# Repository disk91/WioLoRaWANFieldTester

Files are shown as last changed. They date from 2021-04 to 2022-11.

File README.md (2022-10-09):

# Wio Terminal LoRaWAN Field Tester

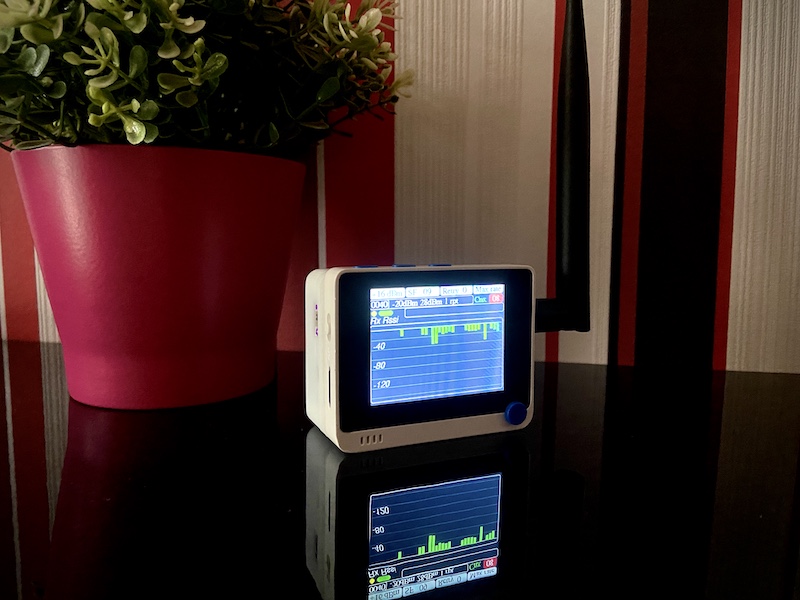
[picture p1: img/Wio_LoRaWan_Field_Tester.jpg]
LoRaWan tester


## What's is it about

When deploying a LoRaWAN network you want to know your gateway coverage and measure the radio performance in different places. When deploying Helium network you particularly want to know how many Hotspot around can be touched for a given position. Then you want to enrich the network mappers to know and share the real network coverage.

There are some existing tools for such application but the cost is about $200. The idea of this project is to propose a simple tool you can build on your own with low cost hardware to fulfil this purpose.

The solution is based on low cost products, easy to find for about $50:
- [Wio Terminal](https://wiki.seeedstudio.com/Wio-Terminal-Getting-Started/)
- [RFM95](https://www.disk91.com/2019/technology/lora/hoperf-rfm95-and-arduino-a-low-cost-lorawan-solution/)
- Quectel L80 / L86 GNSS

The solution also supports ready for use hardware:
- [Wio Terminal](https://wiki.seeedstudio.com/Wio-Terminal-Getting-Started/)
- [LoRaWan Chassis](https://www.seeedstudio.com/Wio-Terminal-Chassis-LoRa-E5-and-GNSS-p-5053.html)
- [Battery Chassis](https://www.seeedstudio.com/Wio-Terminal-Chassis-Battery-650mAh-p-4756.html)

`============================`

`If you are using a Seeed bundle, it is already setup, you don't need to do anything more`

`============================`

## How it works 

To get a better understanding on how WioLoRaWANFieldTester works, [read this page](doc/HowItWorks.md).

## Features
- Easy selection for Power / Sf / max retries
- Duty cycle status display
- Last setting flash memory backup
- Graph selection display
	- Rx Rssi - acked Rssi level 
	- Rx Snr - acked Snr level
	- Retries - number of retry before getting a ack
	- Tx Rssi - network side Rssi 
	- Hotspots - network side hotspot 
	- Distance - hotspot distance (in progress)
	- GPS status - current GPS status
- Manual / Automatic mode switch
- Display last frame information
- Network side RSSI / SNR / #of station
- Your favourite network splash screen (select in config.h)
- Screen shot and user guide
- RFM95 Schematics
- GPS position reporting with Helium mapper integration
- LiPo charging mode detection
- PCB available
- Enclosure available
- Serial port LoRaWan setup configuration
- End-user setup screen
- Setup with Cargo (helium tracking platform)
- Ready for industrial production with credential commissioning
- Support firmware upgrade w/o credential loss (LoRa-E5 only)
- Reduce uplink messages when device is not moving / out of coverage
- Discovery Mode - allow to see hotspot communications on a map (external website)
- Works with TTN and Helium
- Lock key & switched screen off mode

### Coming later features
- sdcard data storage

## Get your own device

The WioLoRaWANFieldTester board can be
- [Make](board/README.md)
- [Buy & DiY](https://shop.ingeniousthings.fr/products/helium-lorawan-field-tester-and-mapper-kit) as a kit
- [Buy](https://www.seeedstudio.com/Wio-Terminal-Chassis-LoRa-E5-and-GNSS-p-5053.html)

## Quick installation and setup

Read and follow the steps in [WioLoRaWANFieldTester configuration documentation](doc/SETUP.md)

## Use it

Read the [User Guide documentation](doc/UserGuide.md)

## Troubleshooting

### All frame "LOST" in US915 SF10

The US915 SF10 is restricting the size of uplink and downlink. Uplink is adapted but donwlink frame is currently too large. The Uplink are correctly sent but the "LOST" status is indicated when the Downlink is not received. So "LOST" is always displayed. 
Do not use SF10 in US915 if you want to get the uplink information. This will be fixed in a later version. Mapper and tracker features are working correclty even this.

### I can't change the factory setting

The Seeed bundle comes with ready to use credentials. You don't need to setup your device. If you want to move your device out of the factory credential and move the device to your own console account or TTN, you can follow the [documentation here](https://github.com/disk91/WioLoRaWANFieldTester/issues/34). Once done, you won't be able to rollback to factory settings.

### GPS never fixing (even outdoor)

Some of the LoRa-E5 chassis have an incorrect default UART speed at 115200. To reset it to the normal value, flash the firmware [Gps_Reset_To_9600bps](binaries/Gps_Reset_To_9600bps.uf2). Then you wait for about 1 minute and then reflash the latest version. This should fix it.

## Contribute to development

Read the [developer documentation](doc/DEVELOPMENT.md)

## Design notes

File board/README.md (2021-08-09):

# This folders contains the information to make your own board
- lorawan-tester.pdf is the schematics file
- lorawan-tester-20210429.zip is the gerber archive you can use asis with most of the PCB manufacturers

# Board versions

You can use this board in different versions:
* The LoRaWan only version, without GPS and powered by a USB-C battery connected on the WioTerminal. This version is really easy to realize as the number of component to solder is limited.
* The LoRaWan + GPS version, powered by the USB-C battery connected to the WioTerminal.
* The Full version, with GPS and LiPo charging circuit allows to access the full features including the Mapper information reporting. This version includes some CMS a bit complicated to solder.

A single PCB can support the three versions, it just depends on the components you decide to place on it.
You can order the board directly to different service on Internet:
- European PCB maker where the board can be accessed : [Aisler](https://aisler.net/p/MXYVQSVT)
- North American PCB maker the board can be accessed : [OshPark](https://oshpark.com/shared_projects/1TNqhC7U)
- Global you can access project on Seeed Fusion Gallery : [Seeed Fusion](http://www.seeedstudio.com/WioTermial-LoRaWan-Low-Cost-Field-tester-and-Helium-mapper-g-1331570)

**Kits available on [IngeniousThings shop](https://shop.ingeniousthings.fr/products/helium-lorawan-field-tester-and-mapper-kit)**

## Schematics

Take a look at *board* directory for details on PCB & components.

Here is the simplified version of the schematics for DiY implementation.
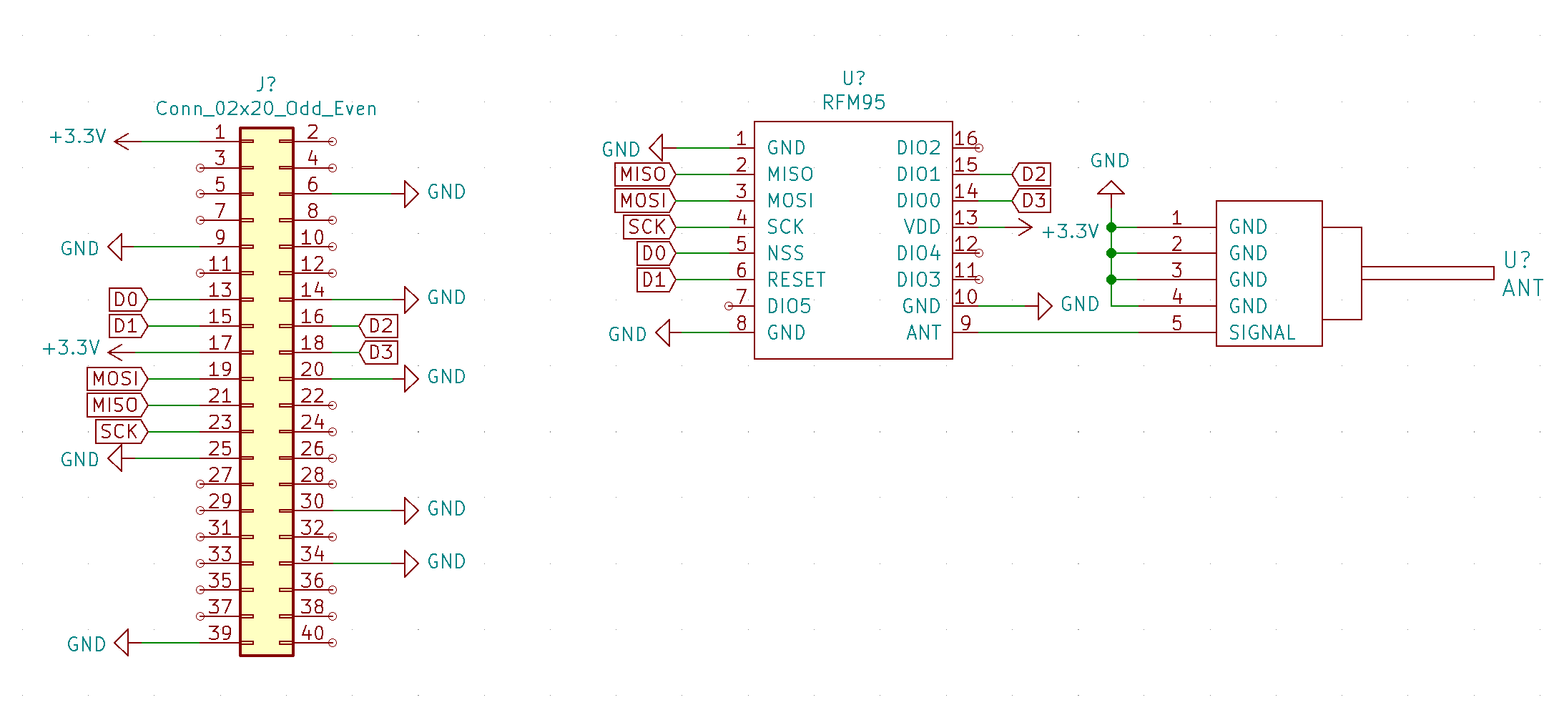
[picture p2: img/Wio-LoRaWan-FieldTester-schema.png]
basic schematic
 

# BOM

## LoRaWan only version
|Ref| Description |
|---|---|
|J1 | 40 pins (2x20) 2.54 header CMS |
|U2 | RFM95 (version 868MHz or 915MHz according to your zone) |
|R6 | 0 ohm 0603 resistor (a wire can be used) |
|U3 | Edge PCB 1.6mm SMA female connector |
| | 2x Screw 2mm x 16mm (see link in main README.md) 
| | 1x 868MHz antenna |

Estimated BOM price around $10

## LoRaWan + GPS version 
|Ref| Description |
|---|---|
|J1 | 40 pins (2x20) 2.54 header CMS (samtec TSM-120-02-L-DV) |
|U2 | RFM95 (version 868MHz or 915MHz according to your zone) |
|R6 | 0 ohm 0603 resistor (a wire can be used) |
|U3 | Edge PCB 1.6mm SMA female connector |
|M1 | Quectel L86 (L80 should be ok) |
|C3 | Capacitor 0.1uF 0603 CMS |
|C4 | Capacitor 4.7uF 0805 CMS |
|C1 | Capacitor 4.7uF 0805 CMS |
| | 2x Screw 2mm x 16mm (see link in main README.md) 
| | 1x 868MHz antenna |

Estimated BOM price around $20 

## Full version 
|Ref| Description |
|---|---|
|J1 | 40 pins (2x20) 2.54 header CMS (samtec TSM-120-02-L-DV) |
|U2 | RFM95 (version 868MHz or 915MHz according to your zone) |
|R6 | 0 ohm 0603 resistor (a wire can be used) |
|U3 | Edge PCB 1.6mm SMA female connector |
|M1 | Quectel L86 (L80 should be ok) |
|C3 | Capacitor 0.1uF 0603 CMS |
|C4 | Capacitor 4.7uF 0805 CMS |
|C1 | Capacitor 4.7uF 0805 CMS |
|D1 | LED CMS 0805 |
|U1 | MCP73831 (LiPo Charging Circuit) |
|R2 | 2 Kohm 0603 resistor |
|R4 | 1 Mohm 0603 resistor |
|R3 | 1 Mohm 0603 resistor |
|R1 | 1 Kohm 0603 resistor |
|J2 | JST 2mm LiPo Connector S2B-PH-K-S(LF)(SN)|
|S1 | Switch C&K - OS102011MA1QN1
| | 1x LiPo Battery 3.7V 500mAh - 1600 mAh with JST connector
| | 2x Screw 2mm x 16mm (see link in main README.md) 
| | 1x 868MHz antenna |

Estimated BOM price around $25 

When connecting a LiPo battery, please make sure of the battery polarity according to the polarity printed on the PCB. There is no rules about LiPo battery polarity.

# Enclosure

3D printed enclosure can be found in the [enclosure directory](../enclosure/). You will find the two parts of the enclosure in different STL files. You will also find the FreeCad source file in case you want to modify /improve it.

The enclosure is closed and attached to the WioTerminal with [2 screws DIN965, M2 L16mm](https://www.bricovis.fr/produit-vis-a-tete-fraisee-pozidriv-acier-zingue-blanc-din-965-tfzzn/#TFZ02/016ZN)

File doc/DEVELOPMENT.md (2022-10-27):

# How to compile and develop WioLoRaWANFieldTester

You can use WioLoRaWANFieldTester without a need to compile it by following the [Quick installation guide](SETUP.md). If you want to compile your proper version of it or if you want to contribute on the project by adding feature of fixing some bugs, here are the following steps.

## Required environment

The installation details are available in the related [Wio LoRaWan Field tester on disk91.com](https://www.disk91.com/?p=5187) 

### Required software components
* Arduino IDE
* WioTerminal - [Toolsuite](https://wiki.seeedstudio.com/Wio-Terminal-Getting-Started/)
* GPS - Adafruit GPS library version 1.5.4 (or 1.7.1)
* QRcode - from Richard More
* Flash - FlashStorage by various version 1.0.0 (this fixes seeed invalid FlashStorage bundled lib)

:warning: Remove any local library `TFT_eSPI` from your Arduino library folder, if not, it will use the local one with wrong pins definition resulting in black screen on boot. This library is included with Seeed SAMD package installed through Boards Manager.
```
https://files.seeedstudio.com/arduino/package_seeeduino_boards_index.json
```

#### RFM95 version
* LoRaWAN - MCCI LoRaWAN LMIC library (by IBM, Matthjs Kooljman…) version 3.3.0

#### LoRa-E5 version
* Battery Chassis - Sparkfun BQ27441

#### Later
* File system - Seeed Arduino FS version 2.0.3 (not yet implemented)
* File system - Seeed Ardunino SFUD version 2.0.1 (not yet implemented)

### Configuring the software components

#### For RFM95 version
LoRaWAN library needs to be setup for you local zone: 
  
- Edit the file **lmic_project_config.h** located in _Document/Arduino/libraries/MCCI_LoRaWAN_LMIC_library/project_config_

  You need to uncomment the line corresponding to your zone (us915, eu868...) and comment the others.
  Make sure the other defines are the same as above.
  ```C
  //
  // Select your radio zone and country
  //
  //#define CFG_eu868 1
  #define CFG_us915 1
  //#define CFG_au915 1
  ...
  #define CFG_sx1276_radio 1
  //#define LMIC_USE_INTERRUPTS
  #define LMIC_LORAWAN_SPEC_VERSION   LMIC_LORAWAN_SPEC_VERSION_1_0_2
  #define DISABLE_BEACONS
  #define DISABLE_PING
  ```

#### For LoRa-E5 version
You need to setup the Mode as Slave (because they did not correctly wired the Serial line on E5 so this is a trick to bypass this hardware problem)

Different setups needs to be performed in Libraries (so you know why I don't really like Arduino eco-system)
- In SoftwareSerial Library (Libraries/Arduino15/packages/seeeduino/hardware/samd/1.8.2/libraries/SoftwareSerial/), in SoftwareSerial.h, change the Buffer Size
```C
   #define _SS_MAX_RX_BUFF 128 // RX buffer size
```
- In `Wire.cpp` (Libraries/Arduino15/packages/seeeduino/hardware/samd/1.8.2/library/Wire/Wire.cpp), add in the following lines (they are conflicting with Wire from the same package) ( `&& defined FALSE` ). This is to wait a fix from Seeed on their package.
```cpp 
#if WIRE_INTERFACES_COUNT > 1
  TwoWire Wire1(&PERIPH_WIRE1, PIN_WIRE1_SDA, PIN_WIRE1_SCL);

  void WIRE1_IT_HANDLER(void) {
    Wire1.onService();
  }

  #if defined(__SAMD51__) && defined FALSE
    void WIRE1_IT_HANDLER_0(void) { Wire1.onService(); }
    void WIRE1_IT_HANDLER_1(void) { Wire1.onService(); }
    void WIRE1_IT_HANDLER_2(void) { Wire1.onService(); }
    void WIRE1_IT_HANDLER_3(void) { Wire1.onService(); }
  #endif // __SAMD51__
#endif
```

- In Adafruit_GPS_Library (Documents/Arduino/libraries/Adafruit_GPS_Library/src), in `Adafruit_GPS.h`, add the following define to allow SoftwareSerial
```C
#if defined ARDUINO_WIO_TERMINAL
#define ESP8266
#endif 
```

### Configure the WioLoRaWANFieldTester software

- The `config.h` file contains the configuration defines. Enable / Disable what you need

```C
//#define DEBUG                       // enable extra debug logs on serial
 
#define HWTARGET            LORAE5    // Select the target E5 vs RFM95

#define WITH_SPLASH         1         // Enable splash screen
#define WITH_SPLASH_HELIUM  1         //   display helium logo
#define WITH_SPLASH_TTN     1         //   display TTN logo

#define WITH_GPS                      // if defined the GPS code is enable
#define WITH_LIPO                     // if defined the LiPo status & charging code is enable

```

- The `key.h` file contains the LoRaWAN credential. When all set to 0, the device will expect a serial port configuration as seen in the setup.

When developing it is more convenient to use a static configuration to avoid reconfiguring the device on every firmware update. For this, you can get the credential as defined in the [Access Helium device credential for developer](ObtainCredsFromHelium.md) section of the documentation.

Then you can directly replace the **key.h** variable content with what you have copy & paste.

```C
#define __DEVEUI { 0x7B, 0xC9, 0xFF, 0x47, 0xE6, 0x49, 0x41, 0xA7 }
#define __APPEUI { 0xD3, 0x77, 0x5B, 0x2C, 0x39, 0x93, 0x58, 0x20 }
#define __APPKEY { 0xE5, 0xC1, 0xD9, 0x44, 0xB4, 0x0D, 0x5D, 0x1C, 0x8B, 0xFB, 0x14, 0x8B, 0x1E, 0x8C, 0x2C, 0xA5 }
```

### Modify and Compile

There is nothing specific about compilation & upload. If you add feature or fixing bug in you private fork, don't forget to propose a pull-request.

### Creating UF2 files

If you want to create an UF2 file for a drag & drop upload on the WIO Terminal, you can use [uf2 generator](https://seeedjp.github.io/uf2/) online tool. 
* use address 0x4000
* select your binary file compiled from Arduino
* download the file locally

## Frame format

The following Frame format are used:
**uplink format on port 1:**
| Byte | Usage |
|---|---|
| `0 - 5` | GSP position see [here](https://www.disk91.com/2015/technology/sigfox/telecom-design-sdk-decode-gps-frame/) for details. Decoding see below |
| `6 - 7` | Altitude in meters + 1000m ( 1100 = 100m ) |
| `8` | HDOP * 10 (11 = 1.1) |
| `9` | Sats in view |

When the GPS position is invalid of GPS is disable, the frame is full of 0

**downlink response format on port 2:**
| Byte | Usage |
|---|---|
| `0` | Sequence ID % 255 |
| `1` | Min Rssi + 200 (160 = -40dBm)  |
| `2` | Max Rssi + 200 (160 = -40dBm)  |
| `3` | Min Distance step 250m |
| `4` | Max Distance step 250m |
| `5` | Seen hotspot |

The distance is calculated from the GPS position and the hotspot position returned by console meta-data. Under 250m value is 250m, over 32km value is 32km. 0 is considered as invalid response

The following integration and payload transformation allows to decode the gps position and report is to mapper. Thank you Seb for the contribution.

**Dicovery uplink format on port 3 (no ack):**
| Byte | Usage |
|---|---|
| `0 - 5` | GSP position see [here](https://www.disk91.com/2015/technology/sigfox/telecom-design-sdk-decode-gps-frame/) for details. Decoding see below |

Discovery is sending 10 messages SF10 on every 40 seconds. All the other information comes from the metadata provided by the network server.

## Decoder for the frame format

Such a decoder can be use if you do not want to use my backend to report the coordinate to the helium mapper

Create a _Functions_ type _Decoder_ / _Custom Script_ and attach it to a mapper integration callback as it is described in this [helium mapper integration page](https://docs.helium.com/use-the-network/coverage-mapping/mappers-quickstart/)

```js
/*
  Helium console function for LoRaWan Field Tester sending mapping information to mappers backend.

  https://www.disk91.com/2021/technology/lora/low-cost-lorawan-field-tester/

  Result is visible on https://mappers.helium.com/

  Built from information available on:
    https://docs.helium.com/use-the-network/coverage-mapping/mappers-api/
    https://github.com/disk91/WioLoRaWANFieldTester/blob/master/WioLoRaWanFieldTester.ino
    https://www.disk91.com/2015/technology/sigfox/telecom-design-sdk-decode-gps-frame/

  Integration:
    POST https://mappers.helium.com/api/v1/ingest/uplink
*/

function Decoder(bytes, port) { 
  var decoded = {};
  // avoid sending Downlink ACK to integration (Cargo)
  if (port === 1) {
    var lonSign = (bytes[0]>>7) & 0x01 ? -1 : 1;
    var latSign = (bytes[0]>>6) & 0x01 ? -1 : 1;
    
    var encLat = ((bytes[0] & 0x3f)<<17)+
                 (bytes[1]<<9)+
                 (bytes[2]<<1)+
                 (bytes[3]>>7);
  
    var encLon = ((bytes[3] & 0x7f)<<16)+
                 (bytes[4]<<8)+
                 bytes[5];
    
    var hdop = bytes[8]/10;
    var sats = bytes[9];
    
    const maxHdop = 2;
    const minSats = 5;
    
    if ((hdop < maxHdop) && (sats >= minSats)) {
      // Send only acceptable quality of position to mappers
      decoded.latitude = latSign * (encLat * 108 + 53) / 10000000;
      decoded.longitude = lonSign * (encLon * 215 + 107) / 10000000;  
      decoded.altitude = ((bytes[6]<<8)+bytes[7])-1000;
      decoded.accuracy = (hdop*5+5)/10
      decoded.hdop = hdop;
      decoded.sats = sats;
    } else {
      decoded.error = "Need more GPS precision (hdop must be <"+maxHdop+
        " & sats must be >= "+minSats+") current hdop: "+hdop+" & sats:"+sats;
    }
    return decoded;
  }
    return null;
}
```

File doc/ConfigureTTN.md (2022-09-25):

# Configure device in the TTN console

This describes how to link the WioLoRaWanField tester with TTN network.

## Create an application

The first step is to create an application in TTN console. You can name it the way you want, like _wioLoRaWanFieldTester_.

In this application, you need to create an API key.

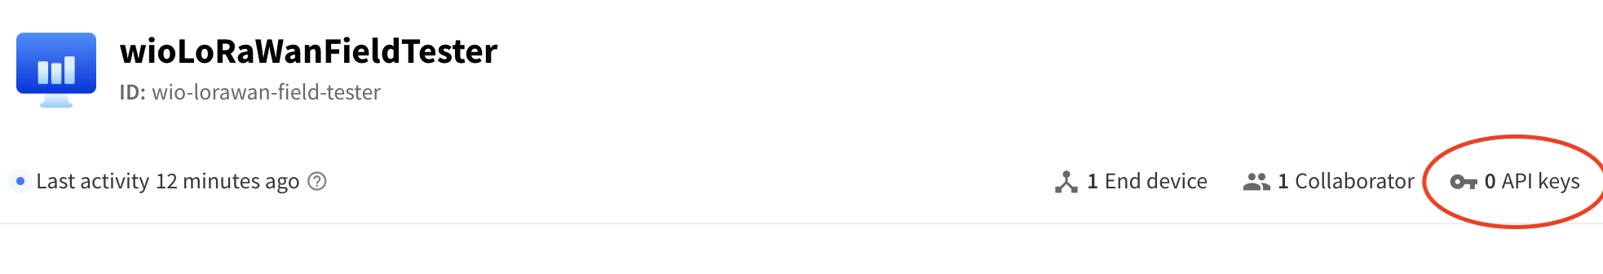
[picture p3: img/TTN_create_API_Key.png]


Give it a name, select a date in the future, select the __Write downlink application trafic__ right for it. 

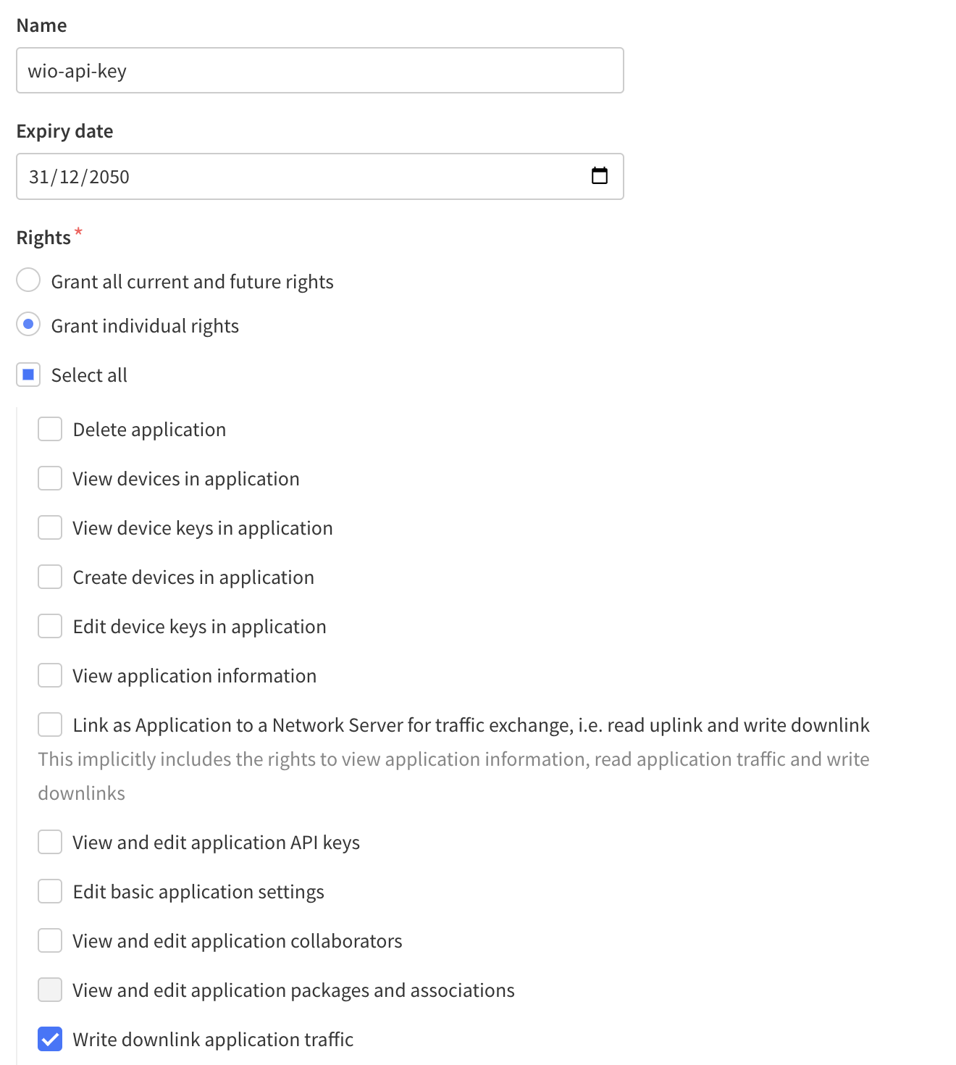
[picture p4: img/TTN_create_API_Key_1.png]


Once you have validate this, you reach the last page with the API key created. Copy the key into the clipboard and save it, we will need it in the coming step. Don't forget to add the right to _write donwlink application traffic_ on it.

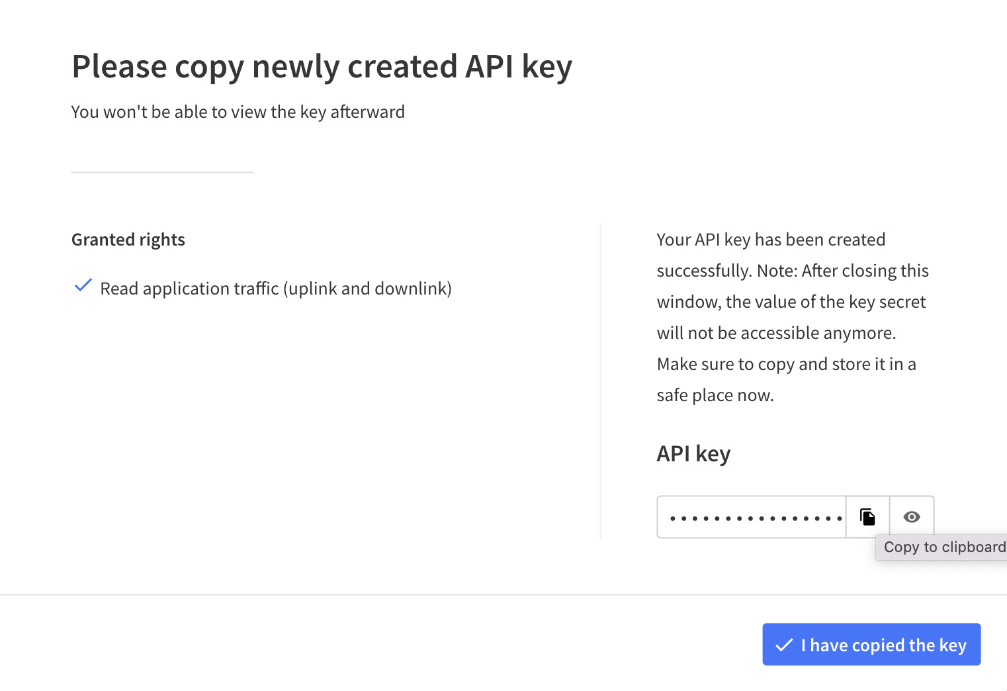
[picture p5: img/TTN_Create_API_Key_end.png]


## Add a integration type WebHook

Now we are going to create an integration using a webhook with the backend on disk91.com. This backend is computing the information displayed on the Wio.

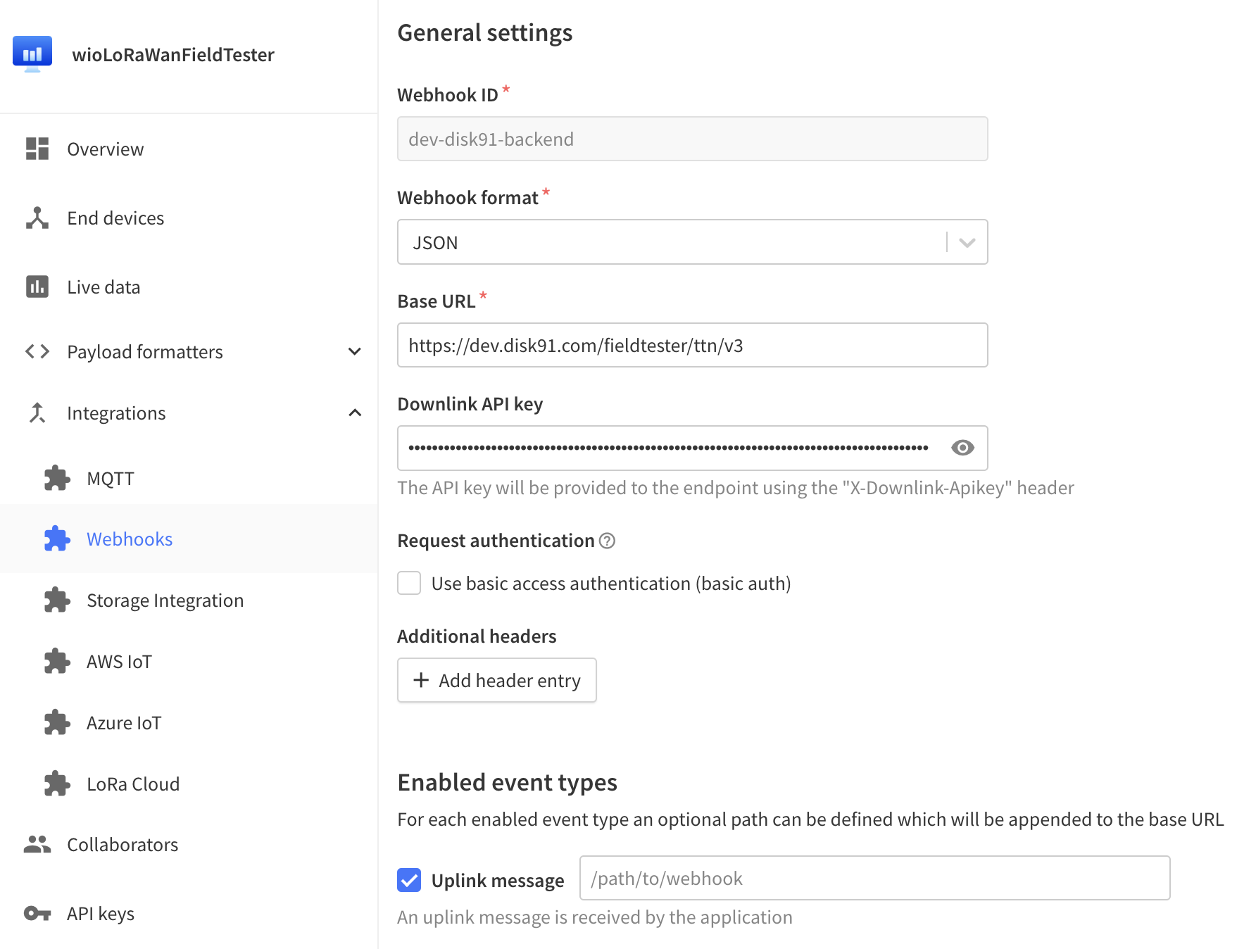
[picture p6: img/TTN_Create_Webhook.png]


The base URL to be used is : `https://dev.disk91.com/fieldtester/ttn/v3`

You need to copy the API key, previously saved, into the Downlink API Key field.

Check the __Uplink message__ event type to activate.

## Create your device

Now you can create your device into this application and get your credentials.

The Application EUI is by default set to 00..00, you need to change this to anything else to be able to configure your WioLoRaWanFieldTester. You can recompile writing your keys on keys.h or restart the device pressing the 5 direction button. After 1 second after rebooting, stop pushing the 5 direction button, you should see the setup screen displayed and you can change the keys.

Use Lora Specification 1.0.3 for LoRa-E5 modules (you can select Seeed Technology and Wio-E5 Dev Kit).

Then you are ready to start mapping.

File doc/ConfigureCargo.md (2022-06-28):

# Configure cargo

## Cargo integration

[Cargo](https://cargo.helium.com/) is a tool from Helium to display real-time tracking device position on a map. This tool displays your position publicly but is really easy to use. As is also displayed the coverage map as an extra layer, it is a useful tool to find the hexagon not yet tested to complete the coverage map.
In this tool, you will search your device by its name, the use of a unique name will help you to find it.

To make Cargo working with WioLoRaWANFieldTester, we need to create a decoding function to pass it the device coordinate in the right format.

## Setup a decoding function

Create a decoding function from the [Helium console](https://console.helium.com) dashboard. Click on the **+** button and select **Add function**

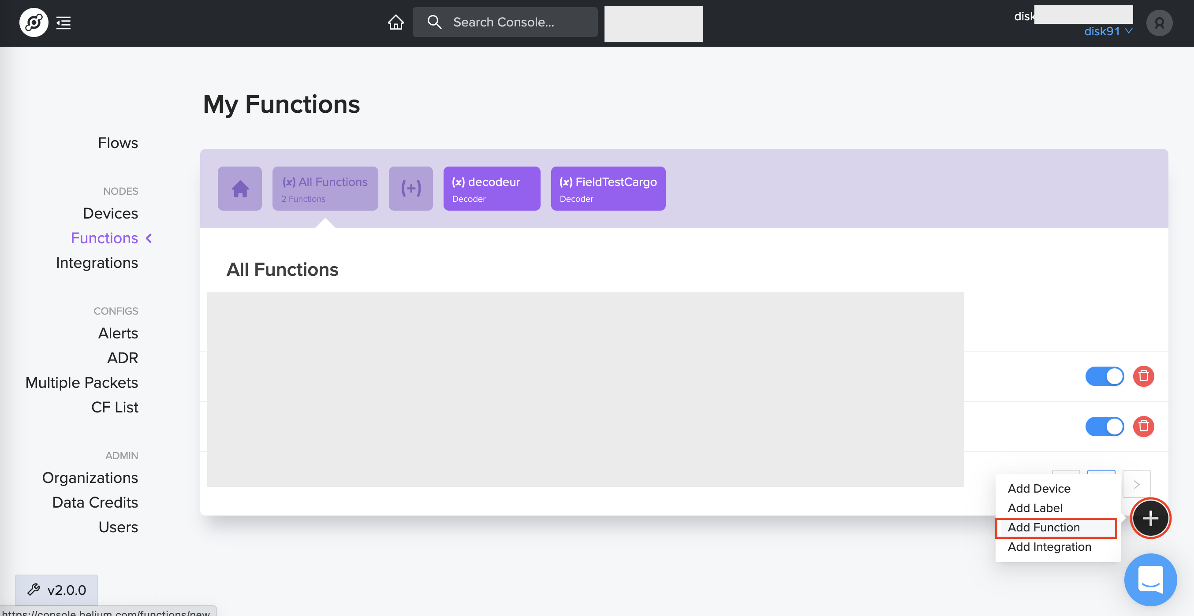
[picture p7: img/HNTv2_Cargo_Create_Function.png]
Helium create new function


Once in the **Add function** screen, you need to give it a name:

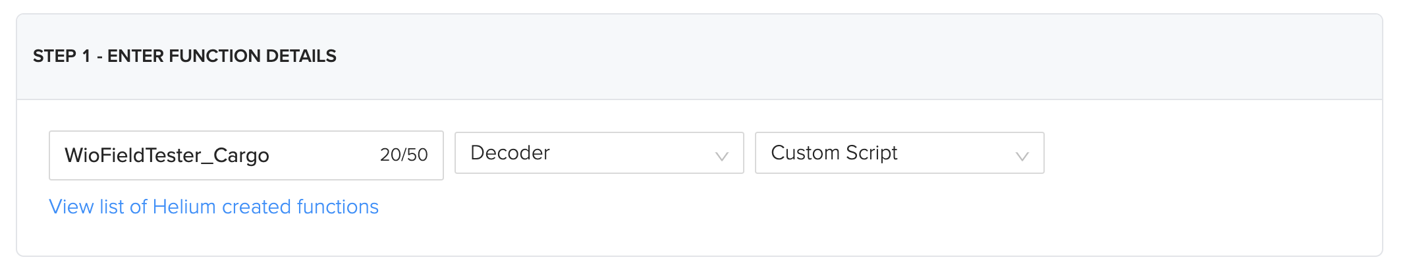
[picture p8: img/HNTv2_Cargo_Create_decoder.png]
Helium create new function


Then you can type the decoder function. This function will proceed the payload received from the device and convert it in a structure the Cargo application is able to understand.

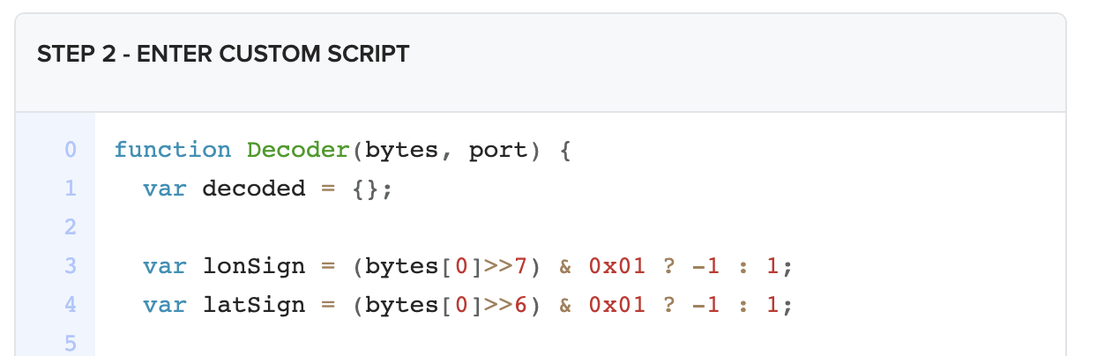
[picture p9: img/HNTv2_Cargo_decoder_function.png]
Helium create new decoder


Copy & Paste the following JS content into the decoder textarea:

```
function Decoder(bytes, port) { 
  var decoded = {};
  
  if ( port != 1 ) return decoded;
  
  var lonSign = (bytes[0]>>7) & 0x01 ? -1 : 1;
  var latSign = (bytes[0]>>6) & 0x01 ? -1 : 1;
  
  var encLat = ((bytes[0] & 0x3f)<<17)+
               (bytes[1]<<9)+
               (bytes[2]<<1)+
               (bytes[3]>>7);

  var encLon = ((bytes[3] & 0x7f)<<16)+
               (bytes[4]<<8)+
               bytes[5];
  
  var hdop = bytes[8]/10;
  var sats = bytes[9];
  
  const maxHdop = 2;
  const minSats = 5;
  
  if ((hdop < maxHdop) && (sats >= minSats)) {
    // Send only acceptable quality of position to mappers
    decoded.latitude = latSign * (encLat * 108 + 53) / 10000000;
    decoded.longitude = lonSign * (encLon * 215 + 107) / 10000000;  
    decoded.altitude = ((bytes[6]<<8)+bytes[7])-1000;
    decoded.accuracy = (hdop*5+5)/10
    decoded.hdop = hdop;
    decoded.sats = sats;
  } else {
    decoded.error = "Need more GPS precision (hdop must be <"+maxHdop+
      " & sats must be >= "+minSats+") current hdop: "+hdop+" & sats:"+sats;
  }

  return decoded;
}
```

## Setup Cargo integration

Now you need to create an Integration with Cargo, for this, create a new integration

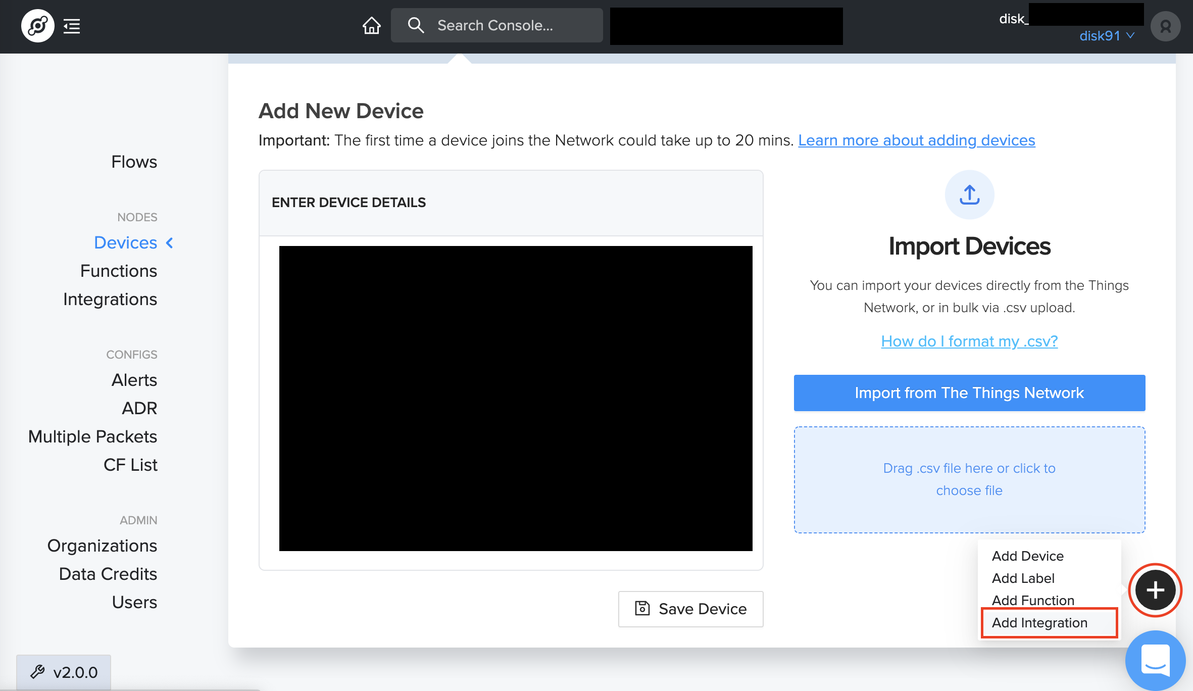
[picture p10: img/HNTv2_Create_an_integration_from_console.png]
Helium create new integration


You need to select the type of integration, here it is **Cargo**:

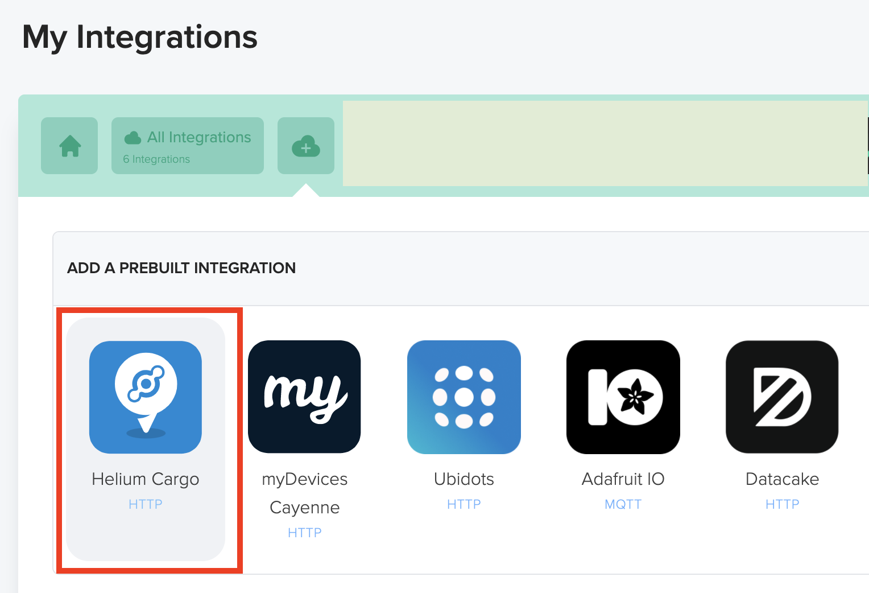
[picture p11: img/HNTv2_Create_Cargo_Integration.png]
Helium create new Cargo integration


Please read the warning about data privacy and accept it if you agree on the terms:

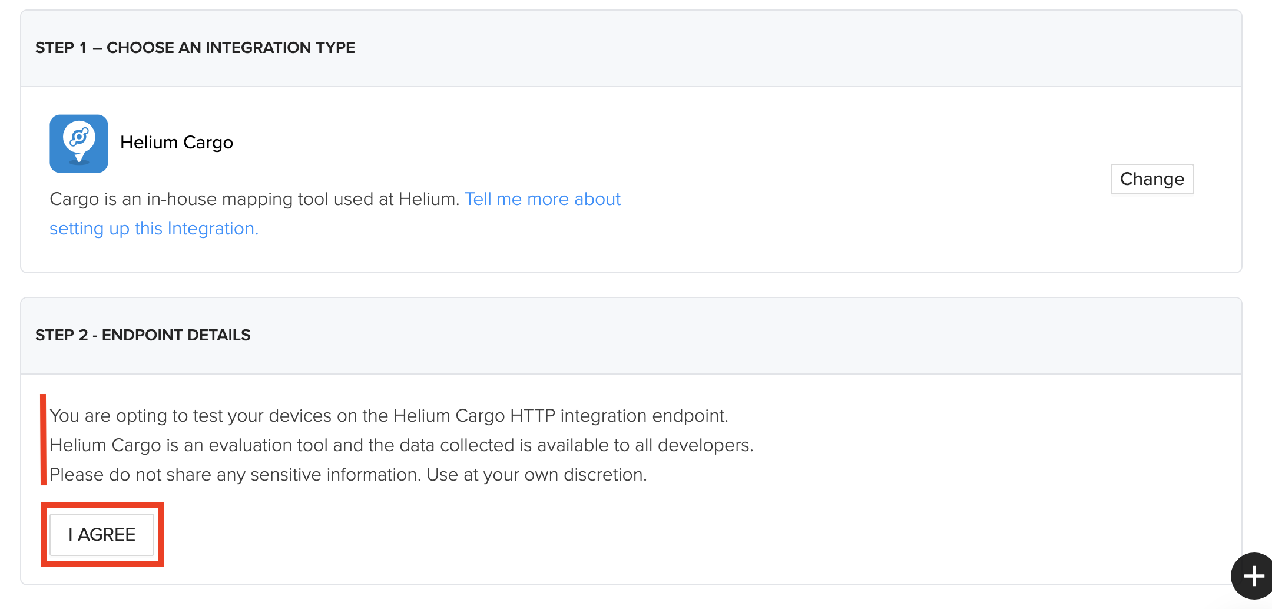
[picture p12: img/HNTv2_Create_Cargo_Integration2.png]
Helium create new Cargo integration


Now you can give a name to this integration:

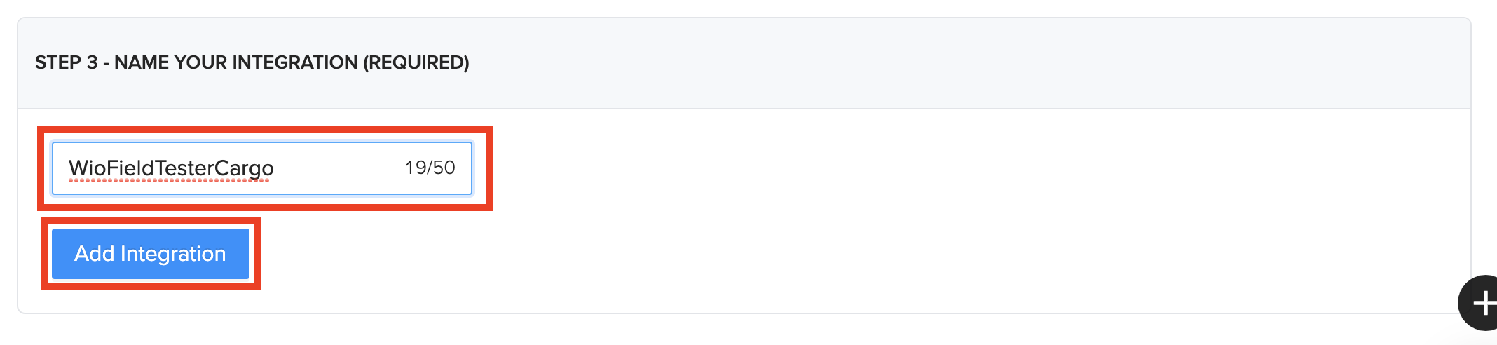
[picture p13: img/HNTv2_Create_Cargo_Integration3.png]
Helium create new Cargo integration


As you can see, we do not need to give details about the integration endpoint, by selecting Cargo integration, the console automatically knows how to transfer the informations. 

## Setup Cargo flow

Now, you need to make the link between our **Label**, the created **Function** and the Cargo **Integration**.
For this you, go the the **Flow** panel:

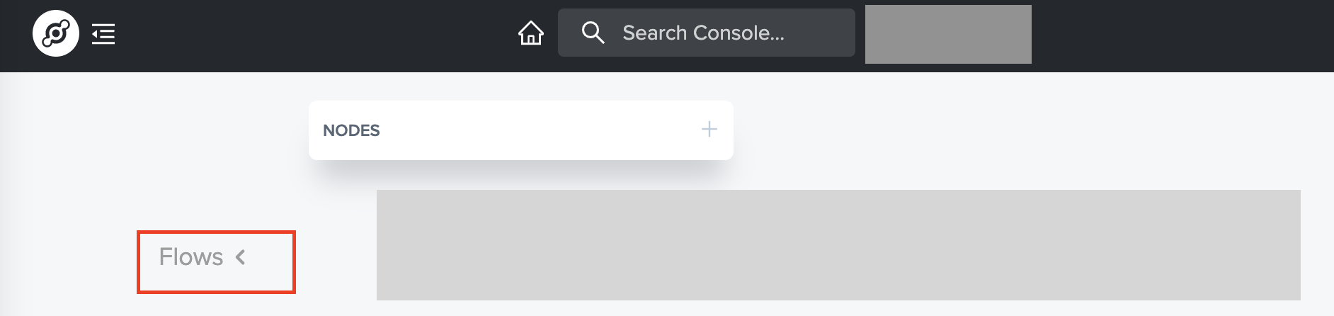
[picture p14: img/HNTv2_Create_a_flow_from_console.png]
Helium create new flow


Once in it, you can extend the Node to access the different tabs:

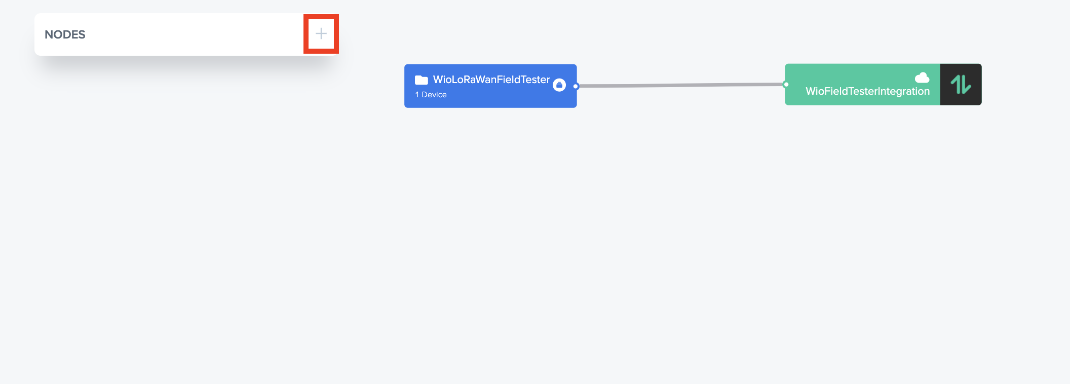
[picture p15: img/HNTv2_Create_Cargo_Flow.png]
Helium modify a flow


Then you need to insert the **Function** previously created by selecting the Function tab, then drag & drop the created function into the flow diagram:

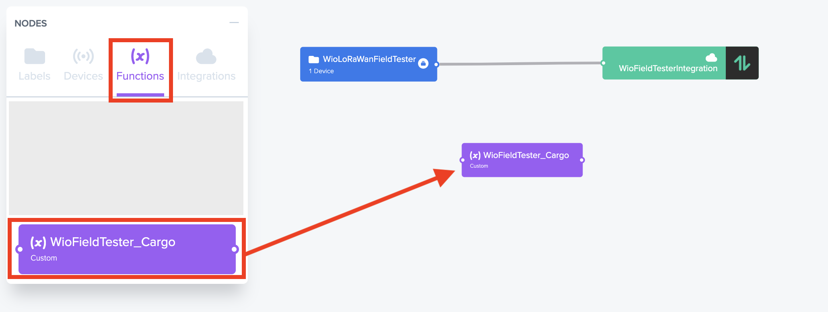
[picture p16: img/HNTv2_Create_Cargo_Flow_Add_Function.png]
Helium modify a flow


Then you need to do the same with the Cargo **Integration**. Select the Integration tab and drag & drop the Cargo integration you previously created.

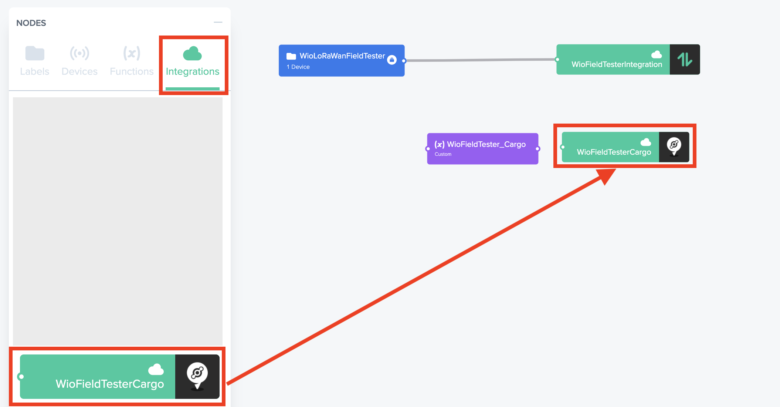
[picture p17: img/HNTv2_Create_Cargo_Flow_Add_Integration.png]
Helium modify a flow


All these components, now, need to be linked together to create the flow. Click on the node's connectors and drag your mouse up to the destination.

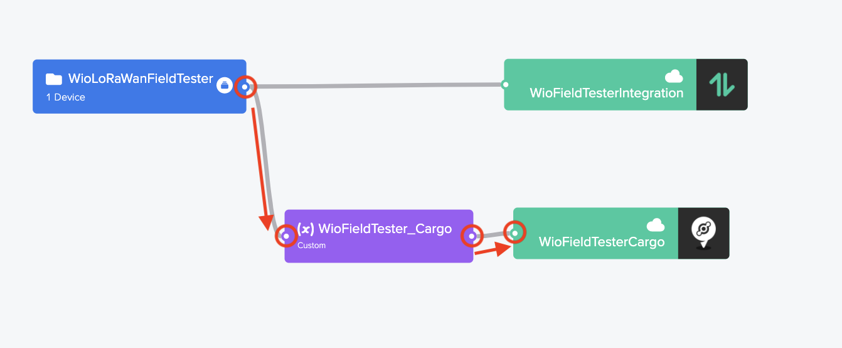
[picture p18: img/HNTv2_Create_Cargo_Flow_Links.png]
Helium modify a flow


To make sure all these changes will be applied, don't forget to **Save** your changes:

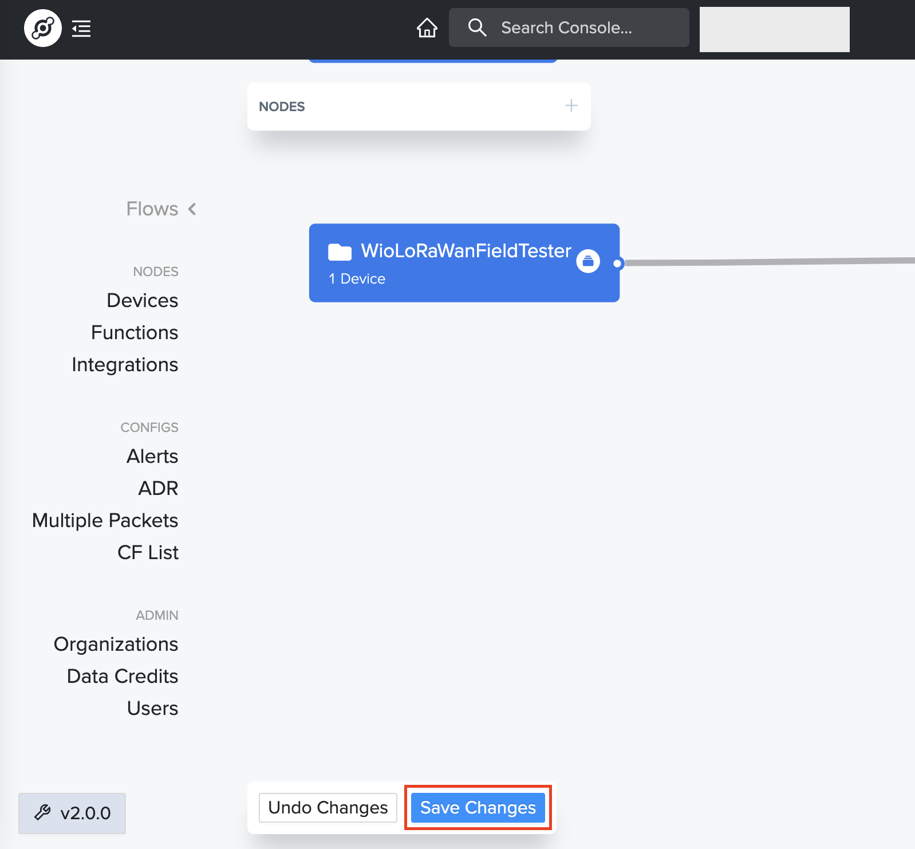
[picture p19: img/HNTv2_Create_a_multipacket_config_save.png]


## Your Cargo setup is **DONE** you can go back to [installation page](SETUP.md) for the next steps

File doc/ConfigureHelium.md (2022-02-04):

# Configure device in the Helium console

This describes the different steps to configure the device on the [Helium](https://www.helium.com) network.

## Join Helium console

Skip if you already have an account on helium console.

You need to create an account on the [Helium console](https://console.helium.com). This is free and you get 10.000 Data Credit (DC) for the registration. This is large enough to start for a couple of month to year of device use. You can later buy extra DC, 100.000 DC correspond to $1.

Once you have your account created, you can register your device. We are going to create a Label: this is basically a group of devices where common settings apply. Then we will create a Device to get the required credentials to identify the device. This device will be attached to the label.

Then we are going to create an integration with WioLoRaWANFieldTester backend. As explained in [How it works](HowItWorks.md) page, this allows the device to receives computed informations from the network and automatically report the coordinated to the [helium mapper](https://mappers.helium.com)

## Create a Label

From the Helium console dashboard, click on the **+** icon and select **Add label**

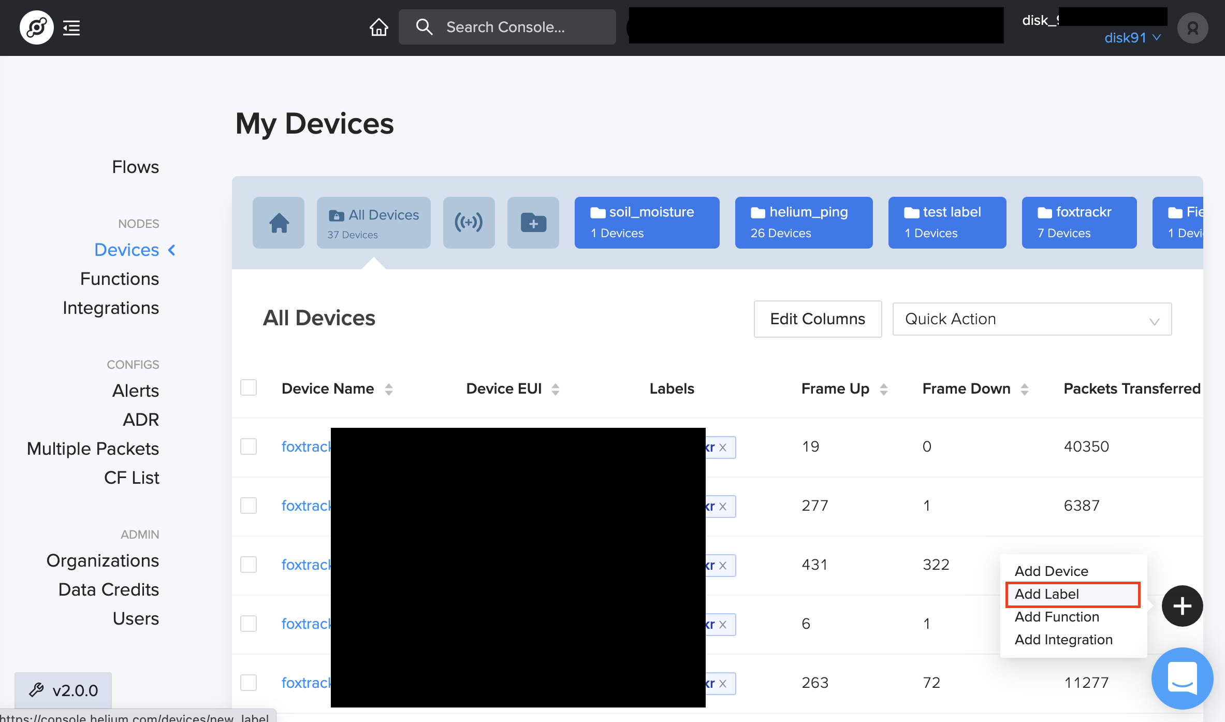
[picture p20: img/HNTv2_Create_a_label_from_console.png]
Helium label creation


Then, enter a *Label* name and **Save** it.

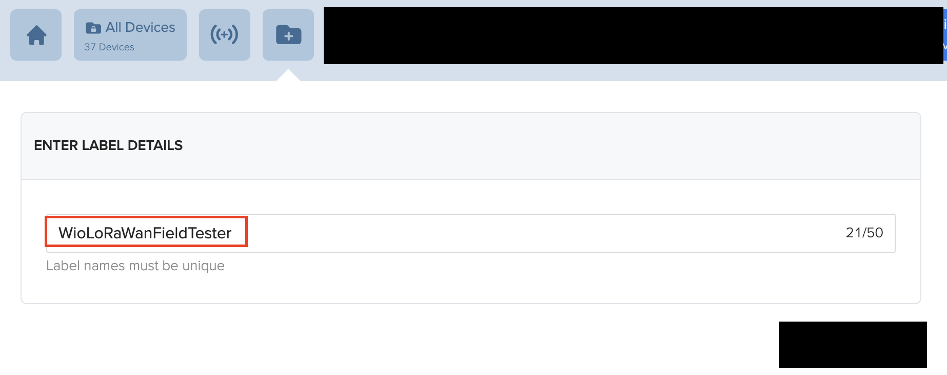
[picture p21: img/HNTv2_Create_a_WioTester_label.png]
Helium label creation details


## Create a Device

From the Helium console dashboard, click on the **+** icon and select **Add device**

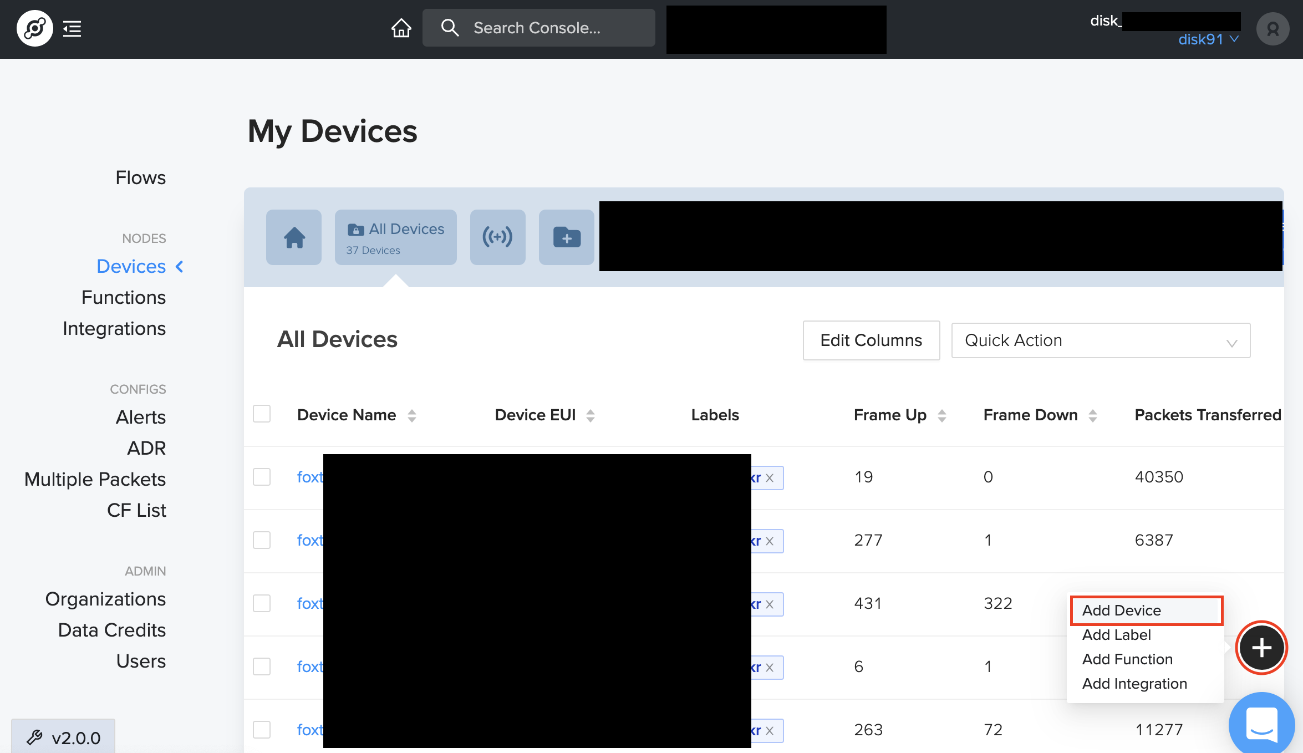
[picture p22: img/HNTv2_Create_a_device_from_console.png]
Helium device creation


Then, enter a **Name** and Search the **Label** you created previously to make the attachment. You need to click on the Label name once displayed to add it in the form field. Then Save.

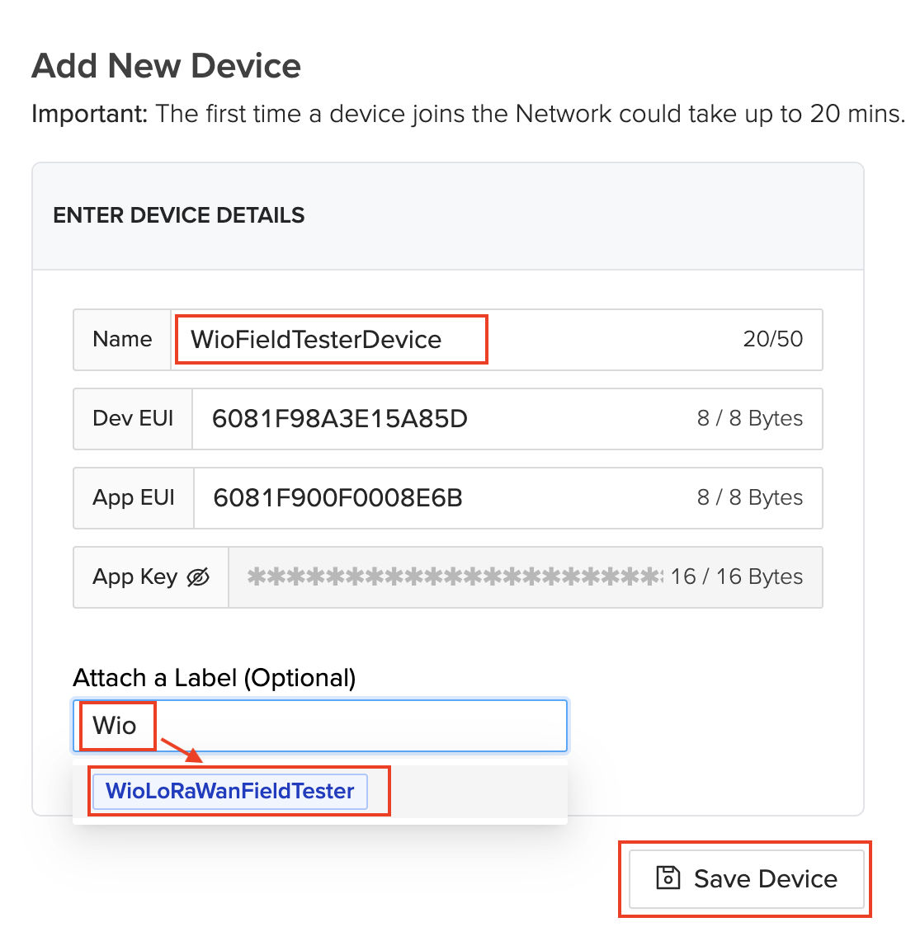
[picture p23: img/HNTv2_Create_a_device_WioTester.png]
Helium device creation details


Here you can see the device credential. There is no need to save them during this step, we will later see how to get and use them to setup the device.

## Create the Integration

From the Helium console dashboard, click on the **+** icon and select **Add integration**

Helium Add Integration

The integration is **HTTP** type, it means the data will be redirected to a custom URL. You can get details on this in the [How it works](HowItWorks.md) page.

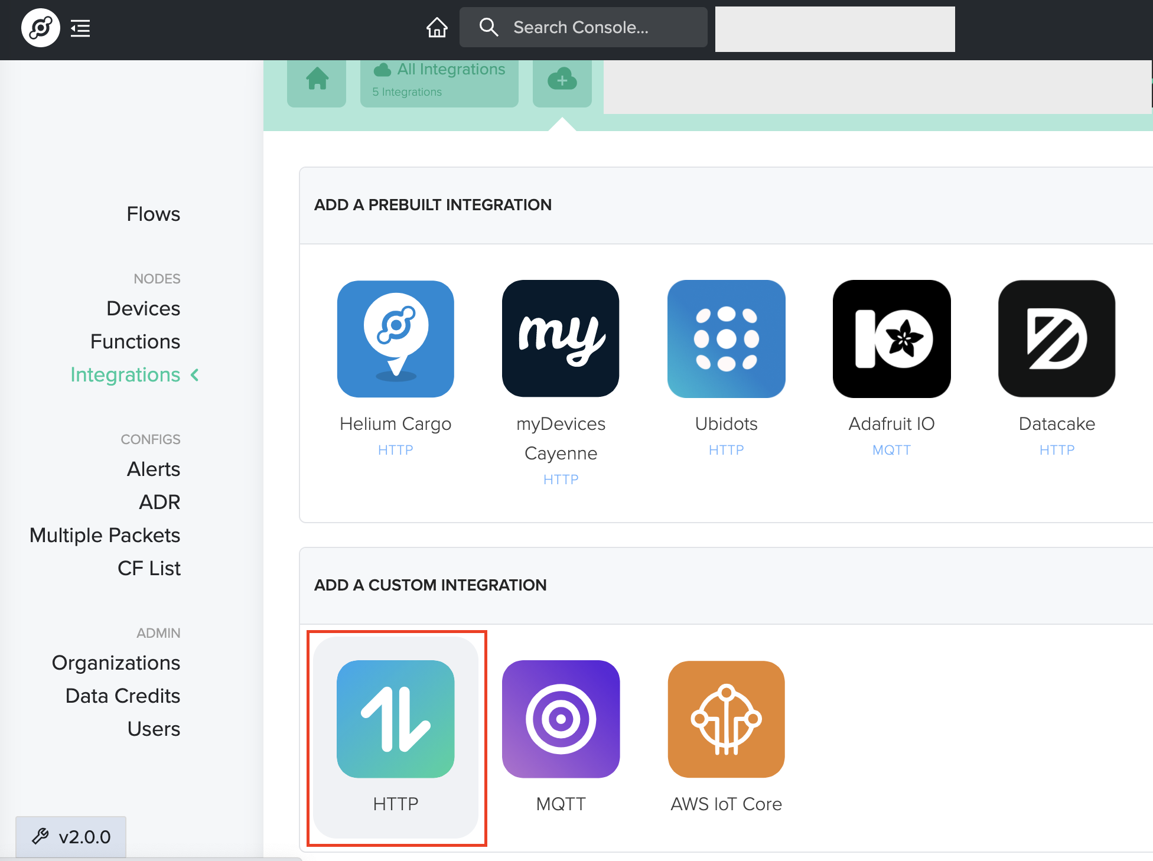
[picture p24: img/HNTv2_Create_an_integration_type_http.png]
Helium Integration type HTTP


Now you need to setup the integration by entering the target endpoint. Ensure the type is **POST** and enter as Endpoint URL: 
```
https://dev.disk91.com/fieldtester/helium/v3
```
At the end of the form, enter a name of your choice for this integration and click on **Add Integration**

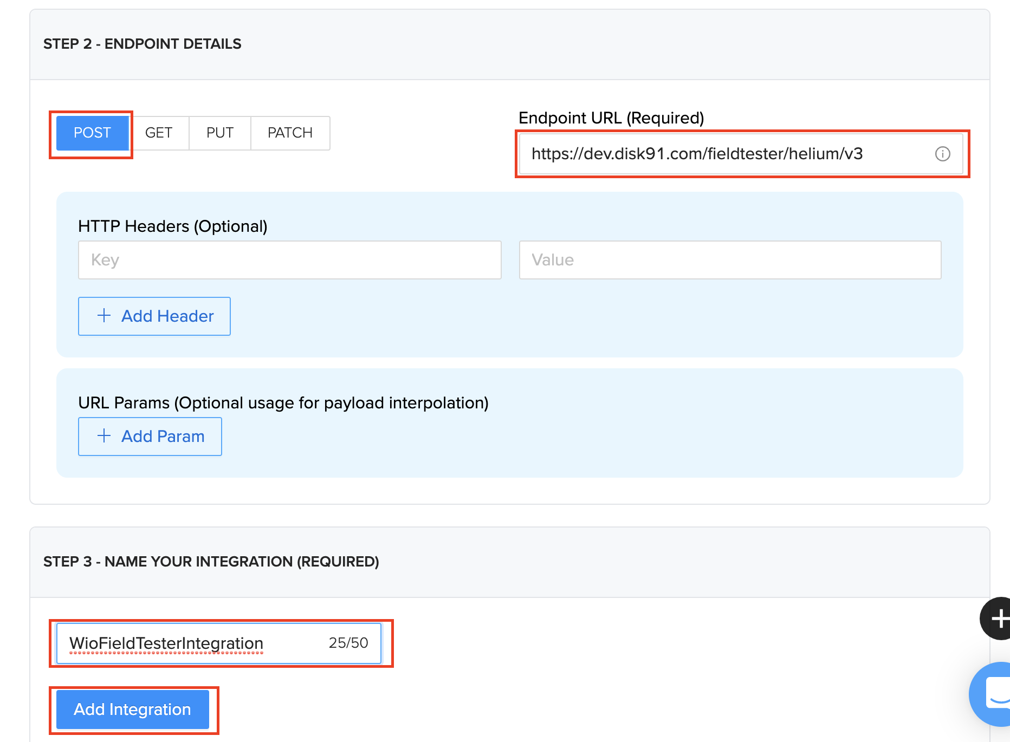
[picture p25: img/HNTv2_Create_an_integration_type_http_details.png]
Helium Integration HTTP details


## Create a flow to link the Integration with the Label

We need to create a link between the Label and the Integration. Thanks to this, the Helium router will know that any data coming from one of the devices of the given Label will need to be transferred to the custom backend on dev.disk91.com.

From the console Dashboard, click on **Flow** to access the setup page.

Helium flow creation

From the flow page, click on **Nodes** to extend the object's panel, then select **Labels** tab and drag & drop the Label you created previously to the flow page background.

Helium add a label in a flow

Then you can select the **Integrations** tab and drag & drop your previously created integration to the flow page background.

Helium add an integration in a flow

Now, you need to link the Label to the Integration, for doing this, click on the Label connector (circle on the right of the Label) and drag your mouse to the Integration connector (on its left). It should be like the picture above.

Helium flow link label to integration

## Configure the Label to buy all the replicate packets

Basically on Helium network, even if all the Hotspots around receives the Data, only one of them is basically bought by the Router to one of the Hotspot. This is because, one single frame is enough if you are only interested by the data transported. 
If you want to obtain more informations about the local network like the list of hotspot having received the message, you need to ask the router to buy more replicates of that frame coming from different Hotspots. Thanks to this, we will be able to display on the device a range of signal straight and the number of hotspot having received the message.
As a consequence, each message processed will cost 1DC each (plus ack cost). 
If you want to preserve your DC spend you can limit the number of messages bought by router.

You also need to know that currently the router, most of the time, only returns 1 message, even if many other exists. It is still under investigation by Helium.

To configure the number of packets to be bought, you need first to create a **Multiple Packets** configuration.
Give it a name and select the number of packets (replicates) you want to buy as a maximum. Then create this configuration.

Helium multi-packets configuration

Now we need to associate this configuration to the Label on the **Flow** page

Helium flow creation

Then click on the **Label** displayed on the Flow background page to edit its setting. Select the **Packets** tab and in this page, enable the corresponding **Multi-packets** configuration.

Helium Label multi-packets association

After doing this, you need to **Save** the flow settings.

Helium Flow save

## Next steps

Go back to [installation page](SETUP.md) to continue the configuration

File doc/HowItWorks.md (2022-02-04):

# Understand how WioLoRaWANFieldTester works

## Principles

The WioLoRaWanFieldTester provides different features, all-in-one:
- Field Tester - it allows to monitor the LoRaWan / LongFi network performance from the field. That way you can verify the coverage and know the different Gateways / Hotspots covering a given place. It helps to find the best places to deploy new Gateways / Hotspots, compare different places to optimize the network deployment.
- Mapper - it automatically transfer the positions to the network mappers - [helium](https://mappers.helium.com) and [coveragemap](https://coveragemap.net/) - to create a map of coverage. This map is really important to understand where it is possible to use the network. It is a key point for giving trust on the network and motivate the service providers to use it.
- Tracker - it can be connected to tracking services like [cargo](https://cargo.helium.com) to track cars, people, assets in real time.

For doing this, the terminal is connecting to the network and sending messages on regular basis. The onboarded GPS is getting the device position in real time. This message is acknowledged by the network to retrieve the information requested for field testing.
Then, each of the messages are processed by a dedicated application computing advanced Field Testing information later transmitted back to the device.
When the GPS signal quality is correct, the location is transferred to the mappers and tracking services.

All the Field Testing information are displayed on the Wio Terminal screen where you can also setup different radio parameters.

## Architecture
The solution involves different components:

- The WioTerminal, sending the communication and displaying the results
- The gateways / Hotspot receiving the traffic
- The network server relaying the traffic to the application server and enriching with the network signal informations
- The application server, building the downlink message for returning the network signal information to the Wio Terminal.

Here you can see a schema of the different communications between these components:

WioLoRaWANFieldTester Architecture

... and the way, they are interacting over time:

WioLoRaWANFieldTester Architecture

(1) The device sends messages on regular basis based on the selected strategy (max rate, 1 minute...)
	Each of the messages can be lost over the air, based on the repeat setting, the device will retry the same message until it gets a ACK from the network.

(2) When the message is received by the network, the network respond with an ACK to confirm reception. 
	The device, when receiving this response gets the reception radio levels (RSSI - Signal Strength and SNR - Signal over Noise)

(3) In parallel, when the message is received by the network, the network process the message data.
	These data are pushed to a dedicated backend server deployed to process these data. The most important point in this step is that the network server add Meta-data to the message data. As part of these meta-data, it adds the list of Gateways / Hotspot having received the message. That way, the backend server can determine the number of Gateways / Hotspots covering a single zone including the signal strength for each of them.

(5) The meta-data result is returned to the device to be on-field displayed.
	The backend server computes a response to the device with the number of hotspots having received the message and the signal lower and higher limits. These data will be pushed back to the device through a downlink communication. The device will later display these information in the different screens.

(5b) The device position is pushed to the mapper services.
	When the position quality is good enough (hdop quality is under 2.0 and satellites in view over 5), the backend server is pushing these informations to the associated mapper automatically. This helps to construct community coverage map. Helium mapper and Coveragemap service are transparently connected.

(6) The device now looks for pending downlinks by querying through a new uplink communication. 
	When the device is max rate mode, this step (6) is integrated to the next step (1). In the other mode, the step (6) is following the step (5).

(7) The network responds with a downlink containing the information computed by the backend server.
	When downlinks are pending, the network sent it. The device process the data to enrich the different boards and if multiple downlink are pending, it gets them all.

See more details on how it works on [Wio LoRaWan Field tester on disk91.com](https://www.disk91.com/?p=5187) 

## Network Server

The network server, also named *console* or *router* for Helium network is configured to process the data and transfer them to the backend server. The [setup documentation](SETUP.md) describes the way it works.

## Backend Server

The backend server is free to use, the endpoint is documented in the *setup guide*. The source code of the server is not provided because as it is deployed on a multi-purpose IoT backend server it is currenlty too much complicated for me to extract its code for a standalone use and open-source this.

You can easily create your own backend server, if you do not want to use the one I'm offering, as the message format are documented in the [developer guide](DEVELOPMENT.md)

The WioLoRaWan field tester can also works without the backend server:
- You can get the network information (2) without it
- You can directly connect the network server to the mapper without passing through the backend server.

## Running cost and fair use

- When running the WioLoRaWANFieldTester on TTN, you need to respect the [fair-use policies](https://www.thethingsnetwork.org/docs/lorawan/duty-cycle/). Basically, you should only use the manual mode and a maximum of 10 tests / days due to the downlink limitation. There is nothing blocking over this.
- When running the WioLoRaWANFieldTester on Helium, there is no fair-use policies but each communication has a cost in DC. 100.000 DC costs $1 per design. A communication consists in an Uplink, a Downlink or a Repeat. Intensive usages can have a significant cost. Classical use is about 2000 messages / month - $0.05

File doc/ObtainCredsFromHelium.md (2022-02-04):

# Obtain your device credential from [Helium console](https://console.helium.com)

You have previously created a device in the helium console. Now we need to setup the device with the created credentials. These credentials will be used in the next step and transferred to the device.

## Access the device credentials (Quick install)

From the [console dashboard](https://console.helium.com), access the device page and search for your device. Click on its name to get the details.

Helium access device details

Once you are on the device page, you can access the device credentials. For the standard use of them, you need to get the hexadecimal string of each of the credentials. For this, you can directly use the **Copy to clipboard** icon to get each of the credentials. The DevKEY is displayed clicking on the **eyes** icon before using the **copy to clipboard** icon.

Helium device credentials

## Next steps

Go back to [installation page](SETUP.md) to continue the configuration

## Access the device credentials (For developers)

This is only for developer, quick install do not requires to care about this part.
Developers can prefer to force certain credentials instead of re-configuring the device after each firmware upload. In this case, the file key.h can be modified to contain the device credentials.

To get these credential, access the device detail page the same way as previously.

Then, Click on the the **C table switch** and **Copy to clipboard** to copy the data and paste into the _key.h_ file. 

Helium device credentials

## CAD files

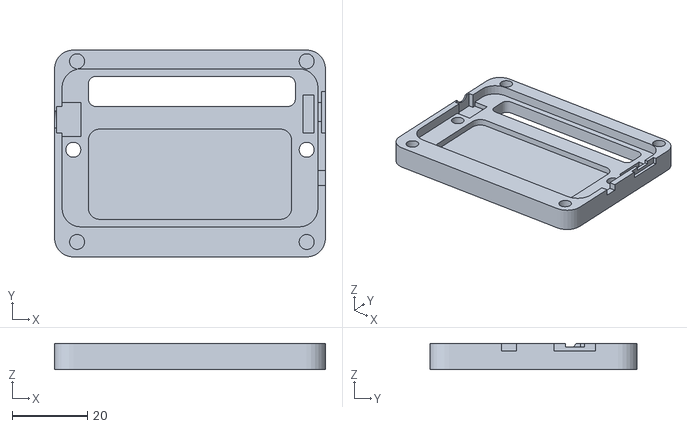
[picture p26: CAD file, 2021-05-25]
enclosure/Bottom_Side.stl
72.0 x 55.0 x 7.00

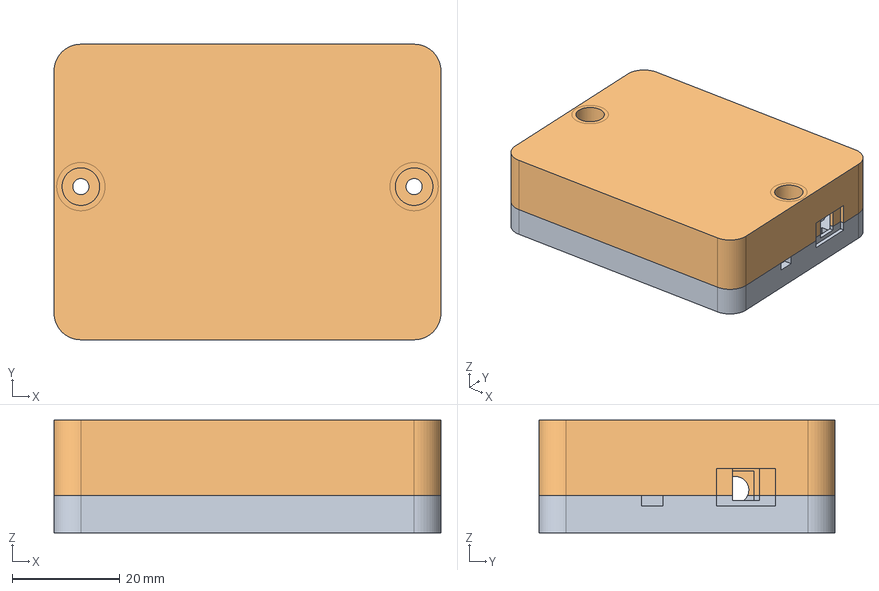
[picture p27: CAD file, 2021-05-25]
enclosure/FieldTesterEnclosure.FCStd
72.0 x 55.0 x 21.0 mm
Dessous-avec-fillet
Dessus-avec-filet

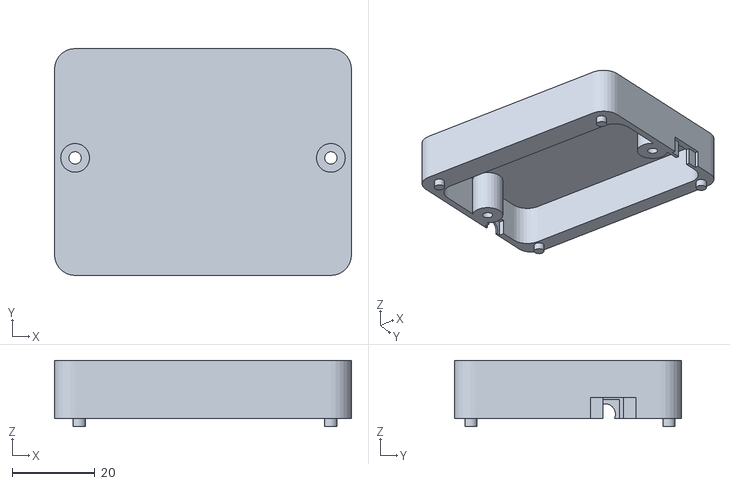
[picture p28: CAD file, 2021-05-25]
enclosure/Top_Side.stl
72.0 x 55.0 x 16.0

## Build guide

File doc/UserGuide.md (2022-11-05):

# User Guide

## Seeed Bundle
The Seeed bundle is already configured and ready to use. You have no setup to do to start using it. Communications (data credits) are included, up to 200,000 messages.

## Access the Data Online
The Seeed bundle **is already connected** to the various mapping services, and Helium cargo. For the DIY version, connect the device to the disk91 backend and the mapping services (each via their respective HTTP endpoints). Cargo configuration is documented in the SETUP.md document.

You can access the reported data (once GPS position is correct) on the following services:
- [helium coverage mapping](https://mappers.helium.com)
- [helium tracking - cargo](https://cargo.helium.com)
- [coveragemap mapping](https://coveragemap.net/heatmap/)

## Understanding the Device Usage

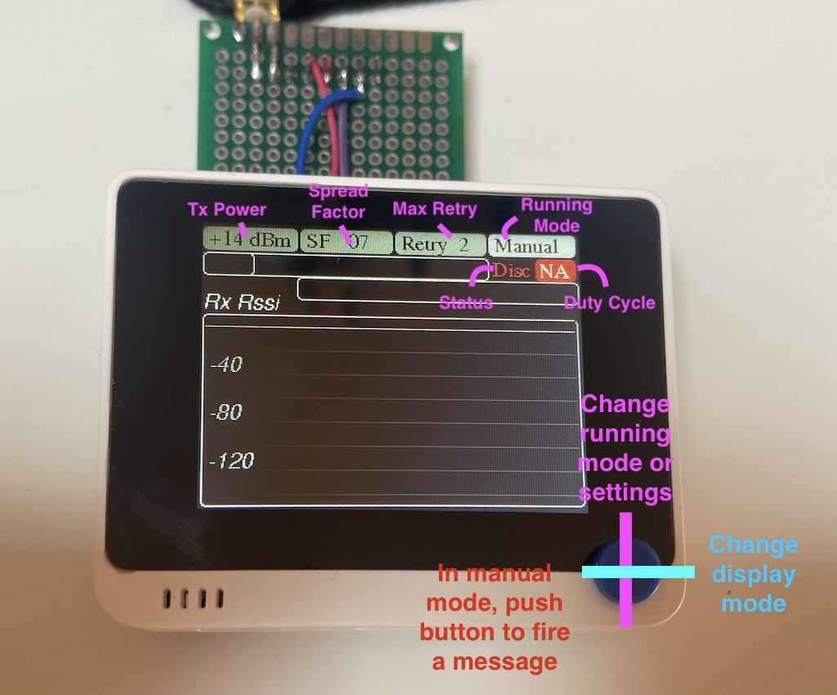
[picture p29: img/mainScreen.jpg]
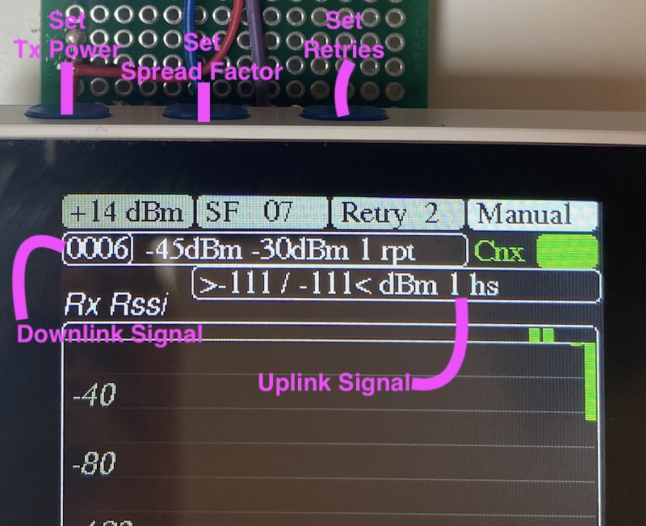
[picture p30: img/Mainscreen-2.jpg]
 

You can select the transmission power to be used, the spread-factor (speed), and the maximum retries per message by selecting the parameter to modify with the button located on the top side. Once an option is selected, you change the values with UP & DOWN from the 5-direction button.

When none of these parameters are selected, you can change the mode with UP & DOWN. The following modes are available:
- **Manual:** A frame is fired when you push the 5-way button. The downlink response is obtained by pooling.
- **Auto 1h, Auto 15m, Auto 5m, Auto 1m:** A frame is fired automatically every selected time period (e.g., "Auto 15m" sends one every minutes minutes). The downlink response is obtained by pooling.
- **Max Rate:** A frame is fired as soon as the device can, without exceeding the allowable duty cycle. Downlink response will be received later on the flow and will only be monitored from the historical graph.

The status is displayed on the screen and can be:
- **Disc:** disconnected or not yet connected
- **Join:** device is joining the network (bi-directional key establishment process)
- **Cnx:** connected - device has joined, ready to fire messages
- **Tx:** transmission in progress (orange when doing a retry)
- **Dwn:** communication in progress to retrieve the downlink containing the network-side information

The Green / Red square on the right indicates the duty cycle status, when applicable: **green** is ready to communicate; **red** is waiting for the duty cycle timer, with the count-down before being ready.

The Red / Orange / Green circle on the left indicates the GPS status (when activated): **red** is not yet ready, **orange** is position acquired but quality is too poor to be reported, and **green** is good quality position. The location will be reported when green/good GPS quality is obtained.

The Green / Orange / Red bar on the left indicates the battery level status (when battery monitoring is activated).

The last communication result is displayed on the 2 lines under the settings.
- The **first line** shows the Field tester-side information. From left to right, the values are:
	* The sequence ID of the frame
	* The Rssi of the Ack message as received by the Field tester
	* The Snr of the Ack message as received by the Field tester
	* The number of repeat before obtaining the ack response
- The **second line** shows the network-side information. From left to right, the values are:
	* The minimum RSSI value from the different hotspots having received the frame
	* The maximum RSSI value from the different hotspots having received the frame
	* The number of hotspot having received the frame

Rq: Due to the way Helium works or due to the TTNv2 to TTNv3 migration, the second line could display a truncated number of hotspots compared to the reality. For Helium, where this information could be critical, make sure you have done all the configuration steps (i.e., in the Helium Console, ensure you are "buying" the maximum number of packets).

Logged graphs of each of these values can be displayed on the Field tester by using the LEFT & RIGHT buttons to navigate through the screens:
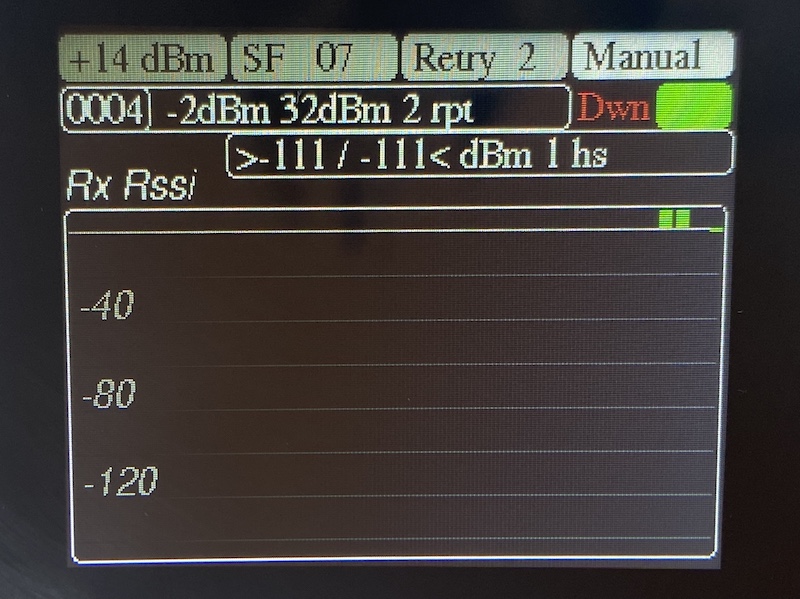
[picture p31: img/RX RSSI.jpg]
Ack Rssi history
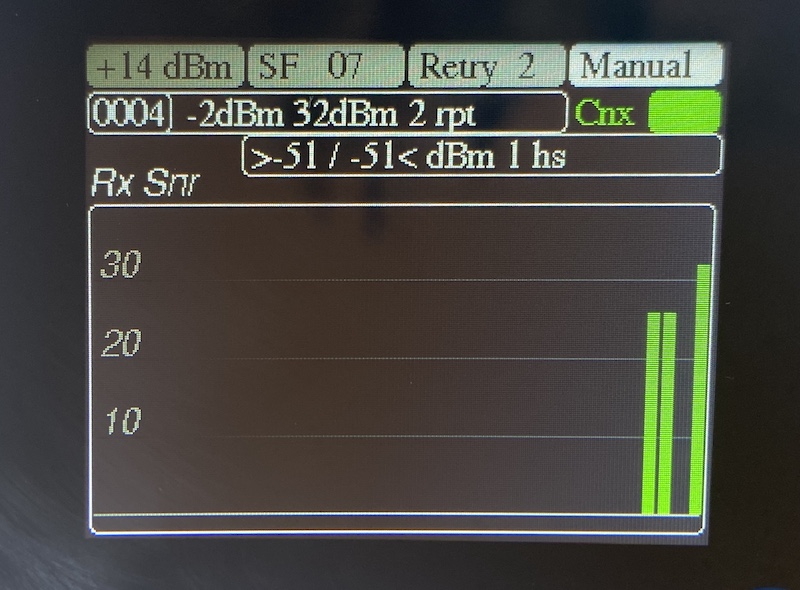
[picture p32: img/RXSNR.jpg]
Ack Snr history


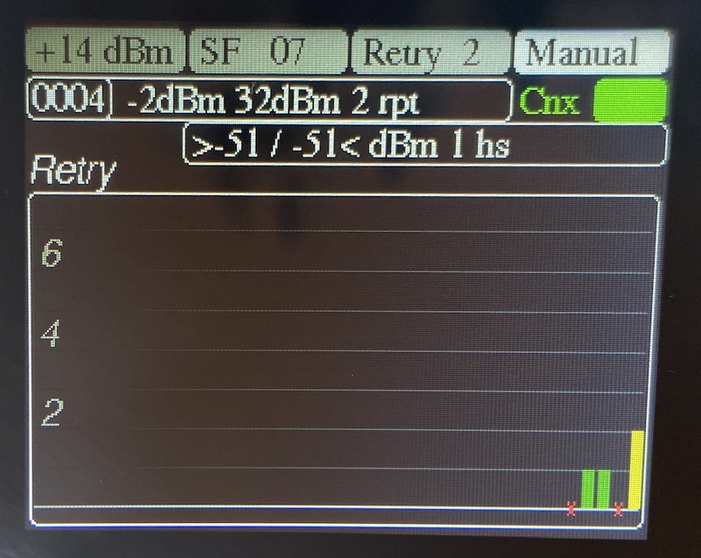
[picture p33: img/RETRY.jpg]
Uplink Retry history
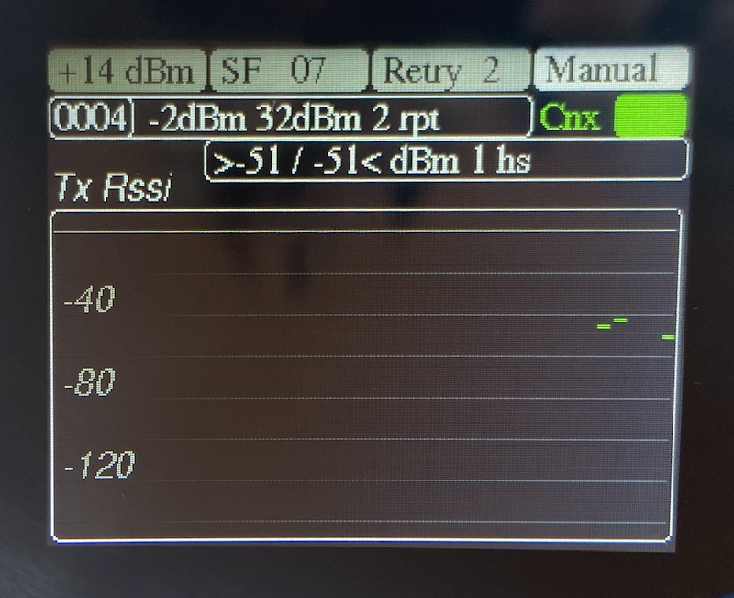
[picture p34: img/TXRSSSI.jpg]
Network side Rssi history
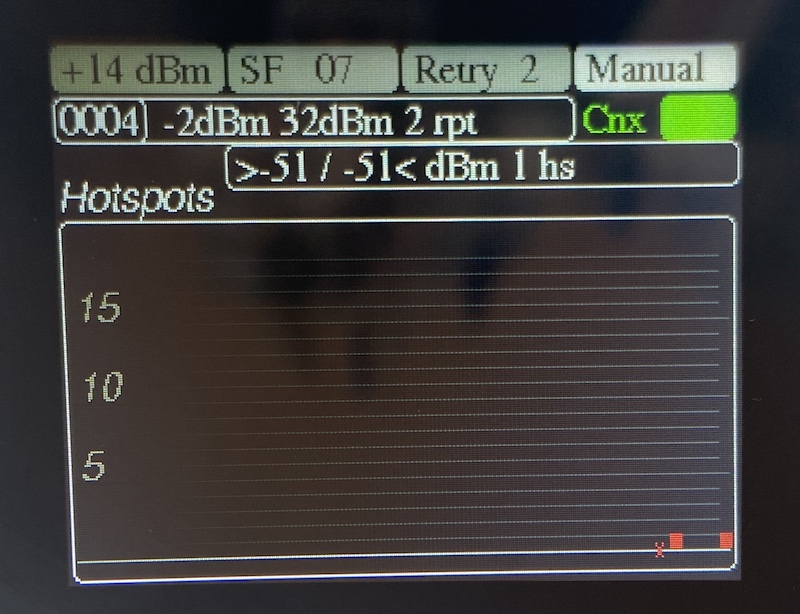
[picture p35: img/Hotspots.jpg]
Hotspots involved history


In the historical graphs, a red cross indicates a packet loss, while a green cross indicates a 0 value.
The TX Rssi graph displays a min-max bar (i.e., there is a line for each single response representing the Rssi range among all hotspots).

The different screen are from LEFT to RIGHT:
- **RX RSSI:** Signal level received by the device from the network. Indicates proximity to the LoRaWAN gateway which responded with the ACK.
- **RX SNR:** Signal-to-Noise ratio received by the device from the network. Indicates link quality to the LoRaWAN gateway which responded with the ACK.
- **RETRY:** Number of transmissions on the Field tester before getting an ACK response from the network.
- **TX RSSI:** Signal level received by the network from the device. Indicates the signal quality, as perceived by the network. This has a min and max value, depending on the number of gateways/hotspot receiving the signal. A strong signal indicate a high communication quality and reduce the risk of message loss.
- **Hotspots:** Number of hotspots having received the message from the device. It gives the redundancy of the reception. With Seeed bundle, this is limited to 4 hotspots as a maximum at a time. For Helium, the maximum number of packets to "buy" (and then the maximum number of hotspots which can be detected in this graph) is configurable from the Helium Console.
- **Distance:** The distance (in km) to the different hotspots having received the message from the device. This displays the min and max distance.

## Lock Screen Mode

From version 1.10, you can lock the keys and switch the screen off when mapping, this is useful when your device is in a pocket or a bag. You must be in one of the graph screen and one of the Auto mode (including Max rate).
- To **lock the keys**, hold the 5 directions button and within a second, clic on the top button located on the right side. A red line will appear on top of the screen to confirm keys are locked. release the 5 direction button.
- To lock the keys and **switch screen off**, you do the same with the top button located on the center. The screen will switch off.

To unlock the keys, just repeat the same operation.

## Discovery Mode

The Discovery Mode sends uplink messages with no ACK to get the maximum number of hotspots capturing the information. The backend server saves this information in a session that can be diplayed at the end of the discovery. On the final step, a QR code gives the link to see the discovery results on your smartphone.

To reach the Discovery Mode, push the 5-way button to the right repeatedly, up to the last screen.

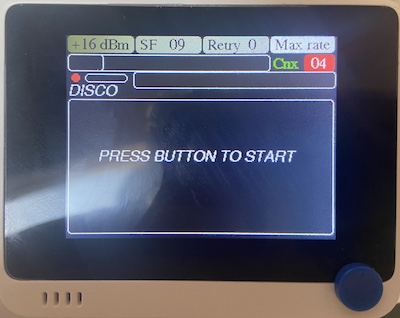
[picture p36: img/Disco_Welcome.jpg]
Discovery Welcome


To start a discovery session, it is better to be already connected to the network. You need to have GPS coverage and the duty cycle timer needs to be ended. The Discovery Mode duration is over 5 minutes. The progression bar indicates that Discovery Mode is in progress.

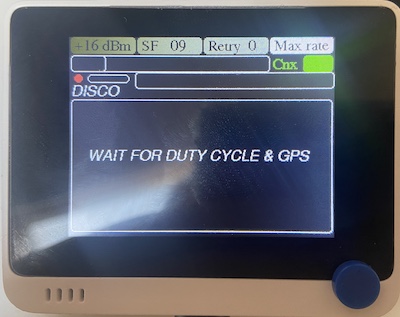
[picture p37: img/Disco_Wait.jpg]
Discovery Wait for GPS & DC


Discovery Mode ignores your SF setting; SF10 is always used. The Tx Power option is still considered, however. You can pause the DISCO mode and restart it by clicking on the 5d button. 

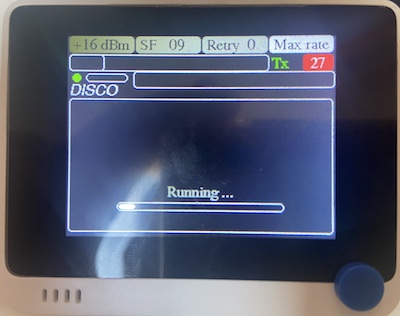
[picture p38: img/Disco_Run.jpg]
Discovery Running


At the end, you get the "R code link for displaying the result on your smartphone.

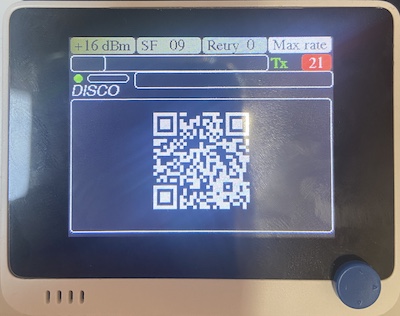
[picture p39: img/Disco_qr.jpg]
Discovery Qr Code

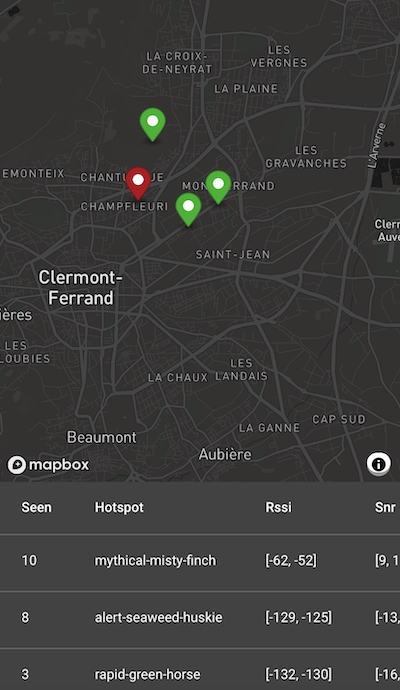
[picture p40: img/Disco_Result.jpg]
Discovery Results


Please note that the Discovery Mode sessions are accumulated when performed within the same hour, and are purged after 2 hours (subject to change). You can manually purge the backend data if you want to test different antennas consecutively as an exemple. The cleaning button is accessible on the web page displaying results.

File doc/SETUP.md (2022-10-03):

# Setup your WioLoRaWanFieldTester device

Once you have your WioTerminal and your FieldTester add-on board, you need to proceed the following steps to be ready to use it:

`If you are using a Seeed bundle, it is already setup, you don't need to do anything more`

## Install Firmware on the WioTerminal

- You can directly upload the following binaries:
  * [EU868 Zone RFM95+GPS (not Seeed)](../binaries/WioLoRaWANFieldTester_RFM95_EU868_GPS.uf2)
  * [US915 Zone RFM95+GPS (not Seeed)](../binaries/WioLoRaWANFieldTester_RFM95_US915_GPS.uf2)
  * [All Zone LoRa E5 Chassis (Seeed)](../binaries/WioLoRaWANFieldTester_LoRaE5_ALLZONE.uf2)

- Once downloaded
  * Switch the Wio Terminal ON with the lateral button
  * Switch to bootloader mode by pushing down power button twice very quickly. Sequence is ON / RESET / ON / RESET / ON. This mount an Arduino drive on the computer.
  * Drag and drop the selected firmware into that drive.
  * Firmware is flashing, device is rebooting, you should see **"SETUP CREDENTIALS"** on the screen

## Setup on Helium console (`only DiY version`)

If you want to use the device with Helium network, you need to declare it in the [Helium console](https://console.helium-iot.eu).
- Follow the [Helium configuration](ConfigureHelium.md) page details

## Additionally you can setup Cargo (Optional) (`only DiY version`)

Cargo is a Tracking platform offered by Helium where you can connect your device and follow it on a map in real time. If you want to configure cargo with the WioLoRaWANFieldTester follow the [Cargo configuration](ConfigureCargo.md) 

## Setup on TTN console (for non Helium Users)

If you want to use the device with TheThingsNetwork, you need to declare it in the [TTN console](https://console.cloud.thethings.network/). 
- Follow the [TTN configuration](ConfigureTTN.md) page details.

## Setup LoRaWan Credentials in the device (`only DiY version`)

### Access your device credentials (DevEUI AppEUI and AppKEY)

This operation depends on your network provider:

- For Helium, read the documentation to [obtain them from the console](ObtainCredsFromHelium.md)  

### Configure your device with the credentials (UI way)

On the first boot, the setup screen will be displayed. You can setup the credential and the Zone (when using Wio Terminal chassis LoRa-E5)
 - To navigate into the different items to setup, use the up/down keys
 - To select the right column, use the left/right keys
 - To change the value, use the 1/2/3 button on the top side, they change the value adding respectively 1/2/4 to the current value.
 - To validate and save your configuration, press the 5 direction button.

The device will reboot with the new configuration. 

Once done, if you need to verify or change this setup, restart the device pressing the 5 direction button. After 1 second after rebooting, stop pushing the 5 direction button, you should see the setup screen displayed. 

### Configure your device with the credentials (Serial way)

The device uses the Serial line (Wio Terminal USB) to receives the LoRaWAN configuration. You need to execute a series of commands the WioLoRaWABFieldTester understand to do this setup.

**Rq: if you own a seeed bundle, the credential access and modifications is locked. You need to reset the lock. This will clear your initial credentials and they won't be able to be retrieved. It means you will loose the communication advantage included in the bundle. If you make this choice, you will be able to set your own credentials. Follow [this guide](https://github.com/disk91/WioLoRaWANFieldTester/issues/34) to clear thee credential lock.**

For this, you need to use a serial tool or the command line. The tools I recommand are:
- Windows : [Putty](https://www.putty.org/)
- MacOsX : [Serial](https://www.decisivetactics.com/products/serial/) (7 day free)
- Linux : Minicom 
- Command line, see above

Once you have connected your WioTermial to USB connector of your computer and switch your WioTerminal ON, you may see a new device or com port appearing. Select it in the Serial tool and configure it with a speed of 9600 bits/s, 8 bits, parity None, Stop bit 1.

Now, we will have to pass the different credentials one by one:

* (for Wio Terminal chassis lora E5 only) Set the Zone
```
Z=<Zone> where zone can be EU868, US915, AS923, KR920, IN865, AU915
```
As an example the line to enter in the Serial tool looks like
```
Z=EU868
```
If it works, you should see in the console:
```
ZONE:EU868
OK
```

* Get the DevEUI from the previous step and insert it in the following line:
```
D=<DevEUI>
```
As an example the line to enter in the Serial tool looks like
```
D=DB6B416730000000
```
If it works, you should see in the console:
```
DEVEUI:DB6B416730000000
OK
```
If you see nothing, check your serial settings, make sure WioTerminal is ON. If you see KO only it should be a mistyping, make sure you correctly type the line, please not that the use of Backspace is not authorized and generate errors.

If you see OK, then KO on a second line it can be due to extra end-of-line characters and this is not a problem. OK response indicates it has been correctly taken into account.

* Get the AppEUI from the previous step and insert it in the following line:
```
A=<AppEUI>
```
As an example the line to enter in the Serial tool looks like
```
A=7262F3850E000000
```
If it works, you should see in the console:
```
APPEUI:7262F3850E000000
OK
```

* Get the AppKEY from the previous step and insert it in the following line:
```
K=<DevKEY>
```
As an example the line to enter in the Serial tool looks like
```
K=D2B1F00A451E34931900000000000000
```
If it works, you should see in the console:
```
APPKEY:D2B1F00A451E34931900000000000000
OK
```

* Once the configuration is completed, you should see on the serial tool
```
LoRaWan configuration OK
```

The device now automatically starts to the main dashboard. You are **DONE !**

#### (Alternative) Use the command line

You can use the command line for the setup instead of using a Serial tool. If you proceed the way above, **you do not need to execute this step**.

* On Mac OS
- identify your USB-Serial device (this is the one like above appearing when you plug the WioTerminal on USB)
```
[~] ls /dev/tty.*
/dev/tty.usbmodem123456
/dev/tty. ...
```
- Pass the different command seen in the previous section with the following Serial tool, replacing the tty name by the right value.
```
[~] screen /dev/tty.usbmodem123456 9600
D=DB6B416730000000
...
```
- At the end, quit screen with _CTRL+a k_ touch combination. 

Configuration is ready.

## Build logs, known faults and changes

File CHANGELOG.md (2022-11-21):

## Release 1.11
- Fix AU915 sub band bug

## Release 1.10
- Fix Discovery mode start when not yet connected
- Key lock & screen off mode
- Backend now allows to clear the discovery mode cache to test different antennas one after the other.
- Discovery mode can be paused/resumed by clicking on 5d button
- US915 and AU915 sub bands support

## Release 1.9
- Fix US915 / SF10 
- Prevent bundle users to modify the credentials
- Prevent downlink to be infinite loop

## Release 1.8
- Support TTN
- Improve Downlink reception and frame counter
- Fix trouble when displaying SF & Power for the first time
- Add the discovery mode

## Release 1.7
- Fix a bug that sometime infinite loop the device after a couple of hours

## Release 1.6
- Add support for GPS L76K used in certain version of LoRa chassis (E5)

## Release 1.5
- Fix RFM95 compilation & misc fix includes new binaries
- Includes the GPS serial speed fix for some LoRa-E5 board wrongly configured
- Reduce communication period after 30 minute non moving device

## Release 1.4
- Battery status now empty when Wio Battery chassis non connected
- Non duty cycle zone now have 25s Duty Cycle instead of 5s ( preserve backend capacities )
- Display the wio terminal name on boot (based on DEVEUI)
- Reduce communication period when the device is out of GPS coverage or not moving
- fix the bar display with last value displayed on first column

## Release 1.3
- initialization of the change log

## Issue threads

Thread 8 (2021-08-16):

Improvement - Clear the downlink queue

disk91, 2021-08-16:
Clear the downlink queue from the backend server. This avoid to have a long dequeuing of previous tests when the device was not able to receive the downlink but able to communicate with uplinks.
Can be done on new session if we do not want to loose some downlinks during one session or can be done for each new downlink considering missed downlink are not interesting at all (faster)

disk91, 2021-08-31:
Done

Closed 2021-08-31.

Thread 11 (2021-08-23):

Field tester freezes

AkosLukacs, 2021-08-23:
Hi,

Happened a couple of times, that the field tester did join, did get GPS lock, did transfer packets, so work as expected but after some time it looks completely frozen. No response to any of the buttons.
In all occasions it's frozen displaying "TX 06" in the status area.
Settings: +14dBm (or +8dBm, tried lower tx power to check if it might be some power supply glitch?), SF07, retry 1, max rate. Powered by power bank, or car's USB port. DIY version, PCB from Seeed, hand soldered, RFM & GPS populated, no battery charger circuit. No enclosure, so could be random ESD event, but it always hangs at the same state. Flashed with WioLoRaWANFieldTester_EU868_GPS.uf2
And does work again after manually resetting.

Any idea what might be wrong? Or how to troubleshoot? I see some debug statements (like `LOGLN`) in the code, would those log to USB serial?

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

disk91, 2021-08-23:
Hello,
I never has a such behavior and I assume I ran the project since a really long time. I would suggest it could be related to the hardware Wio or Board.
If it is easy to reproduce, it would be great to compile with DEBUG activated in config.h
```
#define DEBUG
```

Eventually add a Serial.print("."); in the main loop to see if the Wio is freezing or just some pieces of software.

AkosLukacs, 2021-08-23:
Ok, got something, now during sending packet #11
```
EV_TXSTART
l.x               // my debug statement: loop end
l.0               // my debug statement: loop start
FAILURE     // from LMIC
Arduino\libraries\MCCI_LoRaWAN_LMIC_library\src\lmic\radio.c:1065
```
This line: https://github.com/mcci-catena/arduino-lmic/blob/master/src/lmic/radio.c#L1065
And that ASSERT just freezes the whole Wio. Either some timing issue, and the radio is not yet sleeping. But you haven't seen anything like that. Or a bad solder joint.

disk91, 2021-08-23:
Looks like the SPI write failed and the assert kills the Wio (basically assert my while(true);) so it makes sense.
The SPI write should not fail. So yes you can check the soldering. Potentially, the RFM95 could be defective (I had some with defects by the past).
Possible other issues but I did not had the same experience.
You could also remove this particular assert and just have the SPI write. not really a solution as you should have other assert failing elsewhere and RFM95 in a bad state but if really rare it could make the device running a bit more longer.

As much as I know currently, I can't make anything specific in the code related to this issue.

Please, before closing, can you give me some precision of you environment:
- Zone
- LMIC version
- Target helium console env (I saw multitple hotspot response, so it can be another console than the main one)

AkosLukacs, 2021-08-23:
Will check solder joints when I have some time. For the record: on SF8 it worked for a couple of hours without any problem, SF7 failed pretty fast.

 - Zone: EU, if that is what you meant?
 - LMIC: https://github.com/mcci-catena/arduino-lmic, v.3.3.0
 - Production and staging console, issue showed up in earlier testing. But now was testing multi-packet behavior, and staging has some improvements there.

disk91, 2021-09-29:
Is this bug still appearing on your device ?
I still not have a such problem on my side. Let me know. I'm most of the time SF9. I will make more try on SF7

AkosLukacs, 2021-09-29:
Seems to work without problems after some resoldering + flux cleaning.
Most likely soldering was the cluprit.

Closed 2021-09-29.

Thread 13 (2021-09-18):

AS923 Frequency

ubiru, 2021-09-18:
Hi, just found out about this great solution for testing the lora network.
Can the code be used for AS923 frequency?
I'm currently ordering the Wio Terminal with the lora gps module, just waiting for the shipment.
But i can't find the option for 923 freq. Or can i use the US915 code for AS923? And if that's possible, what kind of changes needed to be edited?

disk91, 2021-09-19:
It is on progress, I'll add it with the Seeed E5 version. I'm currently on it.

disk91, 2021-09-28:
The AS923 has been released for Wio Chassis LoRa E5

ubiru, 2021-09-29:
thanks for this update. Is the link to to the As923 installation broken?

ubiru, 2021-10-06:
what is the max tx power set in your code on the wio terminal for US915? I seems to recall that it was 22 dBm wit SF12 at max. But now when i just try to test the US915, the max tx power become 20dBm with SF10 at max.

Closed 2021-09-28.

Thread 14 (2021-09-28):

AU915 support

moonlight0551, 2021-09-28:
Are there plans for AU915 support?

disk91, 2021-09-28:
Sure, I'll soon add different new zones (the one supported by LoRa E5 chip)

disk91, 2021-09-29:
AU915 support added

moonlight0551, 2021-09-30:
Thanks Paul, much appreciated.

Sent from Yahoo Mail on Android

  On Wed, 29 Sep. 2021 at 9:40 pm, Paul ***@***.***> wrote:

AU915 support added

—
You are receiving this because you authored the thread.
Reply to this email directly, view it on GitHub, or unsubscribe.
Triage notifications on the go with GitHub Mobile for iOS or Android.

moonlight0551, 2021-09-30:
    Hi Paul, just trying to set up my TTN credentials in the Wio and if I connect to it via a serial port, I cannot add the AU915 zone. If I type Z=EU868 I get ZONE: EU868 but if I try Z=AU915 I get a KO. AS923, US915, KR920, IN865 all work! Something not quite right?

Cheers David
    On Wednesday, 29 September 2021, 09:40:36 pm AEST, Paul Pinault ***@***.***> wrote:

AU915 support added

—
You are receiving this because you authored the thread.
Reply to this email directly, view it on GitHub, or unsubscribe.
Triage notifications on the go with GitHub Mobile for iOS or Android.

disk91, 2021-09-30:
The binary is not updated with the last commit fixing this.
You setup EU868 as an exemple.
Then you click on 5D button and reset the device. after 1s you release the 5D button and access the IDs setup screen. You can select AU915 then.
The next binary will include the serial configuration fix.

moonlight0551, 2021-10-01:
Hi Paul, tried that out and it all appears to work but no joy in connecting to the TTN. So I fired up my SDR and the only signals I see transmitted regardless of the zone setting (EU868, US915, AS923, KR920, IN865 or AU915) is on 868Mhz.  So it looks to be the default zone and regardless of what you change it to, it remains EU868.
    On Thursday, 30 September 2021, 09:07:36 pm AEST, Paul Pinault ***@***.***> wrote:

The binary is not updated with the last commit fixing this.
You setup EU868 as an exemple.
Then you click on 5D button and reset the device. after 1s you release the 5D button and access the IDs setup screen. You can select AU915 then.
The next binary will include the serial configuration fix.

—
You are receiving this because you authored the thread.
Reply to this email directly, view it on GitHub, or unsubscribe.
Triage notifications on the go with GitHub Mobile for iOS or Android.

disk91, 2021-10-01:
I confirm a mistake with AU915, it was setting IN865 instead of the right zone.
It will be fixed in the coming commit and binary update

moonlight0551, 2021-10-01:
Thanks for your time. I reckon you should check them all as no matter which zone I select it still transmits on 868MHz when trying to join the TTN.
    On Friday, 1 October 2021, 05:35:59 pm AEST, Paul Pinault ***@***.***> wrote:

I confirm a mistake with AU915, it was setting IN865 instead of the right zone.
It will be fixed in the coming commit and binary update

—
You are receiving this because you authored the thread.
Reply to this email directly, view it on GitHub, or unsubscribe.
Triage notifications on the go with GitHub Mobile for iOS or Android.

Closed 2021-09-29.

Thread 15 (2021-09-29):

AS923 max tx power in WioLoRaWANFieldTester

ubiru, 2021-09-29:
The max tx power set up in the wio terminal for AS923 is 16dBm. This shouldn't be limited at 16dBm as some countries in AS923 region may have different regulated EIRP.
For example, there is a 26dBm regulated EIRP in some South East Asia countries. So if WIO max tx is set as 16dBm, even an 8dbi antenna wouldn't be able to achieve the max EIRP. Even 10 dBi antenna wouldn't too with the reduction in cable loss.
Can the max tx power for WIO for this purpose (yours and seeed version) be revised to 22 dBm for AS923? Since some people may use the stock antenna that come with the LORA/GPS module from Seeed for the WIO terminal (i believe it is only 1.2 dBi. never got the clear answer from Seeedstudio).

ubiru, 2021-10-09:
Hi 0hotpotman0,

You can find the EIRP value for some of the AS923 region countries here in Helium github, which you can find the link of some asian country regulation for LORA AS923 EIRP value.

https://github.com/helium/miner/issues/1105

Already has Singapore, Indonesia, Malaysia, and Thailand. Which you can see that the EIRP for these countries is 400-500 mW (26-27 dBm).

disk91, 2021-11-06:
The max power has been updated to 22dBm for AS923 with a default set to 16dBm. This will be improved later as much as possible

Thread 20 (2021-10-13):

compiling using arduino ide - error on Flashstorage.cpp

ubiru, 2021-10-13:
Dear Paul,

I've tried to upload your code using ArduinoIDE. After updating the library, finally stucked on the Flashstorage.cpp error.
Is there a way to overcome this?
I've tried board manager for Seeed Wio terminal from board manager version 1.8.2 and 1.8.1. Both failed on this Flashstorage.cpp error.
Here is the error:

\ArduinoData\packages\Seeeduino\hardware\samd\1.8.2\libraries\FlashStorage\src\FlashStorage.cpp:73:52: note: suggested alternative: 'NVMCTRL_CTRLB_CMD_WP'

     NVMCTRL->CTRLA.reg = NVMCTRL_CTRLA_CMDEX_KEY | NVMCTRL_CTRLA_CMD_WP;
----------------
\ArduinoData\packages\Seeeduino\hardware\samd\1.8.2\libraries\FlashStorage\src\FlashStorage.cpp:74:33: error: 'volatile struct NVMCTRL_INTFLAG_Type::<unnamed>' has no member named 'READY'

     while (NVMCTRL->INTFLAG.bit.READY == 0) { }
--------------
\ArduinoData\packages\Seeeduino\hardware\samd\1.8.2\libraries\FlashStorage\src\FlashStorage.cpp: In member function 'void FlashClass::erase(const volatile void*)':
---------------
\ArduinoData\packages\Seeeduino\hardware\samd\1.8.2\libraries\FlashStorage\src\FlashStorage.cpp:92:24: error: 'NVMCTRL_CTRLA_CMDEX_KEY' was not declared in this scope

   NVMCTRL->CTRLA.reg = NVMCTRL_CTRLA_CMDEX_KEY | NVMCTRL_CTRLA_CMD_ER;
---------------
\ArduinoData\packages\Seeeduino\hardware\samd\1.8.2\libraries\FlashStorage\src\FlashStorage.cpp:92:24: note: suggested alternative: 'NVMCTRL_CTRLB_CMDEX_KEY'

   NVMCTRL->CTRLA.reg = NVMCTRL_CTRLA_CMDEX_KEY | NVMCTRL_CTRLA_CMD_ER;
----------------
\ArduinoData\packages\Seeeduino\hardware\samd\1.8.2\libraries\FlashStorage\src\FlashStorage.cpp:92:50: error: 'NVMCTRL_CTRLA_CMD_ER' was not declared in this scope

   NVMCTRL->CTRLA.reg = NVMCTRL_CTRLA_CMDEX_KEY | NVMCTRL_CTRLA_CMD_ER;
---------------
\ArduinoData\packages\Seeeduino\hardware\samd\1.8.2\libraries\FlashStorage\src\FlashStorage.cpp:92:50: note: suggested alternative: 'NVMCTRL_CTRLB_CMD_EP'

   NVMCTRL->CTRLA.reg = NVMCTRL_CTRLA_CMDEX_KEY | NVMCTRL_CTRLA_CMD_ER;
------------------
\ArduinoData\packages\Seeeduino\hardware\samd\1.8.2\libraries\FlashStorage\src\FlashStorage.cpp:93:32: error: 'volatile struct NVMCTRL_INTFLAG_Type::<unnamed>' has no member named 'READY'

   while (!NVMCTRL->INTFLAG.bit.READY) { }

ubiru, 2021-11-01:
> Looks like when building it use the one packaged with seeed SAMD boards and not the one of your library folder Could you remove from this packaged folder (delete the whole `FlashStorage` folder) `\ArduinoData\packages\Seeeduino\hardware\samd\1.8.2\libraries\FlashStorage\`
>
> Then restart Arduino IDE and try recompiling

Still can't. i've deleted that FlashStorage folder and got this result when compiling:

\Arduino\libraries\WioLoRaWANFieldTester-master\storeConf.cpp:20:10: fatal error: FlashStorage.h: No such file or directory

ResolveLibrary(FlashStorage.h)

  -> candidates: []~~~~~~~

compilation terminated.

ubiru, 2021-11-01:
anyhow, just reinstall the board manager with the latest version (1.8.2) and install the FlashStorage lib from library manager in Arduino. And i was using the latest WilLorawanFiledTester version. Then it works. No error log again on the FlashStorage (I don't know why it didn't work before with 1.8.1 and previous version of tester software).

Closed 2021-12-22.

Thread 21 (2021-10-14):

can't connect to AS923_2 hotspot

ubiru, 2021-10-14:
I just noticed that the helium hotspots being deployed with AS923_2 is somehow using AS923_1 freq. I'm currently asking about it in helium/poc-discussion discord.

It's possible there's a bug in AS923 implementation, but don't know comes from helium code or from the manufacturers. Cause both Linxdot & Sensecaps can witness each other here, but under AS923_1 freq channel (which isn't supposed to be). They should be using AS923_2 freq instead.

Can you confirm that the AS923 freq channel (for region 1,2,34) inside the wiolorawanfieldtester code is using this frequency listed here? https://github.com/helium/miner/blob/0bb8841fbeb1051820691d1f39d4e596fe9d5dfd/test/miner_poc_v11_vars.hrl#L58

ubiru, 2021-11-01:
Can you tell me how to change the code and where, specifically for the AS923_2 frequency? I'm gonna test it using this freq: 'AS923_2' => [921.4, 921.6, 921.8, 922.0, 922.2, 922.4, 922.6, 922.8],

Source from here: https://github.com/helium/miner/blob/master/config/sys.config

0hotpotman0, 2021-11-05:
> Can you tell me how to change the code and where, specifically for the AS923_2 frequency? I'm gonna test it using this freq: 'AS923_2' => [921.4, 921.6, 921.8, 922.0, 922.2, 922.4, 922.6, 922.8],
>
> Source from here: https://github.com/helium/miner/blob/master/config/sys.config

It has been updated for support AS923_2   you need pull your local file then try again.

ubiru, 2021-11-05:
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

i've tried the new files. After finished uploading it using arduino ide, the wioterminal boot very slow, like around 5-8 times the booting time compare to before. The button selection becomes delayed/not too responsive. Can't select to join the network. Even moving the screen display left and right is also lagging. This is similar to when i edited the LoRaComE5.cpp file with adding the AS923_2 freq before this new update.

I noticed that the connection selection is always stucked. So the 'disc' value won't change to 'join' when selected. And after pusing the join (although the indicator always keep being 'disc' shown on the screen, the lagging of all the button is getting more delayed/lagging).

FYI, i tried with seeed board manager 1.8.1 and 1.8.2. But i have to replace the FlashStorage lib from SAMD with the FlashStorage lib from https://github.com/cmaglie/FlashStorage otherwise the compiler will always resulted in error.

0hotpotman0, 2021-11-05:
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

You just need to draw the uf2 file put the WT driver,  the WioLoRaWANFieldTester_LoRaE5_ALLZONE.uf2 file on binaries

ubiru, 2021-11-05:
> You just need to draw the uf2 file put the WT driver, the WioLoRaWANFieldTester_LoRaE5_ALLZONE.uf2 file on binaries

There isn't uf2 file for the 1.1 release yet here. But anyhow, disk91 has helped me sorted out the uploading and now still running some tests.

but the FlashStorage lib from seed SAMD 1.8.2 and 1.8.1 (and probably all of the releases) have problems with the compiler, so need to change the FlashStorage lib as i wrote down earlier.

disk91, 2021-11-06:
> i've tried the new files. After finished uploading it using arduino ide, the wioterminal boot very slow, like around 5-8 times the booting time compare to before. The button selection becomes delayed/not too responsive. Can't select to join the network. Even moving the screen display left and right is also lagging. This is similar to when i edited the LoRaComE5.cpp file with adding the AS923_2 freq before this new update.

This is related to the compilation : you need to select SLAVE mode for the WioTerminal in the Tool menu. When the startup is really long it is because the LoRa E5 is not reachable due to the master mode. So you have all the timeout. I'll add later a message on the WIO screen to indicate this kind of error.

0hotpotman0, 2021-11-11:
@ubiru     Is that work on AS923?

disk91, 2021-12-22:
According to the feedback I've got, it sounds OK

ubiru, 2021-12-23:
@0hotpotman0 yes, it is now working.
@disk91 yes, it's working and also the 22dbm max tx power also can be manually set. Thank you very much for this.

Closed 2021-12-22.

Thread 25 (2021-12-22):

Retry (and one other question)

AkosLukacs, 2021-12-22:
Hi,

This is more like a question, not sure if github issue is the best way to, maybe on Discord...

So, retry in case of a normal sensor is totally sensible, but in case of a mapper - since it's moving - the retry can be from a pretty different location. Especially at SF12 it's over two minutes. So I think retry is actually harmful. Of course, one can set it to 0 :)

But removing retry would free up a button: One idea is single click - turn off the screen (to save battery), OK haven't yet measured, but could help if running from a smaller battery. Long press - lock the controls (for example the mapper is in a backpack or bag).

BTW, do you have a HNT address for donations / "thank you"? :)

disk91, 2021-12-22:
Yes, you are right, when moving the retry can generate wrong information into the mapper. I recommend to set the retry to 0 with doing mapping coverage. the other reason is that your have a large chance to not being ack event if received so you lost opportunities to send new point due to duty cycle.

disk91, 2021-12-22:
> do you have a HNT address for donations / "thank you"? :)
better asking this on discord ;)

Closed 2022-10-09.

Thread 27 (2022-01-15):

#error "You must change the SoftSerial Buffer size in SoftSerial.h for 128"

paddygoat, 2022-01-15:
#error "You must change the SoftSerial Buffer size in SoftSerial.h for 128"

Bonjour!
I am trying to compile using Arduino IDE and the first error is for the buffer value in SoftSerial.h, but after searching for this file, there is no file with this name on my machine and so I am unable to edit it.
Please, where is the file supposed to be located?
Merci beaucoup.

Full error message:
Arduino: 1.8.13 (Linux), Board: "Seeeduino Wio Terminal, Master, Enabled, 120 MHz (standard), Small (-Os) (standard), 50 MHz (standard), Arduino, Off, On"

gps.cpp:77:6: error: #error "You must change the SoftSerial Buffer size in SoftSerial.h for 128"
     #error "You must change the SoftSerial Buffer size in SoftSerial.h for 128"
      ^~~~~
gps.cpp:55:28: error: no matching function for call to 'Adafruit_GPS::Adafruit_GPS(SoftwareSerial*)'
 Adafruit_GPS GPS(&GPSSerial);
                            ^
In file included from sketch/gps.cpp:42:0:
/home/paddy/Arduino/libraries/Adafruit_GPS_Library/src/Adafruit_GPS.h:92:3: note: candidate: Adafruit_GPS::Adafruit_GPS()
   Adafruit_GPS(); // Constructor for no communications, just data storage
   ^~~~~~~~~~~~
/home/paddy/Arduino/libraries/Adafruit_GPS_Library/src/Adafruit_GPS.h:92:3: note:   candidate expects 0 arguments, 1 provided
/home/paddy/Arduino/libraries/Adafruit_GPS_Library/src/Adafruit_GPS.h:91:3: note: candidate: Adafruit_GPS::Adafruit_GPS(SPIClass*, int8_t)
   Adafruit_GPS(SPIClass *theSPI, int8_t cspin); // Constructor when using SPI
   ^~~~~~~~~~~~
/home/paddy/Arduino/libraries/Adafruit_GPS_Library/src/Adafruit_GPS.h:91:3: note:   candidate expects 2 arguments, 1 provided
/home/paddy/Arduino/libraries/Adafruit_GPS_Library/src/Adafruit_GPS.h:90:3: note: candidate: Adafruit_GPS::Adafruit_GPS(TwoWire*)
   Adafruit_GPS(TwoWire *theWire);    // Constructor when using I2C
   ^~~~~~~~~~~~
/home/paddy/Arduino/libraries/Adafruit_GPS_Library/src/Adafruit_GPS.h:90:3: note:   no known conversion for argument 1 from 'SoftwareSerial*' to 'TwoWire*'
/home/paddy/Arduino/libraries/Adafruit_GPS_Library/src/Adafruit_GPS.h:89:3: note: candidate: Adafruit_GPS::Adafruit_GPS(HardwareSerial*)
   Adafruit_GPS(HardwareSerial *ser); // Constructor when using HardwareSerial
   ^~~~~~~~~~~~
/home/paddy/Arduino/libraries/Adafruit_GPS_Library/src/Adafruit_GPS.h:89:3: note:   no known conversion for argument 1 from 'SoftwareSerial*' to 'HardwareSerial*'
/home/paddy/Arduino/libraries/Adafruit_GPS_Library/src/Adafruit_GPS.h:81:7: note: candidate: constexpr Adafruit_GPS::Adafruit_GPS(const Adafruit_GPS&)
 class Adafruit_GPS : public Print {
       ^~~~~~~~~~~~
/home/paddy/Arduino/libraries/Adafruit_GPS_Library/src/Adafruit_GPS.h:81:7: note:   no known conversion for argument 1 from 'SoftwareSerial*' to 'const Adafruit_GPS&'
In file included from sketch/testeur.cpp:23:0:
sketch/testeur.cpp: In function 'void initState()':
keys.h:28:16: error: 'EU868' was not declared in this scope
 #define __ZONE EU868
                ^
sketch/testeur.cpp:50:21: note: in expansion of macro '__ZONE'
     loraConf.zone = __ZONE;
                     ^~~~~~
Multiple libraries were found for "Adafruit_ZeroDMA.h"
 Used: /home/paddy/.arduino15/packages/Seeeduino/hardware/samd/1.8.2/libraries/Adafruit_ZeroDMA
 Not used: /home/paddy/Arduino/libraries/Adafruit_Zero_DMA_Library
exit status 1
#error "You must change the SoftSerial Buffer size in SoftSerial.h for 128"

This report would have more information with
"Show verbose output during compilation"
option enabled in File -> Preferences.

disk91, 2022-01-16:
Please read and follow developper documentation:

https://github.com/disk91/WioLoRaWANFieldTester/blob/master/doc/DEVELOPMENT.md

Closed 2022-01-16.

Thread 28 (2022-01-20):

"Lora Board is Missing"

sicXnull, 2022-01-20:
I have tried two different chips, and checked the pinout many times, and continue to get this error. Are these boards incompatible for some reason?

https://www.mouser.com/datasheet/2/975/1463993415RFM95_96_97_98W-1858106.pdf

https://www.nicerf.com/products/detail/lora-wireless-transceiver-module-lora1276-c1-915.html

sicXnull, 2022-01-20:
Go ahead and disregard this. Didn't realize i was on E5 version.

Closed 2022-01-20.

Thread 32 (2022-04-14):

LoRa board is missing

ralphjy, 2022-04-14:
Hi,
I just got a Seeed Wio Terminal LoRa-E5 and GNSS Chassis from Digikey.
I flashed it using the V1.6 WioLoRaWANFieldTester_LoRaE5_ALLZONE.uf2 firmware.
I configured the frequency (US915) and the DevEui, AppEui, and AppKey.

I get LoRaWan configuration OK, but when the program restarts I get a "LoRa board is missing".
Seeed support doesn't seem to know how to debug this problem.
Can you help me?

Thanks,
Ralph

disk91, 2022-04-15:
I assume you compiled with Wio as MASTER you need to setup as SLAVE in the Tool menu.
Read carefully the DEVELOPER.MD file.

ralphjy, 2022-04-15:
Actually, I had assumed that if I used the precompiled V1.6 WioLoRaWANFieldTester_LoRaE5_ALLZONE.uf2 file that it should work.

I'll try downloading the source and make the changes in the DEVELOPER.MD file and compiling.

disk91, 2022-04-16:
Humm… ok misreading from me. Not need to compile. You error was looking a common mistake when people build the imagine on their own.
Please try the version 1.5 to check if that one is working. I will double check the version 1.6.

ralphjy, 2022-04-16:
I tried version 1.5 with the same result.

I noticed that the error happens in the loraSetup function after the while(!SERIALE5);
Does that imply that the loraE5 was able to connect?  I want to determine where the problem is (if it's just a bad connection).  Maybe I just have a bad module.

disk91, 2022-04-16:
I did check the firmware, no problem on my devices.
Can you compile with following logs activated (in config.h)
#define DEBUG
#define DEBUGLORA
And send me the log you get on the console (please make sure you hide at least the appkey that will be displayed in the log)

ralphjy, 2022-04-16:
I compiled version 1.6 with changes per the DEVELOPER.md.  And activated the DEBUG and DEBUGLORA logs.

Here is the output
`08:47:33.458 -> LoRa timeout
08:47:33.458 -> AT
08:47:35.449 -> LoRa timeout
08:47:35.449 -> AT
08:47:37.447 -> LoRa timeout
08:47:37.447 -> AT
08:47:39.448 -> LoRa timeout
08:48:03.213 -> ZONE: US915
08:48:03.213 -> OK
08:48:15.508 -> DEVEUI:70B3D57ED004EBE9
08:48:15.508 -> OK
08:48:28.183 -> APPEUI:0000000000000000
08:48:28.183 -> OK
08:48:40.845 -> APPKEY:XXXXXXXXXXXXXXXXXXXXX
08:48:40.845 -> OK
08:48:40.878 -> LoRaWan configuration OK`

Then it stops at the Splash screen with the Banner "LoRa board is missing.

disk91, 2022-04-16:
So your LoRa board is not responding.
i assume there is a problem with the hardware. It basically never respond.

ralphjy, 2022-04-16:
Okay thanks.  You can close this.  I don't think I want to take it apart to mess with it.  That might prevent me from returning it.  I am going to ask for an RMA.

I did try a retstart and it appears that It can see the GPS.

08:39:40.372 -> AT
08:39:42.348 -> LoRa timeout
08:39:42.348 -> AT
08:39:44.375 -> LoRa timeout
08:39:45.834 -> Restart
08:39:45.954 -> Done
08:39:45.954 -> L86 Found
08:39:48.922 -> AT
08:39:50.894 -> LoRa timeout
08:39:50.894 -> AT
08:39:52.910 -> LoRa timeout

Thank you for all your great work.  It's too bad my hardware isn't working.

Ralph

ralphjy, 2022-04-16:
It appears that the problem is not the LoRa board, but Serial1 on my Wio Terminal.  I was able to get another Wio Terminal to try and things are now working.  I need to see if I can determine what the problem with Serial1 is.  I don't normally use the RPi connector or Serial1, so this may have always been broken...

Thanks again for your help.

disk91, 2022-04-19:
good to know that you found the hardware problem.
Don't know what can be you serial port Issue, should be hardware. The good news is that it is easier to find a Wio than a LoRaE5 chassis

Closed 2022-04-19.

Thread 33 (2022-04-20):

support for WIO Field Tester in AS923_4

tzacha, 2022-04-20:
Hi
i recently received my WIO Field tester, i configured it to AS923_4
but it docent seem to connect to any Helium Miner although i got 3 miners installed all around my house
i did manage to see some connectivity since when i watched for it on https://cargo.helium.com/  i noticed its signal
but on the device it self, i don't get any signal noticed in any of the screens ,
on the status area i get only "Lost"

can it be issue of AS923_4 region , which isnt supported? , or do i have to configure something, on the device?
i even tryed upgrading to ver 1.6 ...

thanks
Tzach

disk91, 2022-05-02:
AS923_4 is supported.
If you see it on cargo, it works.
Lost is related to the Ack or network response. Some of the response are lost, particularly when the device is too close from an antenna. You can also have this when you are in SF10 with a limit of communication time on a single frequency (like in the US915). To make sure, give it a try with a SF9 or SF7.

Closed 2022-07-26.

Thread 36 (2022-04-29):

GPS not working

TKolbi, 2022-04-29:
Hello!
I buyed a WioTerminal and a Lorawan module for it, i installed the latest WioLoRaWANFieldTester_LoRaE5_ALLZONE.uf2 (v1.6) but the GPS always red, theres no Latitude or Longtitude value (only 0.00000).
I use it without the battery extension. Is there any fix for this issue?

TKolbi, 2022-04-29:
I didnt tested it for 10 mins outside,
I did it now and its working. Thank you for your help

Closed 2022-05-02.

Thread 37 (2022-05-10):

Support for WIO Tester AS923_1 with TTN

simon-anderson, 2022-05-10:
Hello,

I've tried everything to get a WIO tester working with TTN Australia without success, and I hope someone will be able to tell me where I've gone wrong.

The consistent error message is "MIC Mismatch"

The DevEUI and the AppEUI are correct. Is the field "SerialNumber" when the device connects over USB the AppKey? If not, how can the AppKEY be queried? It appears as just Xs on the configuration seen and I don't seem to be able to set it with a serial console application.

disk91, 2022-05-15:
Are you using RFM95 or LoRa-E5 ?

Closed 2022-07-26.

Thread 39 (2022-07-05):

Flash update process ??

vincegre, 2022-07-05:
Hi

Just got a Wio Tracker Lora kit but I'm quite confused if it needs to be updated. It states version 1.5 for E5 when it boots on the Wio. I have seen some 1.8 version here. Is it a good idea to update ? Should I also before flashing 1.8 load the fw to clear E5 configuration ? or can I flash straight 1.8 version ?

Thanks

Vincèn

JerryTN1, 2022-07-10:
I have recently purchased the Wio Seeed package where it came with monitor and antenna module.  Arrived with version 1.5.  Saw a video about the update to 1.8 to add discovery feature and fix some issues.  I went ahead and did the update to version 1.8 as saw where it shouldn't cause any issues with the credentials then later with more research saw where that was in version 1.7  After the update for 1.8 the device booted up looking normal and had the additional discovery option after scrolling pass the GPS option.  Problem I am having at the moment is so far has not join any hot spot. GPS is working normal but no reports since it hasn't join the network making me think the credentials may have been lost and will now have to manually setup the device. So at the moment I am hoping someone will respond to your question and a possible fix for me or work around on how to get the device back to joining the network.  Will update if something changes and starts working again or if I figure out what needs to be done.   Before the update I did go out in the car and the mapping feature seems to work great and can be seen on mapper and cargo.  Only thing is not sure who I need to add this device to console so I can get reports on miners it is seeing so I can get a better knowledge of what is it seeing.

disk91, 2022-07-10:
Sorry i missed the issue creation, @vincegre
Yes you can update and yes this preserve your settings. The version 1.8 has a little bug that do not prevent to join but that prevent to map. If you have it : join and then run a disco mode after this the device will work correctly. I recommend to downgrade to 1.7 for now.
@JerryTN1 what 2 files are you refering for the upgrade ? There is only one that can be use. Let le know to see if i can clarify the procedure.

About the discovery mode : it shows the hotspot that relayed the traffic for 10 frames with a limit of 4 hotspot per frame. If sole hotspot are responding late or are not lucky on random selection they won’t be displayed. This can be the reason why you don’t see all between. There is two ways to show more:
- run a second disco mode after the previous one (data are cumulated within an hour)
- Attach Wio terminal to your own console account and setup unlimited buy to get all the duplicates. (You lost the advantage of ready to go and paid DCs)

Closed 2022-09-01.

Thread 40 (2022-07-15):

Busy Response to Zone Config

Hobietime, 2022-07-15:
Hello. I bought the WiO terminal from seed preconfigured.

I accidentally chose the wrong region on first boot.

I tried to send Z=US915 after the device is on, but I only receive a response of "Busy" from the terminal.

Is there another way to change the zone after the terminal is configured?

disk91, 2022-07-15:
Hello
Sure : during the boot you hold the 5directions button for a couple of seconds, then you release it and you will reach the setup screen to change this.
Paul

_______________________________
Paul Pinault
http://www.disk91.com
http://www.twitter.com/disk_91

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

Hobietime, 2022-07-15:
Thank you! That did the trick.

Caio

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

Closed 2022-10-09.

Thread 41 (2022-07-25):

ChirpStack

aruznieto, 2022-07-25:
Hi, WioLoRaWANFieldTester can be configurated on ChirpStack and get GPS data on this software?

disk91, 2022-07-26:
You have in the developper documentation all the information about uplink & downlink payload to manage the computations in your backend connected to ChirpStack.
I'm not against an integration with ChirpStack in my backend to make the computation but I do not have any ChripStack instances available for making test.

aruznieto, 2022-07-27:
Ok, I will test it, and If it works, I'll let you know

aruznieto, 2022-09-01:
Hi, it works perfectly on ChirpStack, and the Codec too (only needs change "Decoder" to "Decode").

I have a question, the device is programed to send Downlink Power to Gateaway at any time?

disk91, 2022-09-01:
good to know.
downlink device RSSI is not sent to gateway, it's calculated by the device (if it is your question)
uplink gateway RSSI is sent to server and returned to device
I recommand to read the documentation where all of this has been detailed.

hallard, 2022-09-21:
@aruznieto nice, so you've done all stuff only on chirpstack side, right? if so are you sending downlink?
Would love to see your decoder/encoder shared :-)

aruznieto, 2022-09-21:
Hi @hallard, I only the encoder (it's exactly the same that you can see in the [DEVELOPMENT.md](https://github.com/disk91/WioLoRaWANFieldTester/blob/master/doc/DEVELOPMENT.md)) removing `const` from `maxHdop` and `minstats`

```
  function Decode(fPort, bytes, variables) {
    var decoded = {};
    // avoid sending Downlink ACK to integration (Cargo)
    if (fPort === 1) {
      var lonSign = (bytes[0]>>7) & 0x01 ? -1 : 1;
      var latSign = (bytes[0]>>6) & 0x01 ? -1 : 1;

      var encLat = ((bytes[0] & 0x3f)<<17)+
                   (bytes[1]<<9)+
                   (bytes[2]<<1)+
                   (bytes[3]>>7);

      var encLon = ((bytes[3] & 0x7f)<<16)+
                   (bytes[4]<<8)+
                   bytes[5];

      var hdop = bytes[8]/10;
      var sats = bytes[9];

      maxHdop = 2;
      minSats = 5;

      if ((hdop < maxHdop) && (sats >= minSats)) {
        // Send only acceptable quality of position to mappers
        decoded.latitude = latSign * (encLat * 108 + 53) / 10000000;
        decoded.longitude = lonSign * (encLon * 215 + 107) / 10000000;
        decoded.altitude = ((bytes[6]<<8)+bytes[7])-1000;
        decoded.accuracy = (hdop*5+5)/10
        decoded.hdop = hdop;
        decoded.sats = sats;
      } else {
        decoded.error = "Need more GPS precision (hdop must be <"+maxHdop+
          " & sats must be >= "+minSats+") current hdop: "+hdop+" & sats:"+sats;
      }
      return decoded;
    }
      return null;
}
```

I do not send downlink data but if @disk91 or somebody could share It I could test it on ChirpStack.

hallard, 2022-09-21:
OMG just retrieved I had prepared this job in node red, with distance calculation and gateway counts

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

hallard, 2022-09-21:
And here the function code with data from chirpstack, don"t ask me were I found calculation distance function, don't remember, only I had to google, but looks like not so bad :-)

```js
function distance(lat1, lon1, lat2, lon2) {
    a1 = lat1 * Math.PI/180; // φ, λ in radians
    a2 = lat2 * Math.PI/180;
    d1 = (lat2-lat1) * Math.PI/180;
    d2 = (lon2-lon1) * Math.PI/180;

    a = Math.sin(d1/2) * Math.sin(d1/2) +
        Math.cos(a1) * Math.cos(a2) *
        Math.sin(d2/2) * Math.sin(d2/2);
    c = 2 * Math.atan2(Math.sqrt(a), Math.sqrt(1-a));

    return 6371e3 * c; // in metres
}

var b = msg.payload.data;
var data = {};
var txt = "";
var color = "red";

// Get gateways array
var gws = msg.payload.rxInfo;
var minrssi = -999;
var maxrssi = +999;

// Calculate min/max RSSI
for (i=0; i<gws.length; i++) {
    gw = gws[i];
	if (gw.rssi < maxrssi) { maxrssi = gw.rssi; }
	if (gw.rssi > minrssi) { minrssi = gw.rssi; }
}

// Only port with data
if (msg.payload.fPort == 1) {

    var lonSign = (b[0]>>7) & 0x01 ? -1 : 1;
    var latSign = (b[0]>>6) & 0x01 ? -1 : 1;
    var encLat = ((b[0] & 0x3f)<<17)+(b[1]<<9)+(b[2]<<1)+(b[3]>>7);
    var encLon = ((b[3] & 0x7f)<<16)+(b[4]<<8)+b[5];
    var hdop = b[8]/10;
    var sats = b[9];
    const maxHdop = 2;
    const minSats = 5;
    data.accuracy = (hdop*5+5)/10
    data.hdop = hdop;
    data.sat = sats;
    data.minrssi = minrssi;
    data.maxrssi = maxrssi;
    data.hotspot = gws.length;

    txt = "Hdop="+hdop+"   Sat="+sats;
    // Send only acceptable quality of position to mappers
    if ((hdop < maxHdop) && (sats >= minSats)) {
        // Get gateways array
        var mindist = 9999;
        var maxdist = 0;
        // Get node position
        data.lat = latSign * (encLat * 108 + 53 ) / 10000000;
        data.lon = lonSign * (encLon * 215 + 107) / 10000000;
        data.alt = ((b[6]<<8)+b[7])-1000;

        // Calculate distance between GW and node
        for (i=0; i<gws.length; i++) {
            gwlat = gws[i].location.latitude;
            gwlon = gws[i].location.longitude;
            node.warn("gwlat=" + gwlat + "  gwlon=" + gwlon);
    
            dist = distance(data.lat,data.lon,gwlat, gwlon);
            node.warn("distance=" + dist);
            if (dist>maxdist) {maxdist=dist;}
            if (dist<mindist) {mindist=dist;}
        }
        data.mindist = Number(mindist.toFixed(0));
        data.maxdist = Number(maxdist.toFixed(0));

        color ="green";
    }
    msg.payload = data;

} else if (msg.payload.fPort == 2) {
    txt = "Request downlink";
    color = "green";
    msg = null;
}

node.status({fill: color,text: txt});
return msg;
```

aruznieto, 2022-09-21:
For the distance you are using "Harvesine Function", this it would be the Encoder function or you mix both?

hallard, 2022-09-21:
For now only for decoding going to my dashboad, but will use these calculated data to send thru downlink according @disk91 documentation ASAP

aruznieto, 2022-09-21:
Ah! Ok, I calculate the distance after with Python because I need to analyze other parameters to.

hallard, 2022-09-21:
and here the working downlink (my node red specific but easy to adapt)

```js
var data = Buffer.alloc(6);
data[0] = msg.fc & 0xFF; // Frame Counter
data[1] = msg.payload.minrssi + 200;
data[2] = msg.payload.maxrssi + 200;
data[3] = (msg.payload.maxdist/250).toFixed(0);
data[4] = (msg.payload.mindist/250).toFixed(0);
data[5] = msg.payload.hotspot;

var newMsg = {}
newMsg.payload = {
    "confirmed": false,
    "fPort": 2,
    "data": Buffer.from(data,'hex').toString('base64')
}

newMsg.topic = msg.topicbase + "/command/down"

return newMsg;
```

works like a charm, special mention to @disk91, I feel so stupid not seeing sequenceID, because it's just frame count.

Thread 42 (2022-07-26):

device field tester with Kerlink Wansey

t0mZ4, 2022-07-26:
Hi there

we'd like to use the field tester with Kerlink WMC and TTI

We have the SEEED bundle.

Can we get the appKey and just add them to our network servers? Or do we need to flash different firmware?

Also, where do we get the appKey per-defined in the seeed bundle?

thanks alot!

disk91, 2022-07-26:
The version 1.9 of the firmware is compatible with TTN.
Then you need to configure TTN / TTI like it is described in the github project page.
If you have a seeed bundle, preconfigured with Helium credentials, you need to follow the github issue « change config to manage my own console account .. » you will lost the helium credentials forever.
Paul

_______________________________
Paul Pinault
http://www.disk91.com
http://www.twitter.com/disk_91

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

t0mZ4, 2022-08-03:
thanks alot! so I am trying to flash the firm to 1.9 [All Zone LoRa E5 Chassis (Seeed)](https://github.com/disk91/WioLoRaWANFieldTester/blob/master/binaries/WioLoRaWANFieldTester_LoRaE5_ALLZONE.uf2)

I see the arduino drive mounting, i drag the file, nothing happens. I am using linux.

anything else should do or try?

disk91, 2022-08-03:
I never try it with Linux.
You should try to flush the drive with sync command after your copy.

_______________________________
Paul Pinault
http://www.disk91.com
http://www.twitter.com/disk_91

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

t0mZ4, 2022-08-03:
managed to flash it fine from windows laptop, thanks!

Closed 2022-08-03.

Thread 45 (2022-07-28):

Wio Terminal Feild tester

DaGemm, 2022-07-28:
Received field tester from Seed Studio.  It worked fine for about 1 month and the screen stopped working. Both lights are on when connected to a usb c power cord.  Here was the email that I received from Seed Studio.

I see that the blue light of your device is flashing quickly. You can quickly dial the power button on the left twice to make the device enter the Bootloader mode, and then dial it again to exit the bootloader mode, and the device should be restored to normal.

If the firmware is still not displayed, please try to refresh the firmware according to this wiki. Remember to remove the Lorawan expansion board when refreshing the firmware and refresh wiO Terminal only.

When I use Audruino and try to select port with terminal I get this msg.

Programmer not responding.  Make sure that the firmwareupdater sketch is loaded on the board.

Any help would be appreciated.

disk91, 2022-07-28:
Did you try to enter dfu mode (double switch reset) the drag & drop the uf2 binary from github to the Arduino drive appeared when in dfu mode ?

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

disk91, 2022-08-15:
no more elements

Closed 2022-08-15.

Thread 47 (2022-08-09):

Does Discovery mode support TTN?

HAO156, 2022-08-09:
**Does Discovery mode support TTN? Or does it only support Helium?**
  When I use Discovery mode in the TTN environment.The link in the QR code cannot be accessed from a mobile phone or computer.
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

  Any help would be appreciated.

disk91, 2022-08-09:
Discovery mode is not yet implemented with TTN.
It will be added soon.

_______________________________
Paul Pinault
http://www.disk91.com
http://www.twitter.com/disk_91

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

HAO156, 2022-08-10:
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

HAO156, 2022-08-10:
Thank you for the reply. Looking forward to supporting the discovery mode of the TTN version.

Closed 2022-08-10.

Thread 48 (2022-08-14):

Discovery mode results deleting

Chris-S44, 2022-08-14:
Would it be possible to have an option to immediately delete discovery mode results and not to wait the 2hrs?
It would be nice to have for testing 2 different antennas back to back.

disk91, 2022-08-15:
There is currently no option for doing this.
This is a good feature request, I'll add this for the next updates

Chris-S44, 2022-08-15:
Thanks Paul. That will be great.

Closed 2022-10-11.

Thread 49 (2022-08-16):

Error compiling to Seeduino Wio Terminal

aruznieto, 2022-08-16:
Hi, I am trying to compile the software in Arduino. When I set the Role to Slave, I generate the binaries but Arduino´s Software return me this error:

"
collect2.exe: error: ld returned 1 exit status
Error compiling for Seeeduino Wio Terminal board.
"

This is my configuration on Tools

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

Thanks!

disk91, 2022-08-16:
What has been you solution ?

aruznieto, 2022-08-16:
Adding

`&& defined FALSE`

on "Libraries/Arduino15/packages/seeeduino/hardware/samd/1.8.2/library/Wire/Wire.cpp" next to

`#if WIRE_INTERFACES_COUNT > 1`

MaffooClock, 2025-06-24:
I just ran into this today (using PlatformIO).

The full error is about SERCOM functions being defined twice:
```text
.pio/build/seeed_wio_terminal/lib484/libWire.a(Wire.cpp.o): In function `SERCOM4_0_Handler':
Wire.cpp:(.text.SERCOM4_0_Handler+0x0): multiple definition of `SERCOM4_0_Handler'
.pio/build/seeed_wio_terminal/libFrameworkArduinoVariant.a(variant.cpp.o):variant.cpp:(.text.SERCOM4_0_Handler+0x0): first defined here
.pio/build/seeed_wio_terminal/lib484/libWire.a(Wire.cpp.o): In function `SERCOM4_1_Handler':
Wire.cpp:(.text.SERCOM4_1_Handler+0x0): multiple definition of `SERCOM4_1_Handler'
.pio/build/seeed_wio_terminal/libFrameworkArduinoVariant.a(variant.cpp.o):variant.cpp:(.text.SERCOM4_1_Handler+0x0): first defined here
.pio/build/seeed_wio_terminal/lib484/libWire.a(Wire.cpp.o): In function `SERCOM4_2_Handler':
Wire.cpp:(.text.SERCOM4_2_Handler+0x0): multiple definition of `SERCOM4_2_Handler'
.pio/build/seeed_wio_terminal/libFrameworkArduinoVariant.a(variant.cpp.o):variant.cpp:(.text.SERCOM4_2_Handler+0x0): first defined here
.pio/build/seeed_wio_terminal/lib484/libWire.a(Wire.cpp.o): In function `SERCOM4_3_Handler':
Wire.cpp:(.text.SERCOM4_3_Handler+0x0): multiple definition of `SERCOM4_3_Handler'
.pio/build/seeed_wio_terminal/libFrameworkArduinoVariant.a(variant.cpp.o):variant.cpp:(.text.SERCOM4_3_Handler+0x0): first defined here
collect2: error: ld returned 1 exit status
*** [.pio/build/seeed_wio_terminal/firmware.elf] Error 1
```

[Andrés's solution](#issuecomment-1217153673) is one of several ways to work around this.  Personally, I opted to just comment out those four definitions in [Wire.cpp](https://github.com/Seeed-Studio/ArduinoCore-samd/blob/d900ef7e959df763a4f56338183964739790f035/libraries/Wire/Wire.cpp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):
```cpp
// Line 306 - 311
  #if defined(__SAMD51__)
    // void WIRE1_IT_HANDLER_0(void) { Wire1.onService(); }
    // void WIRE1_IT_HANDLER_1(void) { Wire1.onService(); }
    // void WIRE1_IT_HANDLER_2(void) { Wire1.onService(); }
    // void WIRE1_IT_HANDLER_3(void) { Wire1.onService(); }
  #endif // __SAMD51__
```

I spent a few moments looking through the framework source to try to figure out why this was happening, but I gave up.  Also checked the [Seeed-Studio/ArduinoCore-samd](https://github.com/Seeed-Studio/ArduinoCore-samd) repo to see if anyone filed an issue for this, but there is none.  And I didn't do enough of my own homework to feel confident enough to open an issue.

Closed 2022-08-16.

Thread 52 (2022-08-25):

In Bootloader Mode

Meyblaubaer, 2022-08-25:
Hello,

i got the Seeed Package. After Updating to newest Firmware, The Device keeps booting in bootloader mode. I tried reinstalling firmware without success.

disk91, 2022-08-25:
That is strange and unusual. What firmware file did you flashed ?

_______________________________
Paul Pinault
http://www.disk91.com
http://www.twitter.com/disk_91

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

Meyblaubaer, 2022-08-26:
I was able to resolve the failure. It was because an faulty USB-C Cable, something went wrong. After uploading the Arduino "Blink Example" i was able to reupload with v1.3 and after this to the actual firmware. So i think it was a fault on my side, and this issue can be closed.

Closed 2022-08-26.

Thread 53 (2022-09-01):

Flashed 1.9 to Seeed Wio, stuck at startup screen

circuitmike, 2022-09-01:
I got the Seeed Wio bundle a while back and thought it was time for a firmware update. I flashed 1.9 (LoRaE5) to the Wio and now it simply hangs at the startup screen ("Wio LoRaWan Field Tester / Version v1.9 (LoRaE5) / WIO_FT_XXXXXXXXXX"). On the LoRa section there's a steady blue light and blinking red light. Any idea what might be going on?

I've got enough experience with embedded systems and the like to suspect the power issue, so I connected it to a power supply with plenty of current to spare and it still does the same thing.

disk91, 2022-09-01:
Hello,
That looks strange ...
I propose you flash it again ...

If you stil have the same issue please DM me on discord we will investigate this.

disk91, 2022-09-03:
any update ?

circuitmike, 2022-09-04:
Flashing again was the first thing I tried, and it did exactly the same thing. I'll try to find you on Discord one of these days when I've got some time.

circuitmike, 2022-10-21:
I'm leaving this closed because I finally figured out I had a hardware problem. The 5-way switch on the front of my Wio Terminal has failed and at least one of the 5 switches is constantly bouncing. This causes the device to go into and immediately out of configuration mode at startup, causing a boot loop. Once in a while if I hold the button just right I can get it to start up, but that's it. I got a new Wio Terminal but unfortunately I don't see a way to recover the app key provided by Seeed.

disk91, 2022-10-21:
I can help you on this. DM me on discord

Closed 2022-09-25.

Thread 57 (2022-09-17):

Decoding data from TTN to DataCake

richwriroo, 2022-09-17:
I am having trouble decoding data on DataCake

I have it set up on TTN which works great and have set up an integration with DataCake - I tried your decoder from your instructions with DataCake but don't get any correct values for any decoded values.  My integration webhook URL from TTN is https://api.datacake.co/integrations/lorawan/tti

Here is the decoder I am using:

`function Decoder(bytes, port) {
  var decoded = {};
  // avoid sending Downlink ACK to integration (Cargo)
  if (port === 1) {
    var lonSign = (bytes[0]>>7) & 0x01 ? -1 : 1;
    var latSign = (bytes[0]>>6) & 0x01 ? -1 : 1;

    var encLat = ((bytes[0] & 0x3f)<<17)+
                 (bytes[1]<<9)+
                 (bytes[2]<<1)+
                 (bytes[3]>>7);

    var encLon = ((bytes[3] & 0x7f)<<16)+
                 (bytes[4]<<8)+
                 bytes[5];

    var hdop = bytes[8]/10;
    var sats = bytes[9];

    var maxHdop = 2;
    var minSats = 5;

   // if ((hdop < maxHdop) && (sats >= minSats)) {
      // Send only acceptable quality of position to mappers
      decoded.latitude = latSign * (encLat * 108 + 53) / 10000000;
      decoded.longitude = lonSign * (encLon * 215 + 107) / 10000000;
      decoded.altitude = ((bytes[6]<<8)+bytes[7])-1000;
      decoded.accuracy = (hdop*5+5)/10
      decoded.hdop = hdop;
      decoded.sats = sats;
   // } else {
   //   decoded.error = "Need more GPS precision (hdop must be <"+maxHdop+
        " & sats must be >= "+minSats+") current hdop: "+hdop+" & sats:"+sats;
   // }
    return decoded;
  }
    return null;
}`

I get something that looks like this when debugging in DataCake:

`{
    "accuracy": 0.5,
    "altitude": -1000,
    "hdop": 0,
    "latitude": 5.3e-06,
    "longitude": 1.07e-05,
    "sats": 0
}`

disk91, 2022-09-17:
Please give me your original payload (before decodind)
I think this is a payload from a frame w/o gps position (basically full of 0)

richwriroo, 2022-09-18:
Hi Paul thanks for your speedy reply - here is a screen grab from TTN - I think you may be right about the payload being zero's - is my config wrong.
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

disk91, 2022-09-25:
You get 00.. when there is no GPS fix
You decoder should bypass this situation.

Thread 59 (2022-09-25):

How to use with TTN ?

vincegre, 2022-09-25:
Hi

I'm trying to follow your documentation on how to configure it with TTN but It's not enought detailesd:

`The Application EUI is by default set to 00..00, you need to change this to anything else to be able to configure your WioLoRaWanFieldTester.`

How do I change that in the Wio ? does it mean I have to recompile your code with my own AppEUI ?

Thanks

Vincèn

aruznieto, 2022-09-25:
Hi,

you can recompile writing your keys on [`keys.h` ](https://github.com/disk91/WioLoRaWANFieldTester/blob/master/keys.h) or restart the device pressing the 5 direction button. After 1 second after rebooting, stop pushing the 5 direction button, you should see the setup screen displayed and you can change the keys.

vincegre, 2022-09-25:
Thanks and i'll push an update on the documentation as it's missing that little detail ;) I just have one little issue: how do I change the AppKey as per default it's XXXXXXX: I tried left/right and also the top 3 buttons but none of them allows to edit it :(

vincegre, 2022-09-25:
Well I went to edit in code in Arduino IDE but I don't succeed to compile your project as downloaded from github :( I added missing libs in Arduino IDE and putted keys in keys.h but when I compile I get that :(

```
Compilation du croquis...
"/usr/bin/avr-g++" -c -g -Os  -std=gnu++11 -fpermissive -fno-exceptions -ffunction-sections -fdata-sections -fno-threadsafe-statics -Wno-error=narrowing -MMD -flto -mmcu=atmega328p -DF_CPU=16000000L -DARDUINO=10813 -DARDUINO_AVR_UNO -DARDUINO_ARCH_AVR   "-I/usr/share/arduino/hardware/arduino/avr/cores/arduino" "-I/usr/share/arduino/hardware/arduino/avr/variants/standard" "-I/usr/share/arduino/hardware/arduino/avr/libraries/SPI/src" "-I/home/vincen/Arduino/libraries/TFT_eSPI" "-I/home/vincen/Arduino/libraries/SparkFun_BQ27441_LiPo_Fuel_Gauge_Arduino_Library/src" "-I/home/vincen/Arduino/libraries/Adafruit_GPS_Library/src" "-I/usr/share/arduino/hardware/arduino/avr/libraries/SoftwareSerial/src" "-I/usr/share/arduino/hardware/arduino/avr/libraries/Wire/src" "-I/home/vincen/Arduino/libraries/FlashStorage/src" "-I/home/vincen/Arduino/libraries/QRCode/src" "/tmp/arduino_build_672054/sketch/LoRaCom.cpp" -o "/tmp/arduino_build_672054/sketch/LoRaCom.cpp.o"
/tmp/arduino_build_672054/sketch/LoRaCom.cpp: In function ‘bool processLoRaConfig()’:
/tmp/arduino_build_672054/sketch/LoRaCom.cpp:454:30: error: ‘class HardwareSerial’ has no member named ‘printf’
                 SERIALCONFIG.printf("%02X",loraConf.deveui[i]);
                              ^
/tmp/arduino_build_672054/sketch/LoRaCom.cpp:478:30: error: ‘class HardwareSerial’ has no member named ‘printf’
                 SERIALCONFIG.printf("%02X",loraConf.appeui[i]);
                              ^
/tmp/arduino_build_672054/sketch/LoRaCom.cpp:502:30: error: ‘class HardwareSerial’ has no member named ‘printf’
                 SERIALCONFIG.printf("%02X",loraConf.appkey[i]);
                              ^
/tmp/arduino_build_672054/sketch/LoRaCom.cpp:610:22: error: ‘NVIC_SystemReset’ was not declared in this scope
     NVIC_SystemReset();
                      ^
Utilisation de la bibliothèque SPI version 1.0 dans le dossier: /usr/share/arduino/hardware/arduino/avr/libraries/SPI
Utilisation de la bibliothèque TFT_eSPI version 2.4.72 dans le dossier: /home/vincen/Arduino/libraries/TFT_eSPI
Utilisation de la bibliothèque SparkFun_BQ27441_LiPo_Fuel_Gauge_Arduino_Library version 1.1.0 dans le dossier: /home/vincen/Arduino/libraries/SparkFun_BQ27441_LiPo_Fuel_Gauge_Arduino_Library
Utilisation de la bibliothèque Adafruit_GPS_Library version 1.7.0 dans le dossier: /home/vincen/Arduino/libraries/Adafruit_GPS_Library
Utilisation de la bibliothèque SoftwareSerial version 1.0 dans le dossier: /usr/share/arduino/hardware/arduino/avr/libraries/SoftwareSerial
Utilisation de la bibliothèque Wire version 1.0 dans le dossier: /usr/share/arduino/hardware/arduino/avr/libraries/Wire
Utilisation de la bibliothèque FlashStorage version 1.0.0 dans le dossier: /home/vincen/Arduino/libraries/FlashStorage
Utilisation de la bibliothèque QRCode version 0.0.1 dans le dossier: /home/vincen/Arduino/libraries/QRCode
exit status 1
Erreur de compilation pour la carte Arduino Uno

```

disk91, 2022-09-25:
Look like you did not followed the DEVELOPEMENT.md steps.
You don't really need to change the key.h file and recompile, the easiest way is to use the configuration over the serial port documented in SETUP.md

vincegre, 2022-09-25:
> Look like you did not followed the DEVELOPEMENT.md steps.
> You don't really need to change the key.h file and recompile, the easiest way is to use the configuration over the serial port documented in SETUP.md

Thanks a lot, I had missed these docs, sorry for that :( Unhappy I'll have try again an other day, looks like I'm very unlucky on technology is agains me today :( Compilation still doesn't work... The setup in the device itself at boot is not working for Appkey (the 2 other fields have no problem to be edited)... setup using serial through USB neither :(

disk91, 2022-09-25:
If you have *** for the appkey you first need to remove the bundle protection. For this take a look at the issues you will find one indicating how to do it. _______________________________Paul Pinaulthttp://www.disk91.comhttp://www.twitter.com/disk_91Le 25 sept. 2022 à 20:22, Vincèn ***@***.***> a écrit :

Look like you did not followed the DEVELOPEMENT.md steps.
You don't really need to change the key.h file and recompile, the easiest way is to use the configuration over the serial port documented in SETUP.md

Thanks a lot, I had missed these docs, sorry for that :( Unhappy I'll have try again an other day, looks like I'm very unlucky on technology is agains me today :( Compilation still doesn't work... The setup in the device itself at boot is not working for Appkey (the 2 other fields have no problem to be edited)... setup using serial through USB neither :(

—Reply to this email directly, view it on GitHub, or unsubscribe.You are receiving this because you commented.Message ID: ***@***.***>

vincegre, 2022-09-26:
> If you have *** for the appkey you first need to remove the bundle protection. For this take a look at the issues you will find one indicating how to do it.

Thanks, problem at least solved so could properly setup keys in device and now it sends payload at TTN ;)
It just doesn't map anything on ttnmapper and after a while displayed a QRCode on screen but none of my mobile devices recognise the code and accepts to scan it :(
I think I'm going to try to find out if someone published some codes for Wio Terminal to use it properly as a mapper as I have with Lilygo ESP/Lora devices !

Thanks again for all your support ;)

disk91, 2022-09-26:
The data are automatically reported to TTN Mapper if you correctly setup the integration to the dev.disk91.com backend.
To get the data displayed on TTN Mapper you need to have a GPS coverage and a suficient Hdop quality (precision) basically the GPS dot status must be green.

What you describe with the QR code is the Discovery Mode, is is use to get the global coverage around but sending multpli message. This is not a mapping feature. The discovery mode is not implemented on TTN yet. For mapping, just use the standard mode.

I don't know why the QR code not working in your case, It works well with many of the smartphone default photo app. You can eventually try with a dedicated QRCode reader app. Nothing specific with that QR.

vincegre, 2022-10-01:
> The data are automatically reported to TTN Mapper if you correctly setup the integration to the dev.disk91.com backend. To get the data displayed on TTN Mapper you need to have a GPS coverage and a suficient Hdop quality (precision) basically the GPS dot status must be green.

I double-checked the whole setup but I still get an error when outside with green GPS in TTN console when it sends payloads from Wio :( Webhook should be setup that way right ?
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
Next time I go out with Wio I'll capture exact error message in console to find out where problem is !

>
> What you describe with the QR code is the Discovery Mode, is is use to get the global coverage around but sending multpli message. This is not a mapping feature. The discovery mode is not implemented on TTN yet. For mapping, just use the standard mode.

Thanks for clarification ;)

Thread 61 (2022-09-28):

Feature Request: add a setting or default that makes the screen turn off after a certain timeout period

DeflateAwning, 2022-09-28:
It would be great if the screen naturally turned off after 5-10 minutes of no button presses, then turned back on when you press a button.

This setting could be enable by either:
* a config setting in the code (set at compile-time)
* a setting accessible on the device via the buttons, perhaps on a new "Settings" page

The screen uses energy and is very bright when there is no ambient light, so it would be much nicer if it didn't use power to be so intrusive.

disk91, 2022-09-28:
Hello,I’m planning to have a mode where button are not active and screen will be off for mapping during walk. So it will be in this. I dislike the auto off, as it exists on the rak version, setup page would be a harder work currently. Thank you for sharing this idea. _______________________________Paul Pinaulthttp://www.disk91.comhttp://www.twitter.com/disk_91Le 28 sept. 2022 à 22:55, DeflateAwning ***@***.***> a écrit :
It would be great if the screen naturally turned off after 5-10 minutes of no button presses, then turned back on when you press a button.
This setting could be enable by either:

a config setting in the code (set at compile-time)
a setting accessible on the device via the buttons, perhaps on a new "Settings" page

The screen uses energy and is very bright when there is no ambient light, so it would be much nicer if it didn't use power to be so intrusive.

—Reply to this email directly, view it on GitHub, or unsubscribe.You are receiving this because you are subscribed to this thread.Message ID: ***@***.***>

DeflateAwning, 2022-09-28:
That sounds great. With that enabled, how do you intend to be able to turn the screen back on? Will that be possible?

Also, it works better when you reply using the online Github interface instead of replying to the email. Your last response got a bit garbled.

disk91, 2022-10-09:
Added in master, will be in the coming release 1.10

Closed 2022-10-09.

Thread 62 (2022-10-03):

Configuring The Seed device

BrettOT, 2022-10-03:
You have probably been asked this before but i need some clarification.
1. I need to set the Application key on the device to get it to connect. When i look in the setup it is x'd out.
    I can set it using putty commands direct to the module but, when power is removed this does not save.
2. We are using AU915 and it always defaults to sub band 1. We use sub band 8 for most instances.
    As with the application key i can set the frequency band via direct putty commands to the module and then it works.
    Again though when power is removed, the unit defaults. Is there a way i can write the commands i want into the unit and have them
    stay there?

disk91, 2022-10-03:
Hello
1 - take a look at the issue #34
2 - The subband selected is currently 2 (channel 8 to 15), I can add a AU915_8 mode with subband 8 if you give me the corresponding channels. Please open a specific Issue with the request to track it and implement it in the coming release

disk91, 2022-10-11:
I need you feed back on subbands to include this in the version 1.10
sooner is better, later means next release

BrettOT, 2022-10-11:
It would be great if after selecting a country that has sub bands if you could then select the sub band you wish to use.
For the US and AU915 the sub bands are as follows:
1: 0-7, 64
2: 8-15, 65
3: 16-23, 66
4: 24-31, 67
5: 32-39, 68
6: 40-47, 69
7: 48-55, 70
8: 56-63, 71

The most common we use is AU915 sub band 8 however, can be any due to local interference.
We also use the US frequencies and sub bands as we sell our product all over the world as well as the EU and India frequencies.

The idea is to use this as a cheap portable test unit for field strength testing.

Regards,

Brett O'Toole
Communications Technician
Direct: +61358208846
Mobile: +61429138190
***@***.******@***.***>

Rubicon Water

Shepparton Office
1a Wheeler Street, Shepparton
Victoria 3630, Australia
Tel +61 3 5820 8800
www.rubiconwater.com
***@***.***

[LinkedIn]<https://www.linkedin.com/company/861213/>  [Facebook] <https://www.facebook.com/RubiconWater/>   [Instagram] <https://www.instagram.com/rubiconwater/>   [Twitter] <https://twitter.com/RubiconWater>   [YouTube] <https://www.youtube.com/user/rubiconsystemsau>

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

t0mZ4, 2022-10-19:
We'd like to +1 this and also have the sub selection for AU915 and US915
we use FSB8 in USA currently.

disk91, 2022-10-27:
This has been added to master
Please give a try before release creation

BrettOT, 2022-10-27:
Where do I get the code from?

Regards,

Brett O'Toole
Communications Technician
Direct: +61358208846
Mobile: +61429138190
***@***.******@***.***>

Rubicon Water

Shepparton Office
1a Wheeler Street, Shepparton
Victoria 3630, Australia
Tel +61 3 5820 8800
www.rubiconwater.com
***@***.***

[LinkedIn]<https://www.linkedin.com/company/861213/>  [Facebook] <https://www.facebook.com/RubiconWater/>   [Instagram] <https://www.instagram.com/rubiconwater/>   [Twitter] <https://twitter.com/RubiconWater>   [YouTube] <https://www.youtube.com/user/rubiconsystemsau>

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

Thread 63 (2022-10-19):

Add Sub-band selection to US915/AU915

t0mZ4, 2022-10-19:
referencing to https://github.com/disk91/WioLoRaWANFieldTester/issues/62

we'd like to request the option to select sub-band for AU915 and US915.

US915 -

Sub-Band 1 | 902.3 - 903.7 | 0-7
Sub-Band 2 | 903.9 - 905.3 | 8-15
Sub-Band 3 | 905.5 - 906.9 | 16-23
Sub-Band 4 | 907.1 - 908.5 | 24-31
Sub-Band 5 | 908.7 - 910.1 | 32-39
Sub-Band 6 | 910.3 - 911.7 | 40-47
Sub-Band 7 | 911.9 - 913.3 | 48-55
Sub-Band 8 | 913.5 - 914.9 | 56-63

Downlink sub-bands | Frequency range (MHz) | Channels
Downlink sub-band | 903 - 914.2 | 64-71

(reference: https://www.baranidesign.com/faq-articles/2019/4/23/lorawan-usa-frequencies-channels-and-sub-bands-for-iot-devices)

t0mZ4, 2022-10-25:
@disk91 any prediction on when this might be incorporated in a release?

kind regards

disk91, 2022-10-25:
Next release, in progress. I hope mid November

disk91, 2022-10-27:
It has been added to master.
Tester welcome

mcauser, 2022-11-21:
FYI AU915 as of 2022-11-17 has switched from FSB2 (ch8-15) to FSB6 (ch40-47). They're calling it Dual Plan so joins can overlap with AS923 devices.

deeeblack, 2022-11-21:
out of curiosity, how does one select the sub band? GUI or UART?

mcauser, 2022-11-21:
@deeeblack
GUI:
Reboot, hold middle d-pad button until you see text, release button
Presents the config screen
Use top buttons to cycle through zones

UART:
The zone is in the EEPROM at address 0x29
If you modify it, you'll need to recalculate the checksum at 0x03
Easier just using the GUI.

I just found/fixed a bug with AU915 sub band selection: https://github.com/disk91/WioLoRaWANFieldTester/pull/65
Missed 2 vars in the search/replace.

deeeblack, 2022-11-23:
Of note, I can only select +16dbm for power when using the AU915-6 setting. Can we max the power I think +22dbm on this setting?

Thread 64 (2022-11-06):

Wio-terminal does not boot with E5 firmware.

theoldinternet, 2022-11-06:
I have wio-terminal with the E5 Lorawan module.  The device does not boot after I drag the E5 .u2f over to the wio-terminal drive.
The RFM version will boot, but obviously lorawan won't work because it's not the correct module.

disk91, 2022-11-06:
Make sure you have selected the LORA E5 version and reload it. Sometime it crash on the first time, I already seen this.
Let me know if it continue. Eventually check if it works better with version 1.9 in case the new version 1.10 has some problem (I'll double check also)

theoldinternet, 2022-11-06:
I turns out that it will not boot while the lorawan module is attached.  If you attach it before you see the first graphic, it works fine

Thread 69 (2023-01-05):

strange GPS values when decoding on TTI

t0mZ4, 2023-01-05:
Hi there

We are getting the following decode from the unit:

```
 "received_at": "2023-01-05T15:06:38.354426073Z",
    "uplink_message": {
      "session_key_id": "AYWCUAnqwpnFZHaPH6h2SQ==",
      "f_port": 1,
      "f_cnt": 29,
      "frm_payload": "AAAAAAAAAAAAAA==",
      "decoded_payload": {
        "accuracy": 0.5,
        "altitude": -1000,
        "hdop": 0,
        "latitude": 0.0000053,
        "longitude": 0.0000107,
        "sats": 0
      },

```

using this decoder

```
function Decoder(bytes, port) {
  var decoded = {};

  var lonSign = (bytes[0]>>7) & 0x01 ? -1 : 1;
  var latSign = (bytes[0]>>6) & 0x01 ? -1 : 1;

  var encLat = ((bytes[0] & 0x3f)<<17)+
               (bytes[1]<<9)+
               (bytes[2]<<1)+
               (bytes[3]>>7);

  var encLon = ((bytes[3] & 0x7f)<<16)+
               (bytes[4]<<8)+
               bytes[5];

  var hdop = bytes[8]/10;
  var sats = bytes[9];

  const maxHdop = 2;
  const minSats = 5;

  if ((hdop < maxHdop) && (sats >= minSats)) {
    // Send only acceptable quality of position to mappers
    decoded.latitude = latSign * (encLat * 108 + 53) / 10000000;
    decoded.longitude = lonSign * (encLon * 215 + 107) / 10000000;
    decoded.altitude = ((bytes[6]<<8)+bytes[7])-1000;
    decoded.accuracy = (hdop*5+5)/10
    decoded.hdop = hdop;
    decoded.sats = sats;
  } else {
    decoded.error = "Need more GPS precision (hdop must be <"+maxHdop+
      " & sats must be >= "+minSats+") current hdop: "+hdop+" & sats:"+sats;
  }

  return decoded;
}
```

are we doing something wrong?

disk91, 2023-01-05:
Decoding is good... the GPS position is just unknown, so it reports 0 to identify this.
You can easily filter with the altitude (compared with a real position 0,0)
Your GPS is indoor or not yet sync with sat or having a GPS signal precision too low ( red / orange bullet on the screen)

Closed 2023-02-17.

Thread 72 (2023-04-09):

TTN webhook configuration for WioLoRaWANFieldTester

ffries, 2023-04-09:
Dear community,

Thank you for working on WioLoRaWANFieldTester.

I purchased a WioLoRaWANFieldTester field tester with battery from seeed.
After reinstalling firmware and setting GPS to 9600bds I could register on my TTN Gateway  and GPS worked.

I followed the instructions on the wiki, unfortunately, I don't understand how to set-up payload formatters for TTN mapper and TTN in general. I followed the instructions on the wiki without adding any formatters, unfortunately it replies "impossible to decode data". So I need to decode data ...

I found this webhook code and used it:

```
function Decoder(bytes, port) {
  var decoded = {};

  if ( port != 1 ) return decoded;

  var lonSign = (bytes[0]>>7) & 0x01 ? -1 : 1;
  var latSign = (bytes[0]>>6) & 0x01 ? -1 : 1;

  var encLat = ((bytes[0] & 0x3f)<<17)+
               (bytes[1]<<9)+
               (bytes[2]<<1)+
               (bytes[3]>>7);

  var encLon = ((bytes[3] & 0x7f)<<16)+
               (bytes[4]<<8)+
               bytes[5];

  var hdop = bytes[8]/10;
  var sats = bytes[9];

  const maxHdop = 2;
  const minSats = 5;

  if ((hdop < maxHdop) && (sats >= minSats)) {
    // Send only acceptable quality of position to mappers
    decoded.latitude = latSign * (encLat * 108 + 53) / 10000000;
    decoded.longitude = lonSign * (encLon * 215 + 107) / 10000000;
    decoded.altitude = ((bytes[6]<<8)+bytes[7])-1000;
    decoded.accuracy = (hdop*5+5)/10
    decoded.hdop = hdop;
    decoded.sats = sats;
  } else {
    decoded.error = "Need more GPS precision (hdop must be <"+maxHdop+
      " & sats must be >= "+minSats+") current hdop: "+hdop+" & sats:"+sats;
  }

  return decoded;
}
```

Also I wonder whether it is possible to use an experimental project in TTN Mapper for TTN. Can I integrate directly wih TTN Mapper and not disk91.

Kind regards,
Ffries

ffries, 2023-04-10:
Dear all,

After the wio field tester went off battery it rebooted and now it is connecting to my Helium Gateway. I don't want to connect to Helium gateways, for several reasons, including it ***might*** be a Ponsi Scheme.

When I click on survey it goes directly to Helium:
https://dev.disk91.com/ft/r/?x=48060962DB

How to remove Helium completely and revert to stock TTN network and TTN mappers? Shall I recompile the firmware. Can you provide an alternative firmware without Helium Bonzo-Bonzo.

Kind regards,
ffries

disk91, 2023-04-10:
The project, when connected to the backend dev.disk91.com automatically  pushes the data to ttnmapper.
For the rest, read the setup guide for TTN

ffries, 2023-04-12:
Thanks, closing the issue.

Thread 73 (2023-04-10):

Are TTN credentials lost when going off battery?

ffries, 2023-04-10:
Dear Disk91,

But what happens if battery goes off completely to 0%? All all TTN credentials lost and reverted to stock firmware? This is not a problem for Helium as credentials are hard-coded. But this is surely a problem for TTN. Is there a workaround other than clearing eprom? Do we need to recompile firmware?

All this is not very clear in a documentation, please make a clarification for newbies like me.

Kind regards,
Ffries

disk91, 2023-04-10:
No they are not, credentials are stored in NVM and LoRa-E5 EEPROM

ffries, 2023-04-12:
Thanks, closing the issue.

ffries, 2023-04-12:
I understand what is going on : credentials are locked. I tried to remove the lock and use the lastest firmware. It reboots but credentials are still locked.

There should be a way to store credentials from the UI or using AT commands.

ffries, 2023-04-12:
Dear Disk91,

Thank you for your answer. I am testing TTN coverage and I could connect to TTN using AT commands. This worked well. However, when switching-off WioLoRaWANFieldTester credentials are back to Helium.

Kind regards,
FFries

disk91, 2024-05-29:
Hello, sorry to answer so late, I missed your response.
You can follow the guide in documentation to unlock your device and definitly remove the seeed factory configuration.

disk91, 2024-05-29:
see: https://github.com/disk91/WioLoRaWANFieldTester/issues/34

Closed 2024-06-09.

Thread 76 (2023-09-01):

Enhancement: Settings Optimizer Mode

s33butler, 2023-09-01:
Feature Enhancement: Settings Optimizer Mode

For those of us that are a little green... an optimizer mode for settings would be nice.
Goal... recommend the best dBm and SF settings to the end-user based on running through each setting combination and comparing the results.

Channels EU868, US915, AU915, maybe others (I'm US915 so examples will be as such)
Power: dBm +22 to +02  (11 options)
Spread: SF 07 to 10 (4 options)
Modes to test: 44

Results to compare in order to offer best recommended testing mode settings.
Receive Strength: Rx Rssi 0 to -160
Receive Noise: Rx Snr 30 to -30
Retry 0 to 8
Transmit Strength: Tx Rssi 0 to -160
Hotspots: 0 to 20 count
Distance: 0 to 70 km

Some rating or scoring combination of the above to then recommend a best testing setting combo... i.e.  +16 dBm and SF 09

Or maybe a "Help Page" after the "Discovery Mode" that explains what each setting and result means... or maybe both.
dBm = Power decibel per milliwatt
SF = Spreading Factor the speed at which a signal's frequency changes across a channel's bandwidth.
RSSI = Transmit/Receive the received signal power in milliwatts and is measured in dBm.
SNR = Signal-to-Noise Ratio the ratio between the received signal strength and the signal strength of the background noise and interference.  (Close to 0 is best)
Retry = Tries again after each failure.
Hotspots = Number of hotspots seen by the tester based on the applied settings.
Distance = Distance of hotspots seen from the tester  based on the applied settings.
GPS = Current GPS values
Disco = Discovery Mode a map of discovered hotspots based on static setting (?)

Sorry if I got most of that wrong, I do enjoy the Wio Field Tester.
Thank you for your time and assistance

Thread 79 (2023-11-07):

My 2022 Field Tester Kit No Longer Sends

mheadpme, 2023-11-07:
I purchased WIO terminal SKU 114992777 from seeedstudio about a year ago.  It worked well!  I try it now and although I see a green Cnx after Join in manual mode.  I press button again and see green Tx, but I see only 0001 LOST, 0002 LOST, …  I never see a good transmission.  I suspect something about payment has gone bad although I doubt I've sent 200000 messages.   My tester is DevEUI 6081F948066862FE    AppEUI 6081F9EFD73D2E9A.    Question 1:  what must I do to get my tester going again?

I set up a Helium account following ConfigureHelium.md.  I can see the DevEUI and AppEUI for my device in this account.  I understand how to enter these into the tester at power on reset.  I can see the Helium App Key but I can not see how to enter this into the tester.  So I can not tell my tester to connect to my Helium account.  Question 2:  how do I input the App Key from Helium into the tester?

And Question 3:  Is this Github Issue the best place to ask stupid questions?

mheadpme, 2023-11-08:
Hi Paul

Thanks for quick reply!

Question 1:  I placed tester outside.  Set 8 dbm, SF 07, Retry 0, Auto 15 m.  See green GPS dot, green Cnx right away. Sure enough after many hours of red “x” in all displays I see green bars start and keep going for the last couple hours.  The power of patience!  Question 1 is answered.

Question 4: What caused this extreme latency?

Question 2:  I'll give up attempting my own Helium account since you indicate my tester should work with your account.  Question 2 is answered.

Question 3:  I am on Discord.    Please suggest a phrase to enter at Discord / Explore Discoverable Servers / Explore communities search box that will bring back a community(s) appropriate for obtaining answers to questions such as I asked here.   I'll post future questions there.

Thank you very much for supporting this useful Tester!

Closed 2024-05-29.

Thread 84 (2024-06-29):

chirpstack application template

disarticulate, 2024-06-29:
### got Chirpstack v4 running, but can't see to connect after setting up the  device in Arduino IDE:
Have A Wio Terminal Tester with https://wiki.seeedstudio.com/Wio_Terminal_LoRaWan_Chassis_with_Antenna-built-in_LoRa-E5_and_GNSS_EU868_US915
Cleared the Eprom with Clear_LoRaE5_eprom.uf2
Then setup as
```
16:08:24.697 -> LoRaWan configuration OKZONE: US915
16:16:25.394 -> OK
16:16:25.394 -> KO
16:16:25.394 -> KO
16:17:08.925 -> DEVEUI:2CF7F1C054100641
16:17:08.925 -> OK
16:19:44.497 -> APPKEY:564xxxxxxxxxxxxxxxxxxxxxxxxxxxxxxxxx
16:19:44.497 -> OK
16:20:11.858 -> APPEUI:D2BF2FD0069ED850
16:20:11.858 -> OK
16:20:11.894 -> LoRaWan configuration OK
```
Default settings I got from default templates looks like:
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

Device config:
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

I also setup a sensecap T1000 and that actived, so there's something I'm missing with setup conditions.

Any help would be appreciated. The gateway shouldn't matter but its Dragino DLOS8N

disk91, 2024-06-29:
Did you restarted the device after configuration ?
What do you see in LoRaWan Frame panel ?

disarticulate, 2024-06-29:
Yes, it's been restarted.

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+
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
Frames.
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

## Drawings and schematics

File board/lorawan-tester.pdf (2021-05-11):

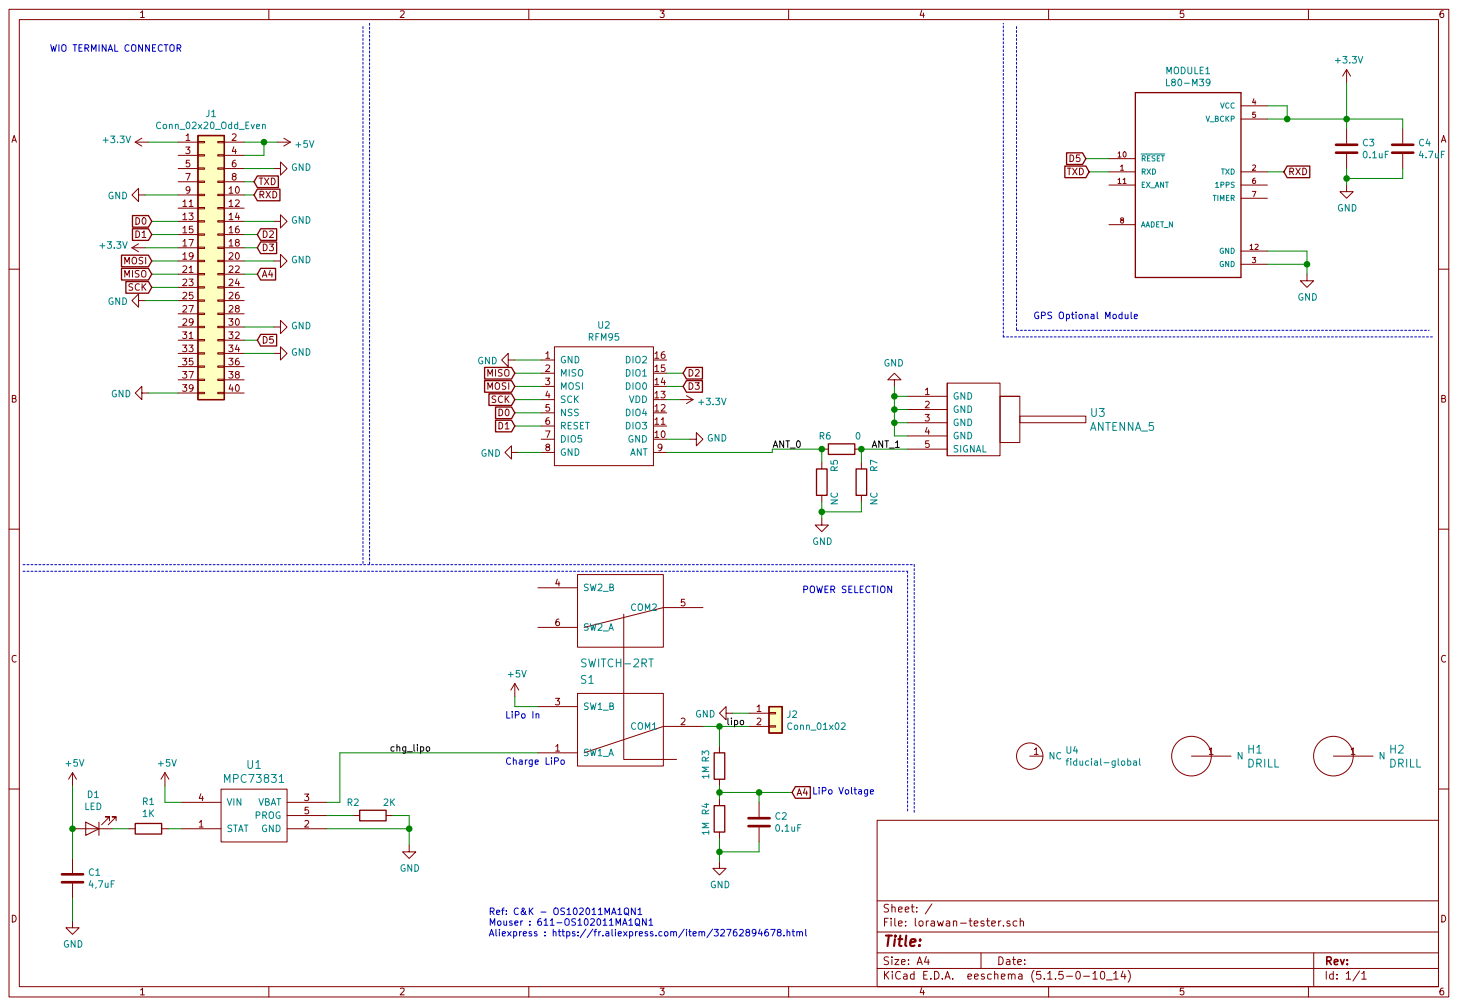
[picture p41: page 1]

4.7uF GND GND GND GND GND

GPS Optional Module POWER SELECTION

Id: 1/1 Title: File: lorawan-tester.sch Sheet: /

Ref: C&K - OS102011MA1QN1 Mouser : 611-OS102011MA1QN1 Aliexpress : https://fr.aliexpress.com/item/32762894678.html

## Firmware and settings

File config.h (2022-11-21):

/**
 * This file is part of Wio LoRaWan Field Tester.
 *
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
 *  Author : Paul Pinault (disk91.com)
 */  
#ifndef __CONFIG_H
#define __CONFIG_H

// 1 - select if you want some debug
//#define DEBUG
//#define DEBUGGPS
//#define DEBUGLORA
//#define DEBUGDATA
//#define NODISTANCECHECK

#define RFM95      0      // Make sure the board ROLE is MASTER
#define LORAE5     1      // Make sure the board ROLE is SLAVE

// 2 - select the target board, original one based on RFM95 or Seed LoRa E5 version
#define HWTARGET   LORAE5

#if HWTARGET == LORAE5
  #define CFG_anyZone
  #define WITH_GPS
  #define SERIALE5  Serial1
  #define WITH_LIPO
#endif

#if HWTARGET == RFM95
  #define RFM95_NSS_PIN   0
  #define RFM95_RST_PIN   1
  #define RFM95_DIO_0     3
  #define RFM95_DIO_1     2
  #define LIPO_ADC        A4

  // Offset to add when calculating battery percent remaining (in mv) 
  // Sometimes R/R divider may not accurate and battery voltage can be
  // shifted, so percent calculation may be wrong, this offset is added
  // on each calculation to fix it, best way to know this one if to fully
  // charge battery should be 4.2V, and read on GPS screen battery voltage
  // to view difference, in my case reading was 3950mV so added 250mV offset
  // it's empiric of course, not best but better than nothing
  // #define LIPO_OFFSET_MV 250 

// 3 - select possible options
  #define WITH_GPS
  #define WITH_LIPO
#endif

// 4 - Active on of the possible Splash screen ( or none or both )
#define WITH_SPLASH         1
#define WITH_SPLASH_HELIUM  1   
//#define WITH_SPLASH_TTN     1
//#define JUSTCLEAN


#define VERSION "v1.12a"

#ifdef DEBUG
  #define LOGLN(x)  Serial.println x
  #define LOG(x) Serial.print x
  #define LOGF(x) Serial.printf x
#else
  #define LOGLN(x) 
  #define LOG(x)
  #define LOGF(x)
#endif

#ifdef DEBUGLORA
  #define LOGLORALN(x)  Serial.println x
  #define LOGLORA(x) Serial.print x
  #define LOGLORAF(x) Serial.printf x
#else
  #define LOGLORALN(x) 
  #define LOGLORA(x)
  #define LOGLORAF(x)
#endif

#ifdef DEBUGGPS
  #define LOGGPSLN(x) Serial.println x
  #define LOGGPS(x) Serial.print x
  #define LOGGPSF(x) Serial.printf x
#else
  #define LOGGPSLN(x) 
  #define LOGGPS(x)
  #define LOGGPSF(x)
#endif

#define SERIALCONFIG  Serial

#define NONDCZONE_DUTYCYCLE_MS 25000                     // Fair use and preserve DCs in MS
#define MAXNONMOVEMENT_DURATION_MS ( 30 * 60 * 1000 )    // Fair use - downgrade period when the position of the device is unchanged
#define MAXDOWNLINKRETRY 2                               // try to empty the downlink queue, stop after this amount of trial

bool readConfig();
void storeConfig();
bool storeConfigToBackup();
bool readConfigFromBackup();
void clearBackup();

#if HWTARGET == LORAE5
  void processLoRaE5GpsFix();
#endif

#endif // __CONFIG_H

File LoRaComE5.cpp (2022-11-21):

/**
 * This file is part of Wio LoRaWan Field Tester.
 *
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
 *  Author : Paul Pinault (disk91.com)
 */  
#include <Arduino.h>
#include "config.h"
#if HWTARGET == LORAE5
#include "LoRaCom.h"
#include "testeur.h"
#include "ui.h"

#define DEFAULT_TIMEOUT 2000
#define PASSTHROUGH_TIMEOUT 15000
#define JOIN_TIMEOUT 12000
#define SEND_TIMEOUT_BASE 7000
#define MAX_RESP_BUF_SZ  64
#define MAX_DOWNLINK_BUF 32

typedef struct {
  char bufOkResp[MAX_RESP_BUF_SZ];
  char bufErrResp[MAX_RESP_BUF_SZ];
  char bufEnding[MAX_RESP_BUF_SZ];
  char bufResponse[2*MAX_RESP_BUF_SZ];
  uint8_t bufDownlink[MAX_DOWNLINK_BUF];
  bool withEndingCondition;
  uint16_t respIndex;
  bool runningCommand;
  uint32_t startTime;
  uint32_t elapsedTime;
  uint32_t maxDuration;
  bool statusCommand;
  bool isJoining;
  bool hasJoined;
  int8_t lastDr;
  int8_t lastPower;
  int8_t lastRetry;
  bool hasAcked;
  bool downlinkPending;
  bool gotDownlink;
  uint32_t lastSendMs;
  uint32_t estimatedDCMs;
  bool (*lineProcessing)(void);
  uint8_t currentSeqId; // simplified
  float lastRssi;
  float lastSnr;
  uint8_t tmpInt8;
} loraE5_t;
loraE5_t loraContext;

bool processATResponse();

/**
 * Execute an AT command with a timeout
 * Search for okResp or errResp to determine is the command is a success or a fail
 * When ending is defined, it search for this sentence to consider end of response
 * Can be executed as a sync or async command.
 * okResp and errResp can use joker char with '*'
 * The okResp / errResp surch is a startsWith operation
 * When lineProcessing function is given, each of the line are transmitted to a custom function for processing, when return true, processing is stopped (like for ending)
 */
bool sendATCommand(const char * cmd, const char * okResp, const char * errResp, const char * ending, uint32_t timeoutMs, bool async, bool (*lineProcessing)(void) ) {
  if ( loraContext.runningCommand ) {
    LOGLN(("LoRa already processing"));
    return false;
  }
  loraContext.runningCommand = true;
  loraContext.startTime = millis();
  loraContext.maxDuration = timeoutMs;
  strcpy(loraContext.bufOkResp,okResp);
  strcpy(loraContext.bufErrResp,errResp);
  if ( ending != NULL && strlen(ending) > 0 ) {
    strcpy(loraContext.bufEnding,ending);
    loraContext.withEndingCondition = true;
  } else {
    loraContext.withEndingCondition = false;
  }
  loraContext.respIndex = 0;
  loraContext.lineProcessing = lineProcessing;
  
  SERIALE5.printf("%s\r\n",cmd);
  LOGLORALN((cmd));
  bool done = false;
  if ( !async ) {
    while ( ! processATResponse() );
    return loraContext.statusCommand;
  }
  return true;
}

// compare str with a ref string and return true when
// str starts with ref. Case sensitive. ref can contain
// a joker char *
bool startsWith(const char * str, const char * ref) {
  if ( strlen(str) >= strlen(ref) ) {
    // possible 
    int i;
    for ( i = 0 ; i < strlen(ref) ; i++ ) {
        if ( ref[i] != '*' && str[i] != ref[i] ) {
                break;
        }
    }
    return ( i == strlen(ref) );
  }
  return false;
}

// search for index of char after the ref string in the str
// return -1 when not found
int indexOf(const char * str, const char * ref) {
  
  int sStr = strlen(str);
  int sRef = strlen(ref);
  int e;
  for ( int d = 0 ; d < (sStr - sRef) ; d++ ) {
    if ( str[d] == ref[0] ) {
      for ( e = 1 ; e < sRef ; e++ ) {
        if ( str[d+e] != ref[e] ) {
          break;
        }
      }
      if ( e == sRef ) {
        return d+e;
      }
    }
  }
  return -1;
 
}


/**
 * Process command response
 * return true when nothing more to be done
 */
bool processATResponse() {

  // nothing to be done
  if ( !loraContext.runningCommand ) return true;

  // manage timeout
  uint32_t duration  = millis() - loraContext.startTime;   // overflow after 50D. risk taken.
  if ( duration > loraContext.maxDuration ) {
    loraContext.runningCommand = false;
    loraContext.statusCommand = false;
    LOGLN(("LoRa timeout"));
    return true;
  }
  // process serial line response
  while ( SERIALE5.available() > 0 ) {
      char c = SERIALE5.read();
      if ( (c == '\0' || c == '\r' || c == '\n' ) ) {
        if ( loraContext.respIndex > 0 ) {
          // process line response
          loraContext.bufResponse[loraContext.respIndex] = '\0';
          LOGLORALN((loraContext.bufResponse));
          int i;
          if ( loraContext.lineProcessing != NULL ) {
            if ( loraContext.lineProcessing() ) {
              loraContext.runningCommand = false;
              loraContext.respIndex = 0;
              return true;
            }
          }
          if ( strlen(loraContext.bufErrResp) > 0 && startsWith(loraContext.bufResponse,loraContext.bufErrResp) ) {
              // Error String found
              if ( ! loraContext.withEndingCondition ) {
                loraContext.runningCommand = false;
              }
              loraContext.statusCommand = false;
              loraContext.respIndex = 0;
              LOGLN(("LoRa Error"));
              return !loraContext.withEndingCondition;
          }
          if ( strlen(loraContext.bufOkResp) > 0 && startsWith(loraContext.bufResponse,loraContext.bufOkResp) ) {
              // Success String found
              if ( ! loraContext.withEndingCondition ) {
                loraContext.runningCommand = false;
              }
              loraContext.statusCommand = true;
              loraContext.respIndex = 0;
              return !loraContext.withEndingCondition;
          }
          if ( loraContext.withEndingCondition && startsWith(loraContext.bufResponse,loraContext.bufEnding) ) {
              // this is the end
              loraContext.runningCommand = false;
              loraContext.respIndex = 0;
              return true;
          }
        }
        loraContext.respIndex = 0;
      } else {
        if ( loraContext.respIndex < 2*MAX_RESP_BUF_SZ ) {
          loraContext.bufResponse[loraContext.respIndex] = c;
          loraContext.respIndex++;    
        } else {
          LOGLN(("Response size overflow"));
          loraContext.respIndex = 0;
        }
      }
  }
  return false;
}
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

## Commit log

2021-04-21 Add different information graph and automatic / manual mode also improve the connection display and fixed the repeat counter
    [LoRaCom.cpp, ui.cpp]
2021-04-22 Now supports backend loopback communication to display the Network side informations
    Some refresh bug to investigate.
    [LoRaCom.cpp, ui.cpp]
2021-04-23 Fix communication & downlink report + add splash screen for helium & ttn
    [LoRaCom.cpp, config.h, ui.cpp]
2021-04-27 Add schematics and blog post documentation link
2021-05-11 Rename the ino file to match the project name and rename Free_Fonts.h as it was not correctly processed by Arduino compiler
    [ui.cpp]
2021-05-11 Add board schematic
2021-05-19 Add LiPo battery status display and alert when switch not correctly set
    [ui.cpp]
2021-05-19 Add Gerber files
2021-05-19 Document the board and bom
2021-05-19 fix LiPo voltage conversion
2021-05-19 fix lipo level
2021-05-20 Improve battery indicator
2021-05-20 Update BOM
2021-05-24 add Seeed link + fix altitude in frame reported
2021-05-25 Add enclosure & link to kits
    [Bottom_Side.stl, FieldTesterEnclosure.FCStd, Top_Side.stl]
2021-05-30 typo in bom
2021-06-20 Fix SPLASH defines to support 0 for disable
    [ui.cpp]
2021-08-11 Add documentation to setup device credentials
2021-09-22 Add support for LoRaWan Chassis
2021-09-23 Fix Duty Cycle calculation after retries consideration but missing increment. Binary generation fixed for US915 and AS923
    [LoRaComE5.cpp, config.h]
2021-09-29 Add battery status on battery chassis and optimize GPS UI optimize boot process
2021-09-29 Improve battery status reporting
2021-09-29 Fix missing AU915 setup from serial line
    [LoRaCom.cpp]
2021-09-29 Improve Tx power support based on platform capacity + fix missing IN865 power limitation
2021-09-29 fix 2 RFM95 bugs 1 preventing to compile, other to link
    [LoRaCom.cpp]
2021-09-29 revert back to ESP8266
    [gps.cpp]
2021-09-29 revert back log defines and make little change on block fix made
    [LoRaCom.cpp, config.h]
2021-09-30 Rework GPS code to fix unstable init and fix difficulties
    [gps.cpp]
2021-09-30 Fix GPS timings for RFM95/L86 version / Accept lower hdop
    [config.h, gps.cpp]
2021-10-01 Fix GPS randomly starting correctly
    [gps.cpp]
2021-10-13 Multiple evolution for preparing 1.0
    - Select sub-band for US915 and AU915
    - Improve no data display
    - improve loading UI
    - Add sample data test to debug screen display
    - Add hotspot distance display
2021-10-14 fix starting point for graph to avoid traces
    [ui.cpp]
2021-10-18 Display NMEA when not fixed with DEBUGGPS
    [gps.cpp, ui.cpp]
2021-10-18 fixed wrong display when fixed in debug
    [ui.cpp]
2021-11-04 update version for printing
2021-11-04 quick fix SNR overflow
    [ui.cpp]
2021-11-04 refacto GPS display to fix initial print and simplify code
    [gps.cpp, ui.cpp]
2021-11-06 change the max power for AS923 + remove the power mask for LoRa E5 as this was a specific fix for RFM95
2021-12-03 display battery values
2021-12-03 created percent approx for lipo
2021-12-22 Release v1.2
    Add ability to setup the zone in a second step when credentials are setup in a factory
    Add error display when the LoRa board is not connected to device
    [LoRaCom.cpp, LoRaComE5.cpp, config.h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]
2022-01-02 In progress
    - Fix error in computation of the duty cycle
    - Improve title display
    - Add config storage in E5 to allow firmware update
    [LoRaComE5.cpp, ui.cpp]
2022-01-02 Fix - error in the way the power is initially setup when the zone is unseted
2022-01-26 change non DC interframe time, display device name on startup, battery display improvement when chassis not connected
2022-01-29 Publish version 1.4 including
    - Battery status now empty when Wio Battery chassis non connected
    - Non duty cycle zone now have 25s Duty Cycle instead of 5s ( preserve backend capacities )
    - Display the wio terminal name on boot (based on DEVEUI)
    - Reduce communication period when the device is out of GPS coverage or not moving
    - fix the bar display with last value displayed on first column
    [LoRaComE5.cpp, config.h, gps.cpp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]
2022-02-01 added LIPO_OFFSET_MV option
2022-02-01 globally option LIPO_OFFSET_MV
2022-02-04 Fix a few typos
    [LoRaCom.cpp, LoRaComE5.cpp, gps.cpp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]
2022-02-06 Add the fix for the GPS default speed issue
    Fix - RFM95 initial setup did not set the Region correctly
    [LoRaComE5.cpp, config.h, fixGpsSpeedIssue.cpp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]
2022-02-06 Reduce com speed automatically when not moving for more than 30Min
    Fix RFM95 compilation and initial setup
    [config.h, fixGpsSpeedIssue.cpp, gps.cpp]
2022-04-26 Fix some value bundaries
    [LoRaComE5.cpp, ui.cpp]
2022-06-26 Fix the power & SF display on first init
    [ui.cpp]
2022-07-17 Make sure the downlink empty loop will not be too long and continue to get mapping.
    [config.h]
2022-07-18 Fix the SF10 size related to MAC Command for US915 preventing communications. Also force setting of the DR after JOIN as this one has been a bit strange on E5 and fix the Join estimate DC duration fo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
    [LoRaComE5.cpp]
2022-09-25 minor clarifications about setup
    clarifications about how to get/setup Lora keys in Wio Terminal and also which device to select in TTN console.
2022-10-09 Add lock modes & screen off mode to map without unexpected key pressed and power saving
2022-10-11 Addition of backend button to clear cache of the discovery mode
2022-10-27 fix ino file name
    [WioLoRaWANFieldTester.ino]
2022-11-05 fix potential lock when starting disco when in mode EMPTY_DOWNLINK
    [WioLoRaWANFieldTester.ino]
2022-11-05 make sure device has join before going to disco wait
2022-11-21 Fix AU915 subband selection
    [LoRaComE5.cpp]
2022-11-21 Fix UA915 bug in band selection
    [config.h]

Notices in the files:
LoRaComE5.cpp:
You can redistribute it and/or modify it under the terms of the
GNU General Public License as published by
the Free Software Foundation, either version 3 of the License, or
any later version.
